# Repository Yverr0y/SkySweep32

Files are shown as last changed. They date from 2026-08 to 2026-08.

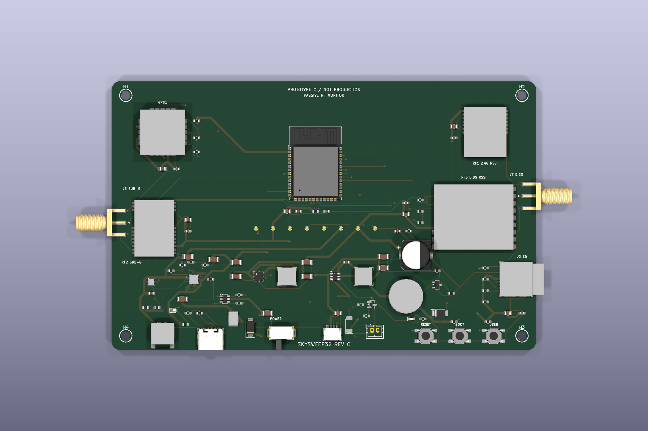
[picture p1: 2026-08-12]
hardware/rev_c/previews/pcb_top.png

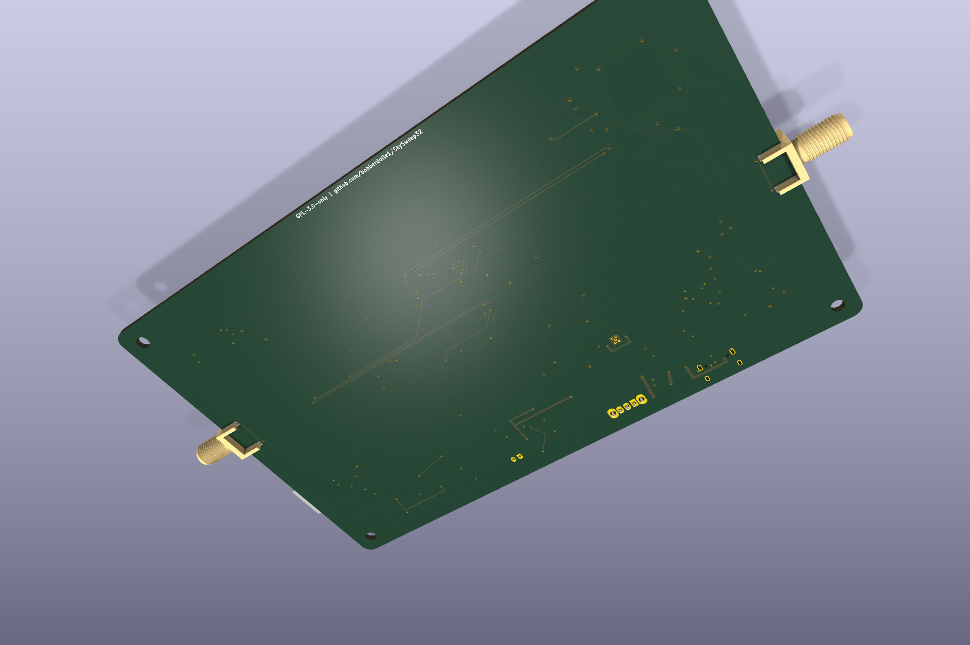
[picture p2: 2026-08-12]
hardware/rev_c/previews/pcb_bottom.png

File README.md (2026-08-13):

# SkySweep32




**Open-source passive multi-band RF monitoring system** — 855–925 MHz, 2.4 GHz,
and 5.8 GHz energy/activity observation; GNSS; microSD logging; local display,
web UI, and networked experiments.

> **Current maturity: READY FOR FIRST PHYSICAL PROTOTYPE — NOT PRODUCTION VALIDATED.**
> Rev C is the current hardware. No Rev C board has been physically assembled,
> bench-tested, RF-characterized, compliance-tested, or field-tested.

SkySweep32 is a **system**, not merely a PCB: passive RF frontends feed an
ESP32-S3 acquisition core; the core drives local logging, GNSS, UI, alerts, web
access, and experimental node events. It does not jam, inject RF, deny GPS,
identify transmitters from RSSI, or provide directional finding.

## Quick links

| Start here | What it answers |
| --- | --- |
| [Get started](docs/en/getting-started.md) · [Начало работы](docs/ru/getting-started.md) | Build the only active firmware target; avoid historical assets |
| [Build Rev C](BUILD_THIS.md) | Exact manufacturing, assembly, and prototype-evidence route |
| [System](docs/en/system.md) · [Система](docs/ru/system.md) | Implemented, experimental, and roadmap capabilities |
| [Current hardware](docs/en/hardware.md) · [Аппаратура](docs/ru/hardware.md) | Rev C PCB, enclosure, manifest, and boundaries |
| [Software](docs/en/software.md) · [Прошивка](docs/ru/software.md) | RF monitoring, logging, UI, protocol parsers, networking |
| [Validation](docs/en/validation.md) · [Валидация](docs/ru/validation.md) | CAD/build evidence versus physical proof |
| [Roadmap](docs/en/roadmap.md) · [План](docs/ru/roadmap.md) | Evidence-driven next work |

## Current system

```text
855–925 MHz / 2.4 GHz / 5.8 GHz passive inputs
             ↓ relative energy/activity
        ESP32-S3 Rev C core
  ┌──────────┼─────────────────────────────┐
  GNSS   microSD logs   OLED/alerts   local Web UI
                    └── ESP-NOW experiments
```

| Capability | Current truth |
| --- | --- |
| Three passive RF observation paths | Implemented in source and Rev C design; RF performance awaits Prototype #1 |
| GNSS, SD logging, OLED, buttons, power telemetry | Implemented in source/design; needs first-board bring-up |
| Wi-Fi web UI, BLE receive, ESP-NOW | Builds; experimental on unassembled Rev C |
| Remote ID, MAVLink, CRSF | Parser/receive infrastructure; no standards or over-air claim |
| LoRa/Meshtastic, TinyML, ATAK, 5.8 video | Not current Rev C capabilities; roadmap only |

## Build and validate

```bash
pio run -e esp32s3_rev_c_passive
make -C test/host
python tools/hardware/verify.py
```

The first two commands exercise source contracts; the hardware command rebuilds
CAD/fabrication checks when its toolchain is available. None proves physical
performance. Follow the [Prototype #1 checklist](hardware/rev_c/PROTOTYPE_VALIDATION_CHECKLIST.md) after assembly.

## Project structure

- `src/` — ESP32-S3 firmware and passive-monitor drivers.
- `hardware/rev_c/` — current canonical KiCad, manifest, fabrication, enclosure, and evidence.
- `tools/hardware/` — reproducible Rev C engineering tools.
- `test/host/` — bounded protocol/parser tests.
- `docs/en/`, `docs/ru/` — product, build, software, validation, and roadmap docs.
- `docs/history/` — deliberately non-orderable Rev A/Rev B context.

## Community and legal boundary

Use [Discussions](https://github.com/bobberdolle1/SkySweep32/discussions) for questions and ideas; use [Issues](https://github.com/bobberdolle1/SkySweep32/issues) for reproducible bugs and Prototype #1 evidence. Operate only under applicable spectrum, privacy, aviation, and data laws. Read [SECURITY.md](.github/SECURITY.md), [CONTRIBUTING.md](CONTRIBUTING.md), and the [GPL-3.0 license](LICENSE).

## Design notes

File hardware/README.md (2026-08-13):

# SkySweep32 Hardware Revisions

## Canonical current design: Rev C

**Rev C status: READY FOR FIRST PHYSICAL PROTOTYPE — NOT PRODUCTION
VALIDATED.**

[`rev_c/`](rev_c/) is the only current hardware source. Its native KiCad 10
schematic and four-layer PCB, exact BOM, generated fabrication package, complete
PCBA STEP, co-designed enclosure, firmware pin contract, and validation evidence
are documented in [`rev_c/README.md`](rev_c/README.md).

Run the complete local gate from the repository root:

```bash
python hardware/verify.py
```

Passing this command establishes encoded ERC/DRC, CAD interference, export, and
firmware-build results. It does not establish an assembled, bench-tested,
field-tested, compliant, or production-validated device.

## Revision authority

| Revision | Status | Use |
|---|---|---|
| [`rev_c/`](rev_c/) | Ready for first physical prototype | Current engineering source and prototype fabrication package |
| [`rev_b/`](rev_b/) | Failed/unverified; do not order | Historical audit evidence only |
| Root-level files / [`enclosures/`](enclosures/) | Legacy Rev A; do not order | Historical issue #10 parser-compatibility artifacts only |

Rev C is electrically, mechanically, and firmware incompatible with Rev A and
Rev B. No legacy pin map, BOM, enclosure, generated report, or manufacturing
file applies to Rev C.

## Historical material

Everything outside `rev_c/` is retained only for historical review:

- [`rev_b/`](rev_b/) documents the failed/unverified Rev B baseline;
- root-level KiCad 6 files, generators, previews, and [`enclosures/`](enclosures/)
  are legacy Rev A / issue #10 parser-compatibility artifacts.

They are **not** part of any Rev C manufacture, assembly, enclosure, pin-map,
or firmware workflow. Do not regenerate them unless investigating history. The
current build path is [`rev_c/BUILD.md`](rev_c/BUILD.md).

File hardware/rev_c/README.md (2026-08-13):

# SkySweep32 Rev C hardware

> **READY FOR FIRST PHYSICAL PROTOTYPE — NOT PRODUCTION VALIDATED.**
> The package below is the only current fabrication/assembly source. Reproduce
> its gates before ordering and then complete the physical validation checklist.

Rev C is a four-layer, 150 × 95 mm passive-monitor carrier around an
ESP32-S3-WROOM-1-N16R8. Fitted receive paths cover 855–925 MHz (E07/CC1101),
2.4 GHz (E28/SX1281), and 5.8 GHz (RX5808 RSSI). It also includes SAM-M10Q
GNSS, microSD, OLED harness, local controls/alerts, USB-C, a protected 1S battery
path, and ESP32-S3 Wi-Fi/BLE/ESP-NOW.

## Build / order route

1. Read [`BUILD.md`](BUILD.md) for exact tools and fabrication/assembly files.
2. Use [`hardware_manifest.json`](hardware_manifest.json) for exact parts,
   footprints, pins, DNP choices, supplier/manufacturer references, and envelopes.
3. Use [`manufacturing/`](manufacturing/) only after reproducing the current
   evidence with [`tools/hardware/verify.py`](../../tools/hardware/verify.py).
4. Follow [`ASSEMBLY_AND_BRINGUP.md`](ASSEMBLY_AND_BRINGUP.md).
5. Do not advance status without every applicable item in
   [`PROTOTYPE_VALIDATION_CHECKLIST.md`](PROTOTYPE_VALIDATION_CHECKLIST.md).

## Canonical sources and derived evidence

| Authority | Files |
| --- | --- |
| Electrical / PCB | `skysweep32_rev_c.kicad_sch`, `skysweep32_rev_c.kicad_pcb` |
| Exact integration contract | `hardware_manifest.json` |
| Firmware pin/profile contract | generated `src/generated/hardware_rev_c.h`, `boards/skysweep32_rev_c.json` |
| Fabrication package | `manufacturing/` |
| Enclosure and assembly geometry | `enclosure/` |
| Machine evidence | `validation/`, regenerated by `tools/hardware/verify.py` |

`3dmodels/*_ENVELOPE.step` are labelled mechanical-envelope approximations unless
the manifest says otherwise. They are fit constraints, not manufacturer CAD proof.

## Validation boundary

Current evidence records zero current ERC errors/warnings, zero DRC violations,
zero unexpected PCB pads, and CAD enclosure collision/service checks. It does
**not** establish charging safety, antenna behavior, RF sensitivity/selectivity,
GNSS performance, USB integrity, enclosure tolerances, reliability, compliance,
or production yield. Those require an assembled board and measurements.

See [`ROADMAP.md`](ROADMAP.md), the root [`BUILD_THIS.md`](../../BUILD_THIS.md),
and [project documentation](../../docs/en/README.md).

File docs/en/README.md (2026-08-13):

# SkySweep32 documentation

SkySweep32 is an open-source **passive multi-band RF monitoring system**. Rev C
is its current physical implementation, not the product definition.

> **Current maturity: READY FOR FIRST PHYSICAL PROTOTYPE.** Rev C has CAD and
> build evidence, but no assembled board, RF characterization, compliance
> result, reliability result, or field result.

## Read in this order

1. [System overview and capability matrix](system.md)
2. [Get started](getting-started.md)
3. [Software and local web UI](software.md)
4. [Current Rev C hardware and enclosure](hardware.md)
5. [Validation and physical-test boundary](validation.md)
6. [Development and contribution](development.md)
7. [Roadmap](roadmap.md)

[Русская документация](../ru/README.md) · [Project website](https://bobberdolle1.github.io/SkySweep32/) · [Source repository](https://github.com/bobberdolle1/SkySweep32)

## Source-of-truth policy

| Fact | Authority | Derived material |
| --- | --- | --- |
| Rev C circuit and geometry | KiCad schematic/PCB plus manufacturer data | fabrication package, STEP, reports |
| Rev C fitted parts and pins | `hardware/rev_c/hardware_manifest.json` | generated firmware header, board definition, BOM |
| Firmware behavior | C++ source built as `esp32s3_rev_c_passive` | binary, local web UI |
| CAD/build evidence | reproducible tools and reports | human summaries |
| Product explanation | these EN/RU documents | website and README links |

A report, render, or successful compile is not proof of RF performance or a
physical prototype result.

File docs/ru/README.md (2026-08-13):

# Документация SkySweep32

SkySweep32 — open-source система **пассивного многодиапазонного RF-мониторинга**.
Rev C — её текущая физическая реализация, а не определение всего проекта.

> **Текущая зрелость: ГОТОВ К ПЕРВОМУ ФИЗИЧЕСКОМУ ПРОТОТИПУ.** Для Rev C есть
> CAD и build-доказательства, но нет собранной платы, RF-характеризации,
> результатов соответствия нормам, надёжности или полевых испытаний.

## Читайте в таком порядке

1. [Система и матрица возможностей](system.md)
2. [Начало работы](getting-started.md)
3. [Прошивка и локальный Web UI](software.md)
4. [Текущая аппаратура Rev C и корпус](hardware.md)
5. [Валидация и граница физических доказательств](validation.md)
6. [Разработка и вклад](development.md)
7. [Дорожная карта](roadmap.md)

[English documentation](../en/README.md) · [Сайт проекта](https://bobberdolle1.github.io/SkySweep32/) · [Исходный репозиторий](https://github.com/bobberdolle1/SkySweep32)

## Политика источников истины

| Факт | Авторитетный источник | Производные материалы |
| --- | --- | --- |
| Схема и геометрия Rev C | KiCad + документация производителей | Gerber, STEP, отчёты |
| Комплектующие и GPIO Rev C | `hardware/rev_c/hardware_manifest.json` | header прошивки, board definition, BOM |
| Поведение прошивки | C++ с `esp32s3_rev_c_passive` | binary, локальный Web UI |
| CAD/build-доказательства | воспроизводимые инструменты и отчёты | текстовые сводки |
| Объяснение продукта | эти EN/RU документы | сайт и README |

Отчёт, рендер или успешная компиляция не являются доказательством RF-параметров
или результата физического прототипа.

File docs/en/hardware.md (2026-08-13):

# Current hardware: Rev C

**READY FOR FIRST PHYSICAL PROTOTYPE — NOT PRODUCTION VALIDATED.** Rev C is the
current physical implementation of the SkySweep32 system. Its electrical and
mechanical architecture is frozen for Prototype #1 unless a demonstrated defect
requires a fix.

- ESP32-S3-WROOM-1-N16R8; native USB-C programming.
- Passive 855–925 MHz E07/CC1101, 2.4 GHz E28/SX1281, and 5.8 GHz RX5808 RSSI paths.
- SAM-M10Q GNSS, microSD, OLED harness, local buttons and alerts.
- USB-C and protected 1S battery path; Wi-Fi/BLE/ESP-NOW via ESP32-S3.
- Four-layer 150 × 95 mm PCB and printed indoor enclosure.

The exact authoritative parts, pin map, fitted/DNP status, power assumptions,
and mechanical envelopes are in the [hardware manifest](../../hardware/rev_c/hardware_manifest.json).
KiCad source defines the manufactured circuit; manufacturer documentation defines
component reality.

## Build and assembly

Use [BUILD_THIS.md](../../BUILD_THIS.md), then the Rev C [build guide](../../hardware/rev_c/BUILD.md) and [assembly/bring-up procedure](../../hardware/rev_c/ASSEMBLY_AND_BRINGUP.md). Use only its fitted BOM and fabrication package.

The enclosure is CAD-checked around the PCBA, battery, display, antennas,
harnesses and service envelopes. It is indoor, not sealed, not IP-rated, and
still needs a first printed-case / physical-assembly check.

Rev A and Rev B are not present in the default-tree build path. Their history is
preserved in [hardware revision history](../history/hardware-revisions.md).

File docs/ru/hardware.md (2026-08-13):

# Текущая аппаратура: Rev C

**ГОТОВ К ПЕРВОМУ ФИЗИЧЕСКОМУ ПРОТОТИПУ — НЕ ПРОИЗВОДСТВЕННО ПРОВЕРЕН.** Rev C
— текущая физическая реализация системы SkySweep32. Его электрическая и
механическая архитектура заморожена для Prototype #1, кроме доказанного defect.

- ESP32-S3-WROOM-1-N16R8 и native USB-C.
- Пассивные тракты E07/CC1101 855–925 МГц, E28/SX1281 2.4 ГГц, RX5808 5.8 ГГц.
- GNSS SAM-M10Q, microSD, OLED harness, локальные кнопки и alerts.
- USB-C и protected 1S battery path; Wi-Fi/BLE/ESP-NOW через ESP32-S3.
- Четырёхслойная PCB 150 × 95 мм и печатный корпус для помещения.

Точные детали, GPIO, fitted/DNP status, power assumptions и mechanical envelopes
определяет [hardware manifest](../../hardware/rev_c/hardware_manifest.json).
KiCad — источник изготовляемой схемы; документация производителя — реальность компонента.

## Сборка и монтаж

Используйте [BUILD_THIS.md](../../BUILD_THIS.md), затем [build guide](../../hardware/rev_c/BUILD.md) и [assembly/bring-up](../../hardware/rev_c/ASSEMBLY_AND_BRINGUP.md). Используйте только fitted BOM и fabrication package Rev C.

Корпус CAD-проверен с PCBA, батареей, дисплеем, антеннами, harness и service
envelopes. Он для помещения, не герметичен, без IP-rating и всё ещё требует
первой печати и реальной сборки.

Rev A и Rev B отсутствуют из пути сборки default branch. История остаётся в
[истории ревизий](../history/hardware-revisions.md).

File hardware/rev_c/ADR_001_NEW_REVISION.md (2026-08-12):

# ADR-001: Replace the published Rev B prototype with Rev C

- **Decision date:** 2026-08-11
- **Status:** Accepted
- **Decision:** Archive Rev B as an abandoned, unverified prototype and create a clean Rev C hardware identity.

## Context

Rev B was published as a distinct four-layer PCB/enclosure redesign and was described by checked-in documents as fully validated. Reproduction with KiCad 10.0.5 instead found 374 PCB DRC violations and 8 ERC warnings. The board source was generated from hard-coded placement, then routed with Freerouting despite placement collisions. Generated rectangular/cylindrical component envelopes were called high-fidelity and the enclosure repeated nominal dimensions rather than consuming and checking the complete PCB assembly. Rev B also mixed development breakouts, an unqualified RX5808 envelope and canonical feature claims that the firmware or physical design could not substantiate.

Replacing the circuit, connector set, module set, pin map, board datum, outline and enclosure while retaining the Rev B name would silently redefine a public revision. It could also make old documentation, photos and community discussions appear applicable to incompatible hardware.

## Decision

Rev B remains in `hardware/rev_b/` solely as historical, non-orderable evidence and carries `EXPERIMENTAL / UNVERIFIED / DO NOT ORDER` warnings. Rev C is the only current canonical hardware once its source files exist. It begins at `CONCEPT` and may advance only through reproducible gates.

Rev C deliberately:

- limits canonical hardware to passive receive/energy observation;
- uses `ESP32-S3-WROOM-1-N16R8`, `E28-2G4M12SX`, `E07-900M10S`,
  `SAM-M10Q-00B`, and Molex `104031-0811` as exact production-intended parts;
- admits only the drawing-qualified `RX5808-2012-12P` envelope and requires
  incoming electrical/mechanical qualification before assembly;
- removes LoRa, GPS, microSD, and OLED development breakouts;
- excludes TinyML, direction finding, and active countermeasures from hardware
  claims;
- uses a single JSON contract for firmware pins, exact parts, assembly items,
  and mechanical datums;
- co-designs a new enclosure from the routed PCBA, protected battery, display,
  antenna, harness, connector, and fastener envelopes rather than inheriting
  Rev B dimensions.

## Consequences

Rev B boards, enclosure parts, and firmware pin maps are incompatible with Rev
C. Rev C now has a first-prototype-only fabrication package after reproducible
ERC, DRC, firmware-build, export, and CAD gates. That package does not advance
the design beyond `READY_FOR_FIRST_PROTOTYPE`; actual assembly, bring-up, RF and
power characterization, tolerance checks, and serviceability tests remain
mandatory.

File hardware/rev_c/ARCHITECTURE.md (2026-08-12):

# SkySweep32 Rev C Architecture

**Status: READY FOR FIRST PHYSICAL PROTOTYPE — NOT PRODUCTION VALIDATED**

## Product definition

Rev C is a passive RF activity monitor and logger for an indoor portable
enclosure. It records channel energy/RSSI observations and received Wi-Fi/BLE
messages. Energy observations do not identify arbitrary emitters. Rev C has no
RF jamming, protocol-injection, GPS-denial, or other active-countermeasure
output.

## Requirements matrix

| Function | Rev C implementation | Evidence before first build | Physical evidence still required |
|---|---|---|---|
| 855–925 MHz | Ebyte `E07-900M10S`, CC1101-compatible SPI, carrier J5 edge-launch SMA | Datasheet pinout, ERC, DRC, routed PCBA STEP | Conducted channel/RSSI sweep with the selected regional antenna |
| 2.4 GHz energy | Ebyte `E28-2G4M12SX` / SX1281 instantaneous RSSI, onboard IPEX/U.FL and Adafruit PID 2308 internal antenna | Ebyte/Semtech pin contract, ERC, DRC, antenna/cable CAD envelope | Register identity, frequency sweep, RSSI response, and enclosure detuning test |
| 5.8 GHz energy | Qualified-envelope `RX5808-2012-12P`, eight hardware-selected channels, analog RSSI, J7 edge-launch SMA | Referenced 12-pad drawing, procurement restriction, ERC, DRC, antenna service envelope | Incoming inspection, pinout confirmation, channel truth table, RSSI response, and Taoglas `TG.59.0113` receive comparison |
| Wi-Fi/BLE | ESP32-S3 dashboard, ESP-NOW, and experimental Remote ID reception | Espressif keepout and firmware build | Reception/coexistence test; standards conformance is not established |
| Position/time | u-blox `SAM-M10Q-00B`, UART NMEA and TIMEPULSE | u-blox land pattern/integration review, ERC, DRC | Live fix, antenna status, and TIMEPULSE measurement |
| UI | Lid-mounted Adafruit PID 326 OLED on PID 4210 JST-SH cable; LED, buzzer, three buttons; optional DNP vibration output | Harness contract, button actuation and cable-length CAD checks | Pixel, button, visibility, buzzer, and repeated lid-service tests |
| Storage | Molex `104031-0811` removable microSD socket with card detect | Manufacturer footprint/model, ERC, DRC, card-removal envelope | Card detect, write/read verification, and repeated insertion |
| Power | USB-C or protected Adafruit PID 328 1S LiPo; BQ24074 power path; TPS61232 5 V boost; AP63203 3.3 V rail | Datasheet circuits, ERC, DRC, encoded 1.35 A peak budget | Current-limited bring-up, charge/power-path, ripple, transient, and thermal tests |
| Programming | ESP32-S3 native USB, BOOT/RESET, UART0 test pads | USB routing/ESD review and firmware build | Enumeration, upload, reconnect, and ESD robustness tests |
| Mechanical | 150 × 95 mm four-layer PCBA in generated two-part enclosure | Full PCBA STEP, battery/display/antenna/cable/fastener/service-envelope checks | First print, first PCBA, tolerance, cable dressing, and serviceability measurements |

The module-based receivers are deliberate first-prototype choices. A direct
multiband RF implementation would require RF characterization and manufacturing
controls that do not yet exist. The RX5808 source is the weakest procurement
item: only a 12-pad, 28 × 23 × 3 mm module matching the referenced drawing is
permitted, and the first received lot must be electrically and mechanically
qualified before assembly.

## Functional architecture

```mermaid
graph TD
    USB[USB-C 5 V / native USB] --> CHG[BQ24074 power path]
    BAT[Protected 1S LiPo] --> CHG
    CHG --> BOOST[TPS61232 fixed 5 V]
    BOOST --> BUCK[AP63203 3.3 V]
    BUCK --> MCU[ESP32-S3-WROOM-1-N16R8]
    BUCK --> RF24[E28-2G4M12SX / SX1281]
    BUCK --> SUB[E07-900M10S / CC1101]
    BOOST --> RX5[RX5808 2012 / analog RSSI]
    BUCK --> GPS[SAM-M10Q-00B]
    BUCK --> SD[Molex microSD]
    MCU -->|shared RF SPI| RF24
    MCU -->|shared RF SPI| SUB
    MCU -->|channel selects + ADC| RX5
    MCU -->|shared SPI, separate CS| SD
    MCU -->|UART + PPS| GPS
    MCU -->|I2C / JST-SH| OLED[Adafruit PID 326]
    MCU --> ALERT[LED + buzzer + optional vibration]
```

## Interface contract

The reviewed signal contract lives in `hardware_manifest.json`; the firmware
header and PlatformIO board definition derive from it. E28 and E07 share
SCK/MOSI/MISO and have independent chip selects. microSD uses the same physical
SPI signals with its own chip select. RX5808 uses three channel-select lines and
an analog RSSI path. GNSS uses UART plus TIMEPULSE. The display is on I2C.

GPIO0 is reserved for BOOT. GPIO3, GPIO45, and GPIO46 carry no peripheral load.
GPIO19/20 remain native USB. GPIO35–37 are reserved because the selected
`ESP32-S3-WROOM-1-N16R8` uses octal PSRAM. Substituting another ESP32-S3 module
variant requires a new schematic, pin-map, firmware, and layout review.

## Power architecture

USB VBUS is protected by the `MF-MSMF200-2` resettable fuse and `SMAJ5.0A` TVS;
USB D+/D− use `USBLC6-2SC6`. The `BQ24074RGTR` is configured for an 800 mA charge
current and 1.3 A input limit with a fixed 10 kΩ/10 kΩ battery-temperature
window. Use only the specified protected Adafruit PID 328 / LP785060 pack with
the documented JST-PH polarity.

`TPS61232DRCR` generates the switched 5 V system rail. `AP63203WU-7` generates
3.3 V through the reviewed `SRN6028-3R9M` inductor/application network. The
manifest's 1.35 A peak estimate covers ESP32 radio bursts, all three receiver
paths, GNSS acquisition, microSD writes, display/alerts, and margin. IC ratings
do not establish usable continuous current or thermal margin; both rails and the
charge/power-path behavior require first-board measurement.

## RF interpretation limits

- E28/SX1281 RSSI is channel energy, not protocol or transmitter identity.
- E07/CC1101 RSSI is relative activity within the configured 855–925 MHz range;
  Rev C must not issue a 433 MHz configuration.
- RX5808 analog RSSI is limited to the documented eight channel selections. Its
  module source and calibration remain unverified until incoming inspection and
  bench characterization.
- ESP32 Wi-Fi/BLE Remote ID reception remains experimental until tested against
  known conforming transmitters and a standards-conformance suite.

## Mechanical rules

The lower-left PCB corner is the shared datum. Mounting holes, 5 mm radial
fastener/boss keepouts, USB-C, microSD, both edge-launch SMA connectors, three
buttons, status LED, OLED, protected battery, and internal 2.4 GHz antenna are
manifest-defined interfaces. The enclosure generator consumes the complete PCBA
STEP and checks:

- base/lid/PCBA/OLED/battery/fastener/button collisions;
- USB cable, microSD card, SMA plug, and external antenna service volumes;
- closed and 30 mm-open OLED and internal-antenna cable routes against their
  exact 100 mm cable limits;
- battery-to-PCBA and floor clearances;
- button travel to switch contact.

Passing these checks means the modeled solids satisfy the encoded constraints.
It does not establish printed tolerances, connector mating force, antenna
performance, or physical serviceability.

## Source-of-truth hierarchy

1. Manufacturer datasheets and mechanical drawings define physical reality.
2. The reviewed KiCad schematic and PCB define the circuit and manufactured
   geometry.
3. `hardware_manifest.json` defines cross-domain exact MPNs, feature scope,
   firmware pins, board datum, assembly items, and mechanical interfaces.
4. Firmware headers, PlatformIO metadata, BOM/placement exports, reports,
   renders, enclosure derivatives, and manufacturing files are generated
   evidence, not independent design authority.
5. Narrative documentation describes those sources and never overrides failing
   machine evidence.

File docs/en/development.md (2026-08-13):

# Development and contributing

SkySweep32 welcomes firmware, RF-measurement, mechanical, documentation, and
localization contributions. Read [CONTRIBUTING.md](../../CONTRIBUTING.md) before
opening a pull request.

## Local checks
```bash
make -C test/host
cppcheck --enable=warning --inline-suppr \
  --suppress=missingInclude --suppress=missingIncludeSystem \
  --std=c++11 -DBOARD_SKYSWEEP32_REV_C -DPROFILE_PASSIVE_MONITOR \
  -I src -I src/drivers -I src/protocols --error-exitcode=1 src
python tools/development/verify_prototype1_security.py
pio run -e esp32s3_rev_c_passive
```

Use WSL for the sanitizer-backed host suite on Windows; see
[`test/host/README.md`](../../test/host/README.md). CAD contributors use
`python tools/hardware/verify.py` after a genuine electrical or mechanical
change.

## Scope discipline

Do not add active RF interference, source-identification claims from RSSI, or
placeholder ML features. Do not change Rev C for cosmetic reasons before
Prototype #1 measurements. Preserve a clear distinction between source that
builds and behavior verified on physical hardware.

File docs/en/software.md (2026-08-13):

# Firmware, logging, UI, and networking

The product firmware is C++ in `src/`; its canonical PlatformIO environment is
`esp32s3_rev_c_passive`. The hardware manifest generates the pin/profile header
before each build.

## Runtime subsystems

- `main.cpp`: explicit Rev C boot sequence and FreeRTOS tasks.
- `drivers/`: CC1101, SX1281 and RX5808 receive-control paths.
- `activity_classifier.*`: normalized energy/activity presentation; no identity inference.
- `gps_module.*`, `data_logger.*`, `power_manager.*`: GNSS, logs and portable-power state.
- `web_server.*` plus `dashboard.html`: local dashboard/API.
- `espnow_mesh.*`: local SkySweep32 event sharing; range/coexistence need tests.
- `remote_id_detector.*`: retained experimental BLE parser; disabled in the
  canonical build pending defensible multi-transmitter association tests.
- `protocols/`: CRSF and MAVLink bounded parsers. They are not wired proof of over-air protocol reception.

## Logging and web UI

The web server and microSD logger consume local receiver activity and device
state. Logs may contain sensitive location or receiver information; collect,
store, and share them lawfully. The AP password is per-device, generated on
first boot, and is never returned by a GET API. Dashboard/status telemetry is
read-only for AP clients; configuration, power changes, and logs require
`admin` plus that password. Network changes persist and require reboot; Rev C
supports AP mode only. USB is the only Prototype #1 update route—there is no
OTA endpoint.

## Networking boundary

ESP-NOW is the only current node-to-node transport path. It shares coarse events
without claiming source identity. LoRa/Meshtastic compatibility is not implemented
for Rev C; an external transport is a future design decision, not a feature toggle.

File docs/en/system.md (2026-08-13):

# System architecture and capability matrix

```text
RF environment
  └─ fitted passive frontends: 855–925 MHz · 2.4 GHz · 5.8 GHz
       ↓ relative RSSI / activity observations
ESP32-S3 core
  ├─ acquisition and activity processing
  ├─ GNSS timing/position
  ├─ microSD logging
  ├─ OLED, buttons, buzzer and vibration output
  ├─ local Wi-Fi web UI and BLE receive path
  └─ ESP-NOW event sharing
       ↓
OLED · SD logs · local web UI · alerts · networked activity events
```

Optional future directions are node correlation, an external LoRa-class
transport, 5.8 GHz video experiments, and evidence-backed ML. None is a Rev C
production capability.

## Current truth matrix

| Area | Source state | Physical evidence | Public status |
| --- | --- | --- | --- |
| 855–925 MHz | builds; CC1101 activity samples at 860/890/920 MHz | none | requires prototype RF characterization |
| 2.4 GHz | builds; SX1281 RSSI sweep | none | energy/activity only |
| 5.8 GHz | builds; RX5808 channels and analog RSSI | none | incoming module check and bench response required |
| GNSS, microSD, OLED, controls, battery | source + Rev C contract | no board | requires physical bring-up |
| Wi-Fi web UI, ESP-NOW | source builds | no Rev C run/range test | unique per-device AP; management/log authorization; experimental on Rev C |
| Remote ID | retained BLE parser source | no association/conformance fixture or hardware test | experimental code disabled by default |
| MAVLink / CRSF | host-tested bounded parsers | no Rev C demodulated input | parser infrastructure only |
| ATAK, LoRa/Meshtastic, TinyML, 5.8 video | no current product path | none | roadmap only |

SkySweep32 is passive. It does not jam, inject, deny GPS, direction-find, or
identify transmitters from RSSI/activity alone.

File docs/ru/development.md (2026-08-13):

# Разработка и вклад

SkySweep32 принимает firmware, RF-measurement, mechanical, documentation и
localization вклад. До pull request прочитайте [CONTRIBUTING.md](../../CONTRIBUTING.md).

## Локальные проверки
```bash
make -C test/host
cppcheck --enable=warning --inline-suppr \
  --suppress=missingInclude --suppress=missingIncludeSystem \
  --std=c++11 -DBOARD_SKYSWEEP32_REV_C -DPROFILE_PASSIVE_MONITOR \
  -I src -I src/drivers -I src/protocols --error-exitcode=1 src
python tools/development/verify_prototype1_security.py
pio run -e esp32s3_rev_c_passive
```

В Windows используйте WSL для sanitizer-backed host suite; см.
[`test/host/README.md`](../../test/host/README.md). Для изменения CAD запустите
`python tools/hardware/verify.py` после реального электрического или механического изменения.

## Дисциплина scope

Не добавляйте active RF interference, claims identity по RSSI или placeholder ML.
Не меняйте Rev C ради внешнего вида до измерений Prototype #1. Сохраняйте чёткую
границу между тем, что собирается, и тем, что доказано на физическом оборудовании.

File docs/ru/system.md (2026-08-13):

# Архитектура системы и матрица возможностей

```text
RF-среда
  └─ установленные пассивные тракты: 855–925 МГц · 2.4 ГГц · 5.8 ГГц
       ↓ относительные RSSI / наблюдения активности
Ядро ESP32-S3
  ├─ сбор и обработка активности
  ├─ GNSS-время/позиция
  ├─ журналирование microSD
  ├─ OLED, кнопки, зуммер и вибровыход
  ├─ локальный Wi-Fi Web UI и BLE-приём
  └─ обмен событиями ESP-NOW
       ↓
OLED · SD-журналы · локальный Web UI · оповещения · сетевые события
```

Будущие направления: корреляция узлов, внешний LoRa-class transport, эксперименты
с видео 5.8 ГГц и ML, подтверждённый данными. Это не производственные возможности Rev C.

## Текущая матрица истины

| Область | Состояние исходников | Физические доказательства | Публичный статус |
| --- | --- | --- | --- |
| 855–925 МГц | собирается; CC1101 на 860/890/920 МГц | нет | нужна RF-характеризация прототипа |
| 2.4 ГГц | собирается; RSSI-обзор SX1281 | нет | только энергия/активность |
| 5.8 ГГц | собирается; RX5808 и аналоговый RSSI | нет | нужен входной и стендовый контроль |
| GNSS, microSD, OLED, кнопки, батарея | исходники + контракт Rev C | платы нет | нужен физический запуск |
| Wi-Fi Web UI, ESP-NOW | исходники собираются | запуска/дальности Rev C нет | уникальный AP на устройство; authorization управления/logs; экспериментально на Rev C |
| Remote ID | сохранённый BLE parser | нет association/conformance fixture или hardware test | экспериментальный код отключён по умолчанию |
| MAVLink / CRSF | host-тесты ограниченных parser | нет демодулированного входа Rev C | только parser infrastructure |
| ATAK, LoRa/Meshtastic, TinyML, 5.8 video | текущего product path нет | нет | только roadmap |

SkySweep32 пассивен: он не создаёт помехи, не внедряет данные, не глушит GPS, не
пеленгует и не определяет передатчик по одному RSSI/activity.

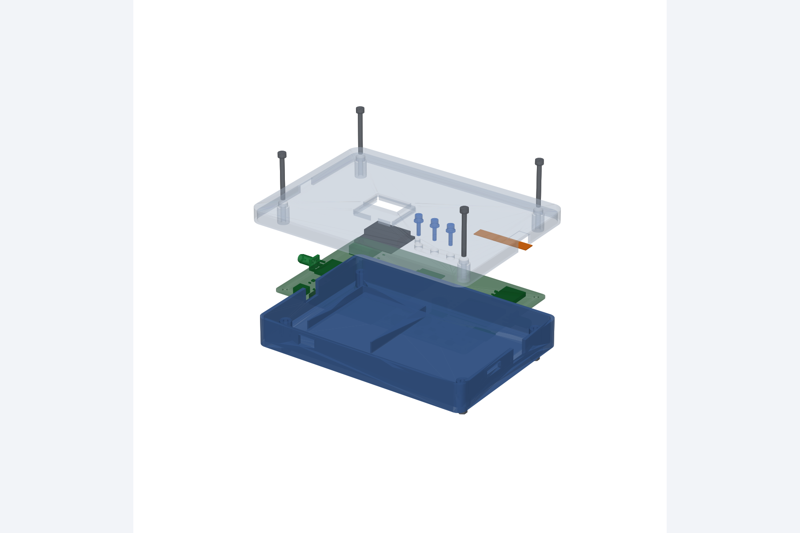
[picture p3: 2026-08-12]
hardware/rev_c/previews/enclosure_exploded.png

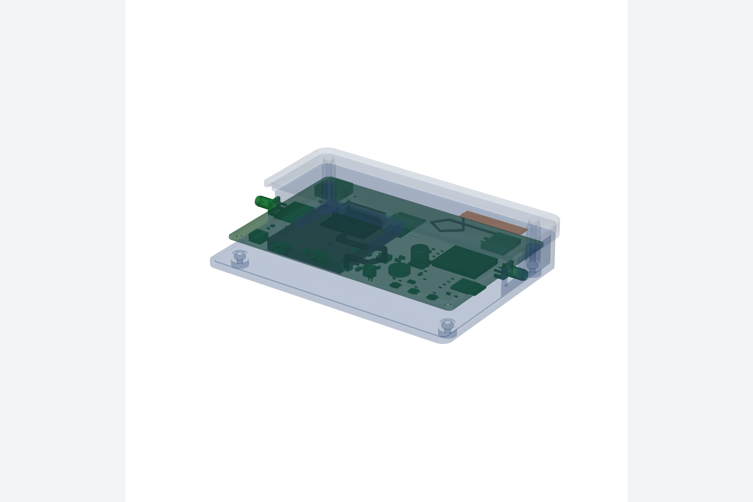
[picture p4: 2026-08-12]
hardware/rev_c/previews/enclosure_cutaway.png

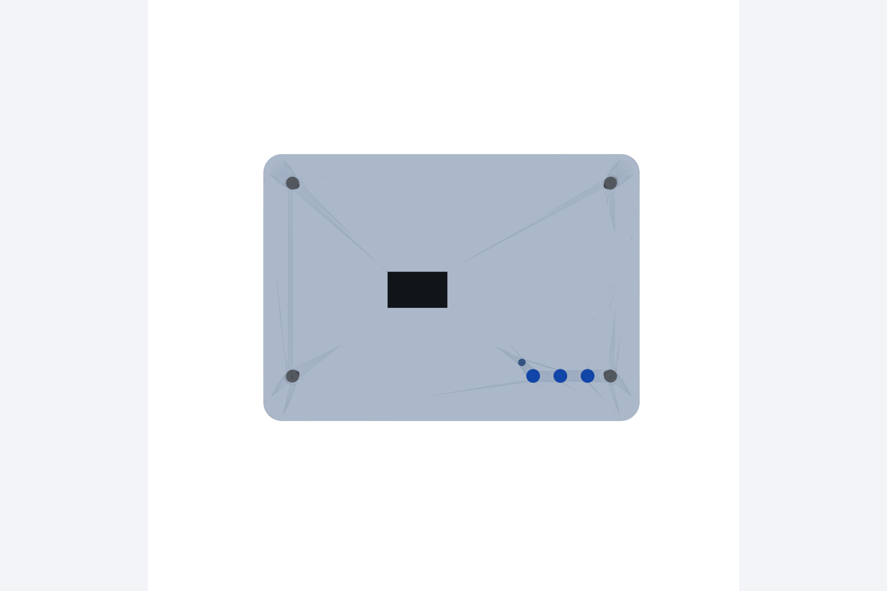
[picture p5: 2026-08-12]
hardware/rev_c/previews/enclosure_top.png

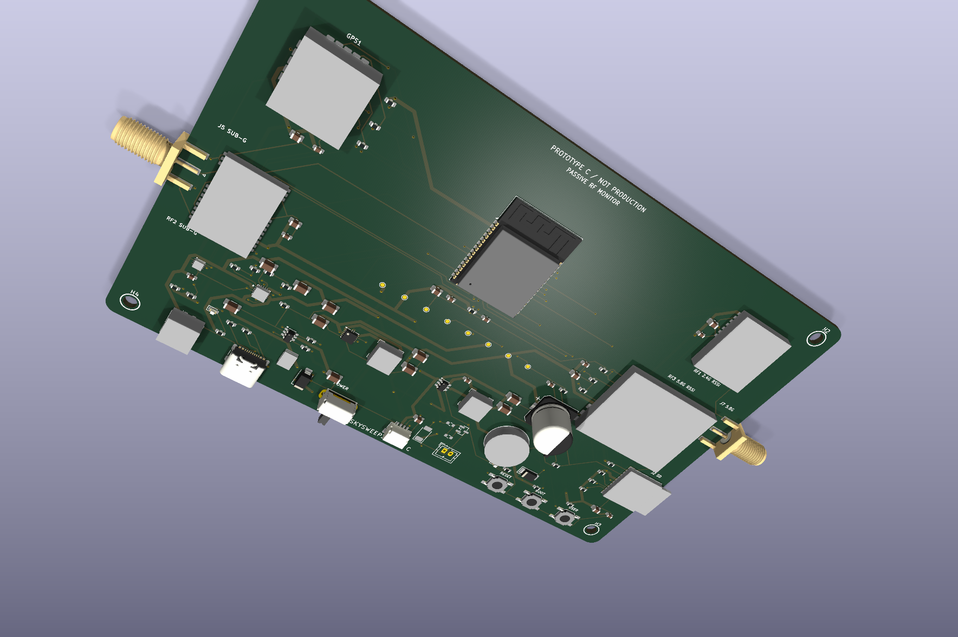
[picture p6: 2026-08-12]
hardware/rev_c/previews/pcb_iso.png

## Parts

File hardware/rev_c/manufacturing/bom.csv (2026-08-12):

Refs | Value | Footprint | Manufacturer | MPN | Qty | DNP
BZ1 | CMT-1203-SMT-TR | SkySweep32RevC:Buzzer_CUI_CMT_1203_SMT_TR | CUI Devices | CMT-1203-SMT-TR | 1
C1,C17-C19 | 10u | Capacitor_SMD:C_1206_3216Metric | Murata | GRM31CR61A106KA01L | 4
C2,C6,C9,C11,C13,C15,C24,C29 | 100n | Capacitor_SMD:C_0603_1608Metric | Murata | GRM188R71E104KA01D | 8
C3,C4,C20-C23 | 22u | Capacitor_SMD:C_1206_3216Metric | Murata | GRM31CR61A226ME15L | 6
C5,C8,C10,C12,C14,C16,C25 | 10u | Capacitor_SMD:C_0805_2012Metric | Murata | GRM21BR61A106KE19L | 7
C7 | 1u | Capacitor_SMD:C_0603_1608Metric | Murata | GRM188R61A105KA61D | 1
C26 | 470u 10V | Capacitor_SMD:CP_Elec_10x10 | Panasonic | EEE-FK1A471P | 1
C30 | 10n | Capacitor_SMD:C_0603_1608Metric | Murata | GRM188R71H103KA01D | 1
D1 | SMAJ5.0A | Diode_SMD:D_SMA | Littelfuse | SMAJ5.0A | 1
D2 | PMEG3020EP | Diode_SMD:D_SOD-128 | Nexperia | PMEG3020EP,115 | 1
D3 | GREEN | LED_SMD:LED_0603_1608Metric | Kingbright | APT1608LZGCK | 1
D4 | PMEG3020EP | Diode_SMD:D_SOD-128 | Nexperia | PMEG3020EP,115 | 1 | yes
D5 | CHARGE | LED_SMD:LED_0603_1608Metric | Kingbright | APT1608LZGCK | 1
F1 | MF-MSMF200-2 | Fuse:Fuse_1812_4532Metric | Bourns | MF-MSMF200-2 | 1
GPS1 | SAM-M10Q-00B | SkySweep32RevC:Module_UBlox_SAM_M10Q | u-blox AG | SAM-M10Q-00B | 1
J1 | USB4105-GF-A | Connector_USB:USB_C_Receptacle_GCT_USB4105-xx-A_16P_TopMnt_Horizontal | GCT | USB4105-GF-A | 1
J2 | Molex 104031-0811 | Connector_Card:microSD_HC_Molex_104031-0811 | Molex | 104031-0811 | 1
J3 | OLED STEMMA QT | Connector_JST:JST_SH_SM04B-SRSS-TB_1x04-1MP_P1.00mm_Horizontal | JST | SM04B-SRSS-TB(LF)(SN) | 1
J4 | OPTIONAL VIBRATION MOTOR | Connector_JST:JST_PH_B2B-PH-K_1x02_P2.00mm_Vertical | JST | B2B-PH-K-S(LF)(SN) | 1 | yes
J5 | SUB-GHZ SMA | Connector_Coaxial:SMA_Amphenol_132289_EdgeMount | Amphenol RF | 132289 | 1
J6 | BATTERY — ADAFRUIT PID 328 | Connector_JST:JST_PH_S2B-PH-SM4-TB_1x02-1MP_P2.00mm_Horizontal | JST | S2B-PH-SM4-TB(LF)(SN) | 1
J7 | 5.8-GHZ SMA | Connector_Coaxial:SMA_Amphenol_132289_EdgeMount | Amphenol RF | 132289 | 1
L1 | 3.9uH SRN6028-3R9M | Inductor_SMD:L_Bourns-SRN6028 | Bourns | SRN6028-3R9M | 1
L2 | 1uH SRN6028C-1R0Y | Inductor_SMD:L_Bourns-SRN6028 | Bourns | SRN6028C-1R0Y | 1
Q1 | AO3400A | Package_TO_SOT_SMD:SOT-23 | Alpha & Omega Semiconductor | AO3400A | 1
Q2 | AO3400A | Package_TO_SOT_SMD:SOT-23 | Alpha & Omega Semiconductor | AO3400A | 1 | yes
R1,R2 | 5.1k | Resistor_SMD:R_0603_1608Metric | Yageo | RC0603FR-075K1L | 2
R3,R4 | 22R | Resistor_SMD:R_0603_1608Metric | Yageo | RC0603FR-0722RL | 2
R5-R8,R20 | 10k | Resistor_SMD:R_0603_1608Metric | Yageo | RC0603FR-0710KL | 5
R9,R10 | 0R | Resistor_SMD:R_0603_1608Metric | Yageo | RC0603JR-070RL | 2
R11-R14 | 47k | Resistor_SMD:R_0603_1608Metric | Yageo | RC0603FR-0747KL | 4
R15 | 100R | Resistor_SMD:R_0603_1608Metric | Yageo | RC0603FR-07100RL | 1
R16,R28-R30 | 100k | Resistor_SMD:R_0603_1608Metric | Yageo | RC0603FR-07100KL | 4
R17,R31 | 1k | Resistor_SMD:R_0603_1608Metric | Yageo | RC0603FR-071KL | 2
R18 | 100R | Resistor_SMD:R_0603_1608Metric | Yageo | RC0603FR-07100RL | 1 | yes
R19 | 100k | Resistor_SMD:R_0603_1608Metric | Yageo | RC0603FR-07100KL | 1 | yes
R21 | 46.4k | Resistor_SMD:R_0603_1608Metric | Yageo | RC0603FR-0746K4L | 1
R22 | 1.13k | Resistor_SMD:R_0603_1608Metric | Yageo | RC0603FR-071K13L | 1
R23 | 1.18k | Resistor_SMD:R_0603_1608Metric | Yageo | RC0603FR-071K18L | 1
R24 | 4.12k | Resistor_SMD:R_0603_1608Metric | Yageo | RC0603FR-074K12L | 1
R25 | 1.5k | Resistor_SMD:R_0603_1608Metric | Yageo | RC0603FR-071K5L | 1
R26,R27 | 4.7k | Resistor_SMD:R_0603_1608Metric | Yageo | RC0603FR-074K7L | 2
RF1 | E28-2G4M12SX | SkySweep32RevC:Module_Ebyte_E28_2G4M12SX | Chengdu Ebyte Electronic Technology | E28-2G4M12SX | 1
RF2 | E07-900M10S | SkySweep32RevC:Module_Ebyte_E07_900M10S | Chengdu Ebyte Electronic Technology | E07-900M10S | 1
RF3 | RX5808-2012-12P | SkySweep32RevC:Module_RX5808_2012_12P | Multi-source legacy module | RX5808-2012-12P | 1
SW1 | RESET | Button_Switch_SMD:SW_SPST_SKQG_WithoutStem | Alps Alpine | SKQGABE010 | 1
SW2 | BOOT | Button_Switch_SMD:SW_SPST_SKQG_WithoutStem | Alps Alpine | SKQGABE010 | 1
SW3 | USER | Button_Switch_SMD:SW_SPST_SKQG_WithoutStem | Alps Alpine | SKQGABE010 | 1
SW4 | SYSTEM POWER | Button_Switch_THT:SW_Slide_SPDT_Angled_CK_OS102011MA1Q | C&K | OS102011MA1QN1 | 1
TP1 | VBUS_PROTECTED | TestPoint:TestPoint_Pad_D1.0mm |  |  | 1 | yes
TP2 | 3V3 | TestPoint:TestPoint_Pad_D1.0mm |  |  | 1 | yes
TP3 | GND | TestPoint:TestPoint_Pad_D1.0mm |  |  | 1 | yes
TP4 | UART0_TX | TestPoint:TestPoint_Pad_D1.0mm |  |  | 1 | yes
TP5 | UART0_RX | TestPoint:TestPoint_Pad_D1.0mm |  |  | 1 | yes
TP6 | BAT_CELL | TestPoint:TestPoint_Pad_D1.0mm |  |  | 1 | yes
TP7 | SYS_5V | TestPoint:TestPoint_Pad_D1.0mm |  |  | 1 | yes
TP8 | RX5808_RSSI_ADC | TestPoint:TestPoint_Pad_D1.0mm |  |  | 1 | yes
U1 | ESP32-S3-WROOM-1-N16R8 | RF_Module:ESP32-S3-WROOM-1 | Espressif Systems | ESP32-S3-WROOM-1-N16R8 | 1
U2 | USBLC6-2SC6 | Package_TO_SOT_SMD:SOT-23-6 | STMicroelectronics | USBLC6-2SC6 | 1
U3 | AP63203WU-7 | Package_TO_SOT_SMD:TSOT-23-6 | Diodes Incorporated | AP63203WU-7 | 1
U4 | BQ24074RGTR | Package_DFN_QFN:VQFN-16-1EP_3x3mm_P0.5mm_EP1.6x1.6mm | Texas Instruments | BQ24074RGTR | 1
U5 | TPS61232DRCR | Package_SON:Texas_S-PVSON-N10_ThermalVias | Texas Instruments | TPS61232DRCR | 1
U6 | MAX17048G+T10 | Package_DFN_QFN:DFN-8-1EP_2x2mm_P0.5mm_EP0.9x1.3mm | Analog Devices | MAX17048G+T10 | 1

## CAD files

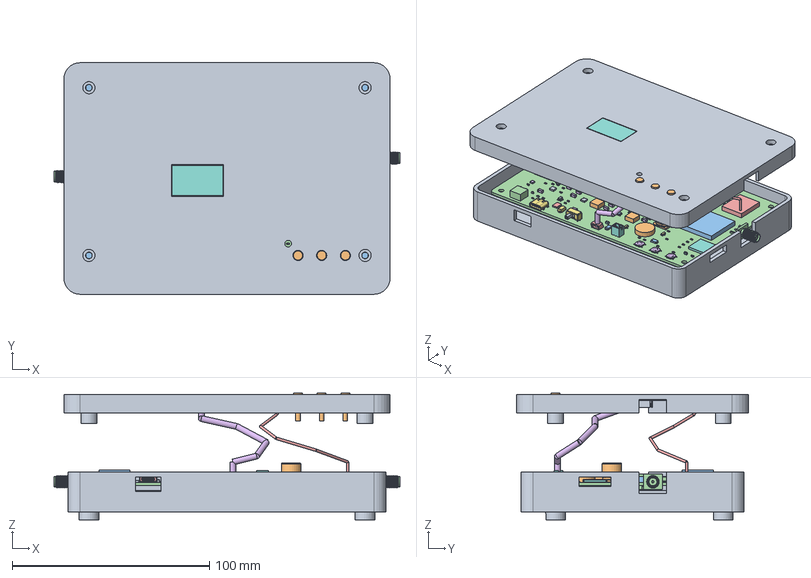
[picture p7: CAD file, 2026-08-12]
hardware/rev_c/enclosure/skysweep32_rev_c_open_assembly.step
175.4 x 117.4 x 64.2 mm

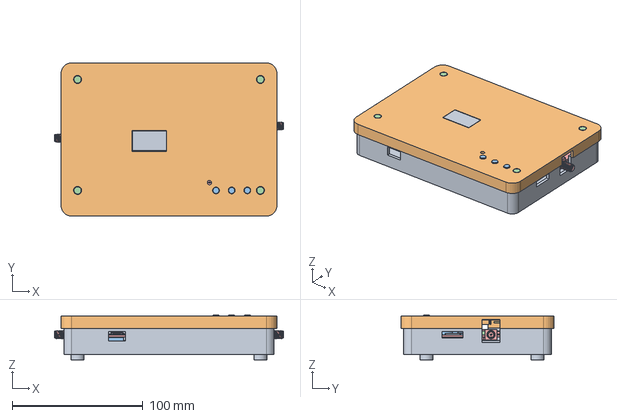
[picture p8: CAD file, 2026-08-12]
hardware/rev_c/enclosure/skysweep32_rev_c_closed_assembly.step
175.4 x 117.4 x 34.2 mm

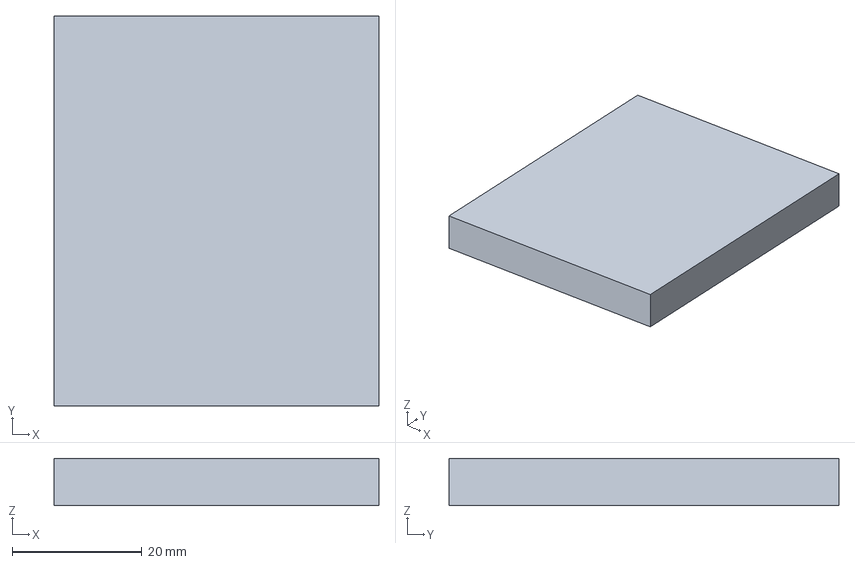
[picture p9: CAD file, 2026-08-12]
hardware/rev_c/3dmodels/Adafruit_PID328_LP785060_BATTERY_ENVELOPE.step
50.0 x 60.0 x 7.30 mm

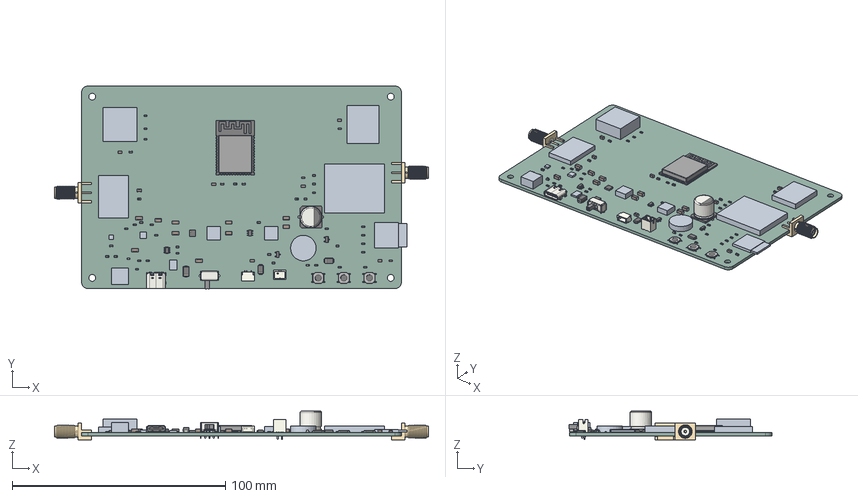
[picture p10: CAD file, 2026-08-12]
hardware/rev_c/skysweep32_rev_c_pcba.step
175.4 x 95.2 x 13.6 mm
TSOT-23-6
R_0603_1608Metric x 31
C_1206_3216Metric x 10
D_SMA
C_0603_1608Metric x 10
USB_C_Receptacle_16P_TopMnt_Horizontal_GCT_USB4105-xx-A
C_0805_2012Metric x 7
LED_0603_1608Metric x 2
CP_Elec_10x10
D_SOD-128 x 2
SMA_Amphenol_132289_EdgeMount x 2
JST_SH_SM04B-SRSS-TB_1x04-1MP_P1.00mm_Horizontal
SOT-23 x 2
JST_B2B_PH_K
SOT-23-6
ESP32-S3-WROOM-1
SW_Slide_SPDT_Angled_CK_OS102011MA1Q
SW_SPST_SKQG_WithoutStem x 3
Texas_S_PVSON_N10
skysweep32_rev_c_PCB

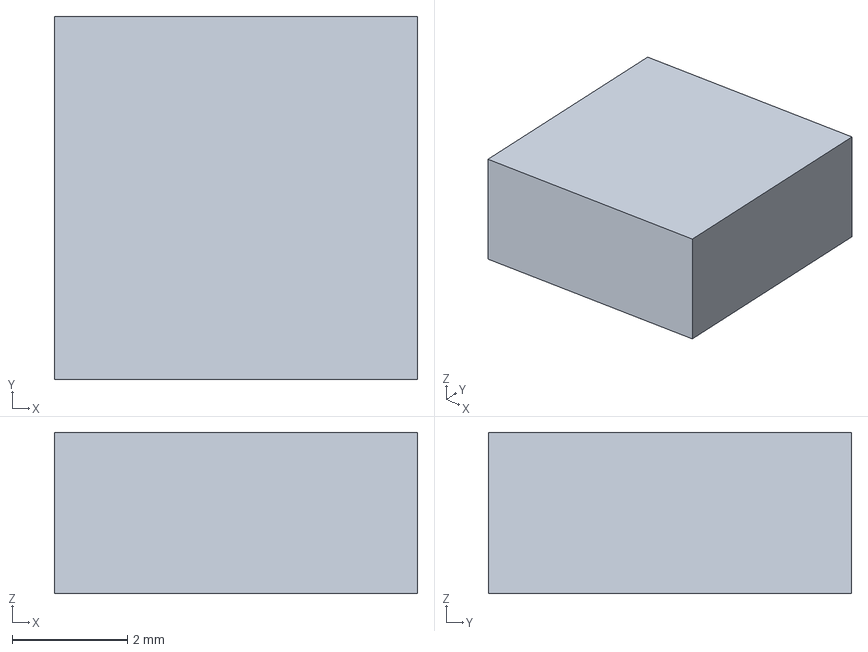
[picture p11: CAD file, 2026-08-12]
hardware/rev_c/3dmodels/Bourns_SRN6028C_1R0Y_ENVELOPE.step
6.30 x 6.30 x 2.80 mm

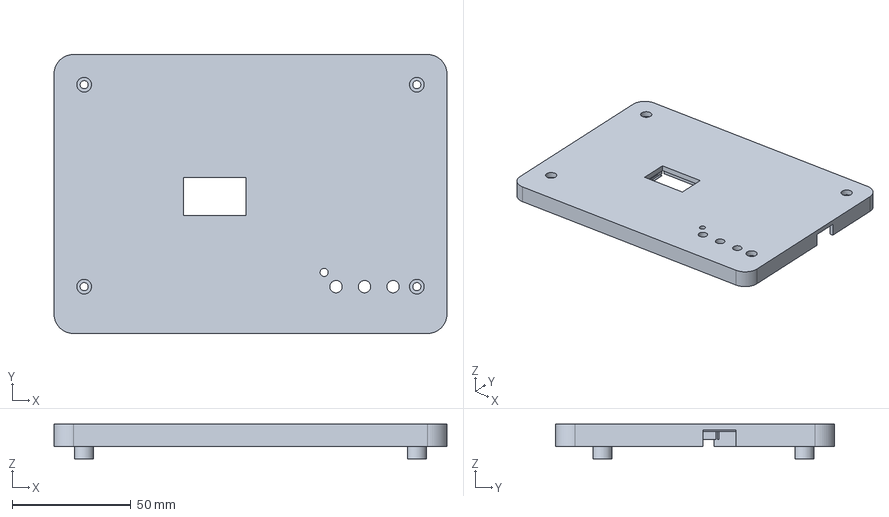
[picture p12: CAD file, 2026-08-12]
hardware/rev_c/enclosure/skysweep32_rev_c_lid.step
165.4 x 117.4 x 14.6 mm

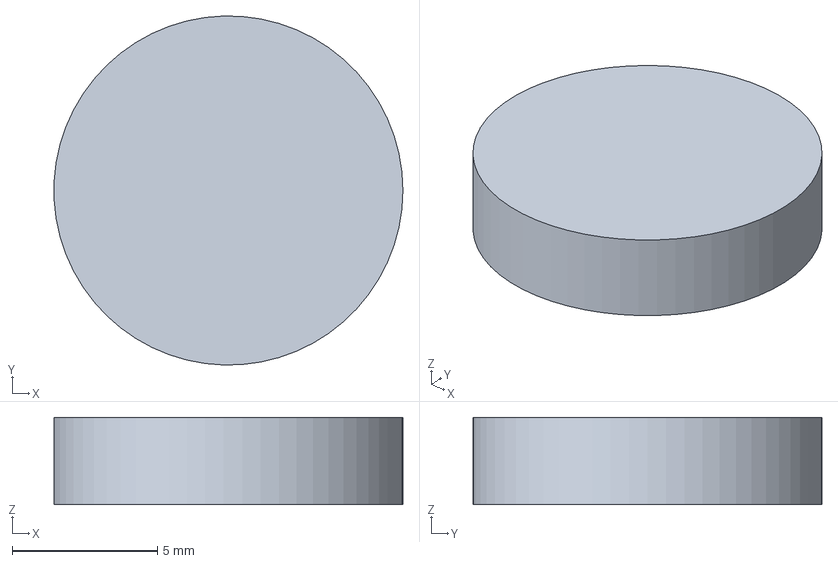
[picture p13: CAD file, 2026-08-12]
hardware/rev_c/3dmodels/CUI_CMT_1203_SMT_TR_ENVELOPE.step
12.0 x 12.0 x 3.00 mm

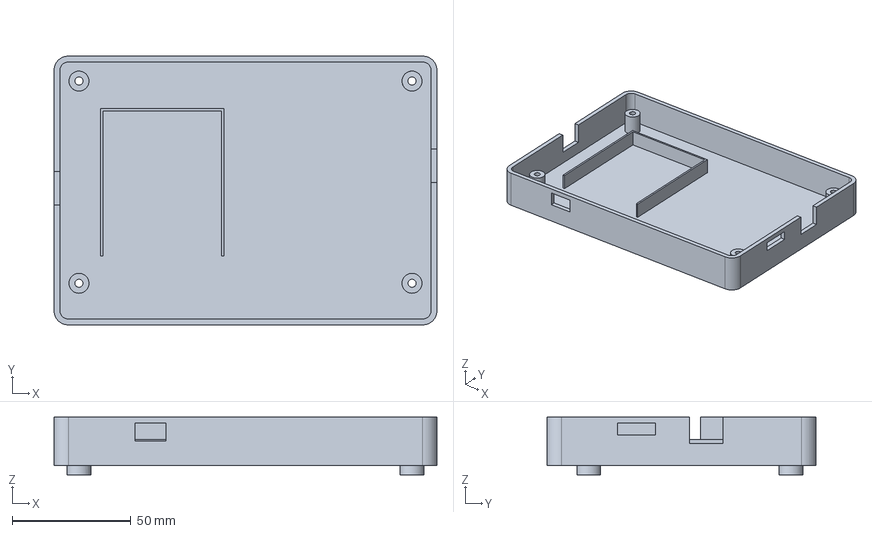
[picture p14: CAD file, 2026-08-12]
hardware/rev_c/enclosure/skysweep32_rev_c_base.step
161.0 x 113.0 x 24.3 mm

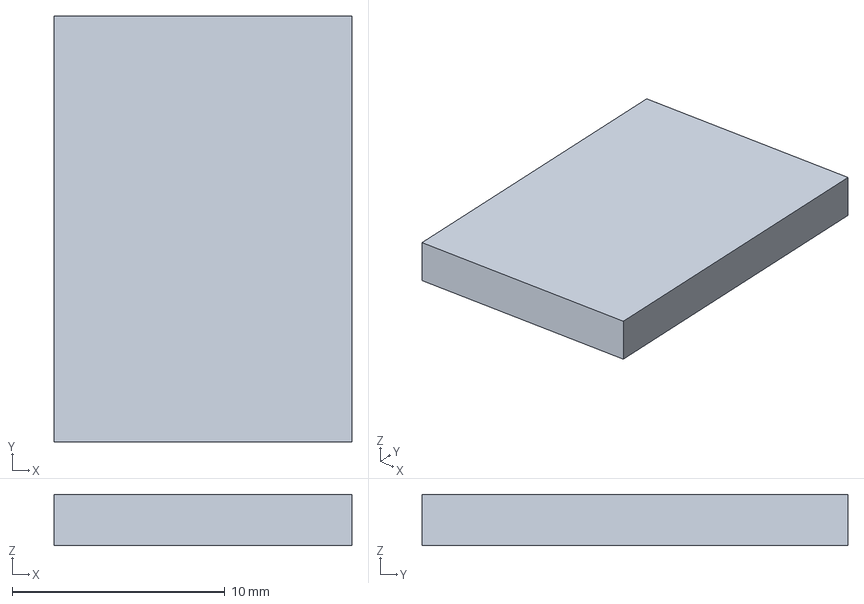
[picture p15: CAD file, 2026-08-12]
hardware/rev_c/3dmodels/Ebyte_E07_900M10S_ENVELOPE.step
14.0 x 20.0 x 2.40 mm

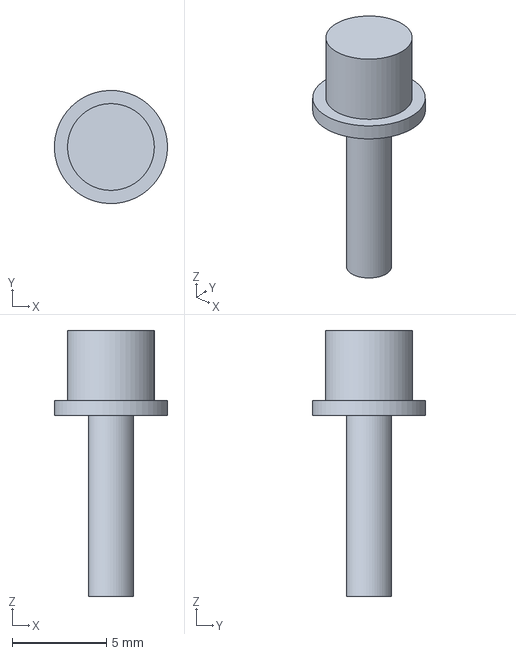
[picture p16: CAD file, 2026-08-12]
hardware/rev_c/enclosure/skysweep32_rev_c_button.step
5.99 x 6.00 x 14.1 mm

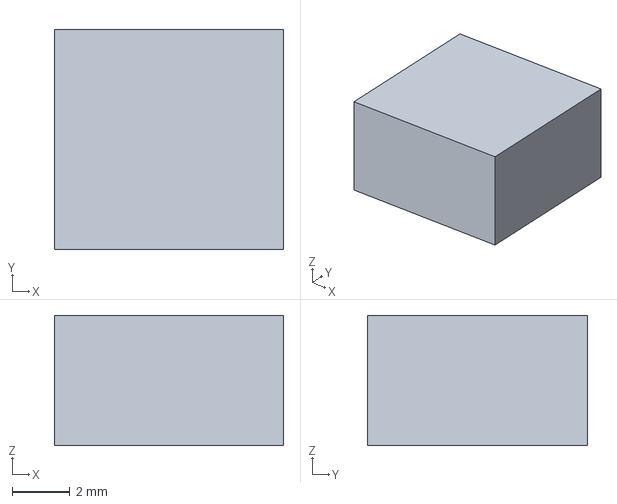
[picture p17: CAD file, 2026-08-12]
hardware/rev_c/3dmodels/JST_S2B_PH_SM4_TB_ENVELOPE.step
7.90 x 7.60 x 4.50 mm

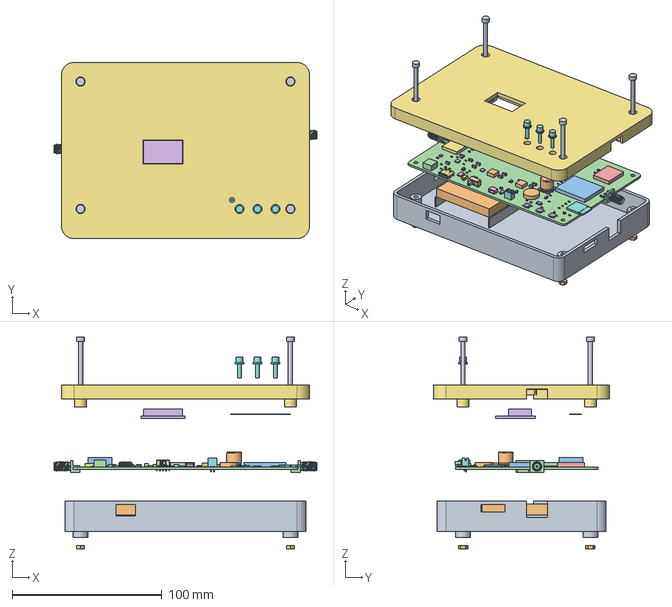
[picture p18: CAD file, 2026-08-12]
hardware/rev_c/enclosure/skysweep32_rev_c_exploded.step
175.4 x 117.4 x 141.2 mm

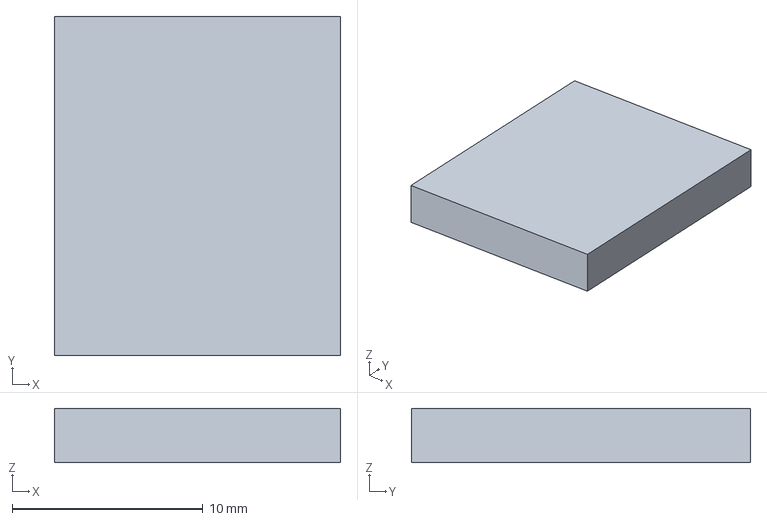
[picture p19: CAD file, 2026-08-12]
hardware/rev_c/3dmodels/Ebyte_E28_2G4M12SX_ENVELOPE.step
15.0 x 17.8 x 2.85 mm

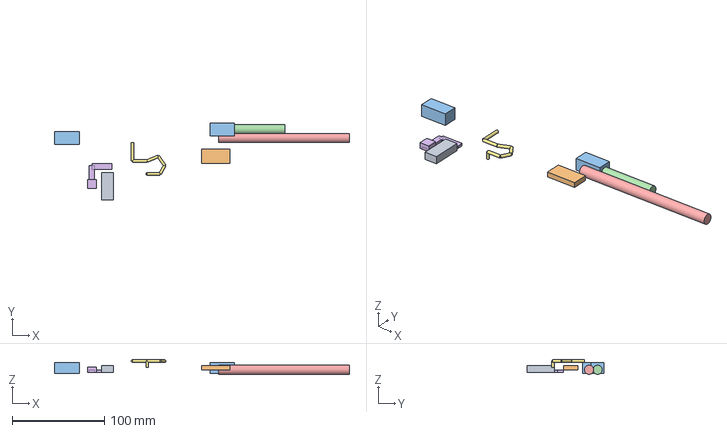
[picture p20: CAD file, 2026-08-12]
hardware/rev_c/enclosure/skysweep32_rev_c_service_envelopes.step
320.3 x 83.9 x 16.0 mm

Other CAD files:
hardware/rev_c/3dmodels/Bourns_SRN6028_3R9M_ENVELOPE.step
hardware/rev_c/3dmodels/Bourns_MF_MSMF200_2_ENVELOPE.step
hardware/rev_c/enclosure/skysweep32_rev_c_cutaway.step
hardware/rev_c/3dmodels/ADI_MAX17048_TDFN8_ENVELOPE.step
hardware/rev_c/3dmodels/Adafruit_OLED_PID326_ENVELOPE.step
hardware/rev_c/3dmodels/Molex_104031_0811_WITH_CARD_ENVELOPE.step
hardware/rev_c/3dmodels/RX5808_2012_12P_ENVELOPE.step
hardware/rev_c/3dmodels/TI_BQ24074_RGT_ENVELOPE.step
hardware/rev_c/3dmodels/UBlox_SAM_M10Q_ENVELOPE.step
hardware/rev_c/enclosure/skysweep32_rev_c_base.stl
hardware/rev_c/enclosure/skysweep32_rev_c_button.stl
hardware/rev_c/enclosure/skysweep32_rev_c_lid.stl

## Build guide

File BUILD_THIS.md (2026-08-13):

# Build the current SkySweep32

This is the short route for the only current hardware/firmware combination:
**SkySweep32 Rev C passive monitor**.

> **READY FOR FIRST PHYSICAL PROTOTYPE — NOT PRODUCTION VALIDATED.** Reproduce
> the checks below before fabrication. A successful check does not replace
> Prototype #1 electrical, RF, mechanical, or compliance evidence.

## 1. Inspect the exact hardware package

Read [`hardware/rev_c/BUILD.md`](hardware/rev_c/BUILD.md). It is the canonical
order/assembly route, including the fitted BOM, Gerbers, drill data, assembly
items, enclosure, bringing-up procedure, and physical validation checklist.

Do not use Rev A/Rev B assets or the historical `v0.6.1` binaries.

## 2. Reproduce design evidence

```bash
python tools/development/generate_rev_c_pinmap.py --check
python tools/development/generate_dashboard.py --check
python tools/hardware/rev_c/verify_schematic_parity.py
python tools/development/verify_documented_commands.py
python tools/development/verify_prototype1_security.py
python tools/hardware/verify.py
```

The last command requires KiCad 10 and FreeCAD. It recreates engineering
artifacts from native sources; it is not a physical validation claim.

## 3. Build firmware

```bash
pio run -e esp32s3_rev_c_passive
make -C test/host
```

After an actual assembled-board bring-up, upload with:

```bash
pio run -e esp32s3_rev_c_passive --target upload
```

## 4. Record prototype evidence

Run every applicable item in
[`hardware/rev_c/PROTOTYPE_VALIDATION_CHECKLIST.md`](hardware/rev_c/PROTOTYPE_VALIDATION_CHECKLIST.md).
Record measurements, setup, raw logs, photographs, firmware SHA, and failures in
the hardware-build issue template. Do not relabel Rev C as production-validated
until that evidence exists.

For architecture, features, and software, start at [`docs/en/README.md`](docs/en/README.md) or [`docs/ru/README.md`](docs/ru/README.md).

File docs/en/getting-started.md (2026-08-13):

# Get started

## Firmware

Install PlatformIO, clone the repository, then build the only active target:

```bash
pio run -e esp32s3_rev_c_passive
pio run -e esp32s3_rev_c_passive --target upload
```

Do **not** flash the GitHub `v0.6.1` assets onto Rev C. Those historical binaries
used unrelated ESP32 DevKit wiring. No Rev C binary release exists yet.

## Hardware

Use the root [build route](../../BUILD_THIS.md) and the exact Rev C
[build guide](../../hardware/rev_c/BUILD.md). It links the fitted BOM, Gerbers,
assembly items, enclosure, bring-up procedure, and physical validation checklist.

Rev C is an engineering prototype package, not a production order. Before any
purchase, reproduce the documented design checks. After assembly, record the
required power, RF, GNSS, storage, display, network, and enclosure evidence.

## Local web UI

At first boot—or the first boot after a factory reset—the firmware generates a
unique WPA2 AP password, stores it in SPIFFS, and shows the AP SSID/password on
the OLED and USB serial console. Later boots reuse the stored credential.

The dashboard and status telemetry are readable to clients admitted to that AP.
Management configuration, power policy, and SD logs require HTTP Basic
authentication: username `admin`, password = that per-device AP password.
`POST /api/config` persists changes for the next reboot; Rev C currently
supports AP mode only. Remote ID code is retained but **disabled by default**;
it is experimental and not a standards claim. USB is the only Prototype #1
firmware update route; there is no network OTA endpoint.

## Questions and bugs

Ask questions or propose ideas in [GitHub Discussions](https://github.com/bobberdolle1/SkySweep32/discussions). File reproducible defects as [Issues](https://github.com/bobberdolle1/SkySweep32/issues). Use the hardware-build template for physical measurements and photos.

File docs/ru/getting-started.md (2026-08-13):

# Начало работы

## Прошивка

Установите PlatformIO, клонируйте репозиторий и соберите единственную активную цель:

```bash
pio run -e esp32s3_rev_c_passive
pio run -e esp32s3_rev_c_passive --target upload
```

**Не прошивайте Rev C** файлами `v0.6.1` с GitHub. Это исторические binary для
другой разводки ESP32 DevKit. Готового Rev C binary release пока нет.

## Аппаратная часть

Откройте корневой [маршрут сборки](../../BUILD_THIS.md), затем точное
[руководство Rev C](../../hardware/rev_c/BUILD.md). Там есть BOM, Gerber,
assembly items, корпус, bring-up и чек-лист физических испытаний.

Rev C — пакет инженерного прототипа, не серийный заказ. До закупки воспроизведите
документированные design checks. После сборки зафиксируйте измерения питания, RF,
GNSS, storage, UI, сети и корпуса.

## Локальный Web UI

При первом запуске — или первом запуске после factory reset — прошивка создаёт
уникальный WPA2 пароль AP, сохраняет его в SPIFFS и показывает SSID/пароль на
OLED и в USB serial. При следующих запусках используются сохранённые данные.

Dashboard и status telemetry доступны клиентам, уже подключённым к AP.
Управление config, power policy и SD logs требует HTTP Basic: пользователь
`admin`, пароль = индивидуальный пароль AP. `POST /api/config` сохраняет
изменения для следующей перезагрузки; Rev C пока поддерживает только AP mode.
Код Remote ID сохранён, но **отключён по умолчанию**, экспериментален и не
является заявлением о соответствии стандарту. Обновление Prototype #1 —
только USB; сетевого OTA endpoint нет.

## Вопросы и ошибки

Вопросы и идеи — в [GitHub Discussions](https://github.com/bobberdolle1/SkySweep32/discussions). Воспроизводимые defects — в [Issues](https://github.com/bobberdolle1/SkySweep32/issues). Для измерений и фото прототипа используйте hardware-build template.

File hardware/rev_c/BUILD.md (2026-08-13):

# Build SkySweep32 Rev C

**Status: READY FOR FIRST PHYSICAL PROTOTYPE — NOT PRODUCTION VALIDATED.**

This is the sole fabrication path for Rev C. Do not combine these files with
Rev A, Rev B, a `v0.6.1` binary, or an ESP32 DevKit wiring guide.

## What to order

1. Fabricate `manufacturing/skysweep32_rev_c_gerbers.zip` as a **150 × 95 mm,
   four-layer** board: 1.6 mm finished FR-4, ENIG, 35 µm copper, 0.20 mm
   minimum spacing and drill. Use the stackup in [README.md](README.md).
2. Request 90 Ω USB D+/D− and 50 Ω J5/J7 launches, field-solved against the
   actual fabricator stackup. A supplier geometry change requires a fresh
   impedance and DRC review.
3. Assemble only `manufacturing/bom_fitted.csv` and
   `manufacturing/positions.csv`. `bom.csv` contains intentional DNP items.
4. Order non-PCB items from `manufacturing/assembly_items.csv`. Fit **one** J5
   regional antenna variant, not both.
5. Print the base, lid, and button STLs under `enclosure/`; use the specified
   Adafruit OLED, cable, battery, and internal antenna in the manifest.

`manufacturing/fabrication_manifest.json` records the checked fabrication-file
hashes. It does not certify a supplier output or an assembled board.

## Required checks before purchase

From the repository root, with the pinned tools in `tools/hardware/toolchain.json`:

```bash
python tools/development/generate_rev_c_pinmap.py --check
python tools/development/generate_dashboard.py --check
python tools/hardware/rev_c/verify_schematic_parity.py
python tools/hardware/verify.py
python tools/development/verify_documented_commands.py
python tools/development/verify_prototype1_security.py
```

The first command proves that the human-readable hierarchy preserves the
reviewed pre-hierarchy reference/pin/net contract. The full verifier runs ERC,
DRC, PCBA/enclosure checks, manufacturing export, and the canonical firmware
build. A pass remains CAD/build evidence only.

## Assemble and power safely

Follow [ASSEMBLY_AND_BRINGUP.md](ASSEMBLY_AND_BRINGUP.md) in order:

- inspect the bare board before assembly;
- inspect power-path soldering and RX5808 lot/pinout before fitting it;
- begin at 5.00 V and a 100 mA current limit with battery, antennas, OLED, and
  microSD disconnected;
- stop on a hard short, rail outside 5%, rapid heating, or unexpected current;
- only then test native USB, controls, each peripheral, battery behavior, RF
  response, and enclosure serviceability.

Record results in [PROTOTYPE_VALIDATION_CHECKLIST.md](PROTOTYPE_VALIDATION_CHECKLIST.md).
A completed build may advance maturity only when the corresponding measured
results and raw evidence are reviewed into the repository.

## Firmware

Rev C firmware is source-built only:

```bash
pio run -e esp32s3_rev_c_passive
pio run -e esp32s3_rev_c_passive --target upload
pio device monitor --baud 115200
```

The historical `v0.6.1` binaries target legacy ESP32 DevKit wiring and **must
not** be flashed onto Rev C.

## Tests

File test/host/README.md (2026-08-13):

# Host unit tests

Desktop-compiled unit tests for the pure-logic protocol parsers
(`src/protocols/crsf_parser.cpp`, `src/protocols/mavlink_parser.cpp`).

These parsers decode **attacker-controlled RF input**, so they are the highest-value
code to test for memory safety. They depend only on fixed-width integer types and
`memcpy`/`memset`, so they build against the tiny [`Arduino.h`](Arduino.h) stub in
this directory with any desktop compiler — **no ESP32 toolchain or PlatformIO
registry required**.

## Run

```bash
make -C test/host
```

This compiles the real parser sources with **AddressSanitizer + UndefinedBehaviorSanitizer**
and runs the suite. Any out-of-bounds read/write on a malformed frame aborts the
process, so the "malicious frame" cases double as overflow regression guards.

### Windows

Use a Linux-hosted compiler through WSL so the suite retains its ASan/UBSan
coverage:

```powershell
wsl -d Ubuntu-24.04 -- bash -lc "cd /mnt/f/Projects/skysweep32/test/host && g++ --version && make clean && make"
```

The command requires Ubuntu's `build-essential` package. Native MinGW toolchains
can compile these sources, but their sanitizer runtimes are not consistently
available; do not silently drop the sanitizer flags to substitute that result.

Coverage includes:

- CRSF: hostile length bytes (`0xFE`/`0xFF`) and over-max payloads are rejected
  without overflowing the 60-byte payload buffer; known-good receive fixtures
  validate CRC handling and field offsets.
- MAVLink: a valid heartbeat fixture parses; a maximum 255-byte-payload frame
  validates without length wrap; message IDs lacking a known CRC_EXTRA entry
  and truncated frames are rejected; `parseHeartbeat` zero-initializes on short
  payloads.
- Field helpers: a known-good CRSF RC-channel fixture validates 11-bit
  unpacking, and the CRSF/MAVLink GPS + heartbeat `parse*` helpers decode full
  payloads correctly while returning zeroed structs on short (out-of-bounds)
  payloads.
- Fuzz: ~460k random and adversarial frames (valid sync + random length byte,
  hitting every boundary incl. `0xFE`/`0xFF`) fed to both parsers — the
  sanitizers turn any out-of-bounds access into a hard failure. Deterministic
  (seeded xorshift), runs in well under a second.

CI runs the same command via [`.github/workflows/host-tests.yml`](../../.github/workflows/host-tests.yml).

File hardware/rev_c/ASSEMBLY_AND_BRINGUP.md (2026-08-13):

# Rev C First-Prototype Assembly and Bring-Up

## Scope and safety

This procedure is for the first engineering prototype only. Rev C has passed
encoded ERC/DRC and CAD checks but has not been physically powered. Use an ESD
workstation, current-limited bench supply or current-limited USB fixture,
multimeter, oscilloscope, USB protocol-capable host, and thermal camera or
contact probe. Do not connect antennas or transmit during initial rail tests.

## PCB procurement

Use only the files in [`manufacturing/`](manufacturing/). Send the fabricator:

- `skysweep32_rev_c_gerbers.zip`;
- both PTH and NPTH drill files from `gerbers/` if the supplier does not accept
  the zip as-is;
- `bom_fitted.csv` and `positions.csv` for assembly;
- `assembly_top.svg` and `assembly_bottom.svg` for zoomable placement and
  orientation review;
- `assembly_drawing.pdf` and `schematic.pdf` for manufacturing review.

Specify 150 × 95 mm, four-layer FR-4, 1.6 mm finished thickness, ENIG, 35 µm
finished copper, minimum 0.20 mm spacing, minimum 0.20 mm finished drill, and the
stackup documented in [`README.md`](README.md). Require the fabricator to
field-solve the USB 90 Ω differential pair and the J5/J7 50 Ω launches against
its actual materials. Any geometry change requires new DRC and impedance review.

Do not substitute major parts by package appearance. Check every quoted MPN
against `bom_fitted.csv`. `bom.csv` also contains intentional DNP parts and is
not the assembly order list. Choose exactly one regional J5 antenna from
`assembly_items.csv`.

## Assembly order

1. Inspect bare-board dimensions, layer count, finish, edge launches, USB
   connector edge, microSD opening, and all four Ø3.2 mm mounting holes.
2. Assemble bottom-side SMT parts first, then top-side SMT parts. Follow the
   component rotations in `positions.csv`; do not infer pin 1 from renderings.
3. Inspect the BQ24074, TPS61232, and AP63203 power loops; USBLC6-2SC6
   orientation; SAM-M10Q center pad; E28/E07/RX5808 castellations; microSD socket
   coplanarity; USB-C shell joints; and J5/J7 ground tabs under magnification.
4. Reject any RX5808 module that is not the documented 12-pad
   28 × 23 × 3 mm pattern. Record its supplier, lot, markings, dimensions, and
   pin-to-function continuity before fitting it.
5. Fit remaining board-edge and connector hardware without forcing alignment.
   J5 and J7 must remain coplanar with their intended enclosure openings.
6. Leave the battery, microSD card, OLED harness, internal U.FL antenna, external
   SMA antennas, and enclosure disconnected for initial power tests.
7. Clean flux only with materials approved for the fitted components and
   sockets. Dry completely before resistance tests.

## Unpowered checks

Record all values in the prototype checklist.

1. Visual inspection: no solder bridges, tombstones, reversed polarized parts,
   unsoldered exposed pads, damaged connectors, or debris under modules.
2. Verify continuity from USB shell to chassis/shield network and confirm it is
   not accidentally shorted to a signal pad.
3. Measure resistance between TP1 `VBUS_PROTECTED` and TP3 `GND`, then TP2
   `3V3` and TP3. A hard short is a stop condition. Do not use an arbitrary
   resistance pass threshold without allowing capacitors to charge; record the
   stabilized readings and investigate values below 10 Ω.
4. Verify no continuity between USB D+ and D−, or either data line and VBUS/GND.
5. Verify BOOT, RESET, and USER switches are normally open to their active nets
   and close only when pressed.

## Current-limited first power

1. Feed 5.00 V through a USB-C breakout/fixture with D+/D− disconnected. Start at
   a 100 mA current limit.
2. Confirm TP1 reaches approximately 5 V and TP2 rises toward 3.3 V. If the
   supply limits, a rail is outside 5%, or any part heats rapidly, remove power.
3. Raise the limit to 300 mA only after the first observation passes. Measure
   TP1, TP2, regulator switch-node behavior, input current, and regulator/module
   temperatures after 60 s.
4. Raise the limit to 1.5 A only when firmware starts exercising radios, GNSS,
   SD, display, and alerts. Rev C's calculated peak is 1.35 A; unexpected
   sustained current or regulator temperature must be investigated, not
   normalized in documentation.
5. Capture 3V3 ripple and transient droop at TP2 while each high-current module
   is enabled. Record oscilloscope bandwidth limit, probe method, and load state.

## USB and firmware

1. Connect a known-good USB-C data cable. Confirm ESP32-S3 ROM/CDC enumeration.
2. Hold BOOT, tap RESET, then release BOOT if manual download mode is needed.
3. Build and upload only the canonical profile:

   ```bash
   pio run -e esp32s3_rev_c_passive
   pio run -e esp32s3_rev_c_passive --target upload
   pio device monitor --baud 115200
   ```

4. Record the firmware commit, binary hash, USB VID/PID, boot log, reset reason,
   and whether native USB remains stable through ten reconnect cycles.
5. Verify RESET, BOOT, USER, status LED, and buzzer. The optional vibration parts
   are DNP and must not be marked passed unless intentionally assembled.

## Peripheral checks

Perform one function at a time before combined operation.

- **OLED:** connect Adafruit PID 326 using the keyed Adafruit PID 4210 cable;
  verify orientation before power. Check every pixel region and lid alignment.
- **microSD:** insert a known FAT32 card, verify card detect, create/read/verify a
  file, remove/reinsert ten times, and confirm the card clears the case opening.
- **GNSS:** use open sky, log time to first fix, NMEA validity, reported antenna
  status if available, and TIMEPULSE at TP/MCU input.
- **2.4 GHz module:** attach Adafruit PID 2308 directly to the E28 module's
  onboard IPEX/U.FL connector before an RF response test.
  Verify E28/SX1281 register identity, configured frequencies, and instantaneous
  RSSI response at multiple controlled levels. RSSI is energy, not protocol or
  transmitter identity.
- **855–925 MHz module:** fit the exact regional J5 antenna from
  `assembly_items.csv`. Verify CC1101 register identity, channel tuning, RSSI
  response, and spurious behavior with shielded/attenuated equipment. Do not
  command 433 MHz.
- **5.8 GHz module:** fit Taoglas `TG.59.0113` to J7. Verify the RX5808
  three-bit channel truth table, all eight expected frequencies
  (5645–5945 MHz), analog RSSI monotonicity, noise floor, and adjacent-channel
  behavior with a controlled attenuated source.
- **Wi-Fi/BLE:** verify receive/web functions without claiming Remote ID
  conformance. Standards conformance requires separate captured-frame tests.

## Battery and power-path checks

Do these only after USB-only bring-up is stable.

1. Verify the battery pack label, protection circuit, JST-PH housing orientation,
   and polarity against Adafruit PID 328 before insertion. Reverse polarity is a
   stop condition.
2. With USB absent, connect the protected pack and verify BQ24074 power-path
   startup, 5 V boost, 3.3 V rail, quiescent current, and firmware fuel-gauge
   reading. Do not infer state of charge from voltage alone.
3. Apply USB through a current-limited fixture. Record input current, charge
   current, pack voltage, system-rail droop, and temperatures at the beginning,
   middle, and charge termination. Confirm the configured 800 mA charge current
   and 1.3 A input limit are not exceeded within measurement tolerance.
4. Remove and restore USB under representative system load. Confirm the system
   transfers between USB and battery without reset or rail excursion outside the
   allowed range.
5. Stop on swelling, pack heating, connector heating, unstable switching, or
   charging behavior inconsistent with the BQ24074 configuration.

## Enclosure assembly

1. Print base, lid, and three button plungers from the checked-in STLs. Start
   with PETG, 0.20 mm layers, four perimeters, and 30% infill. Deburr openings
   without changing functional dimensions.
2. Check four DIN 934 M3 nuts fit the traps without splitting the base. Install
   them before the PCB.
3. Confirm the bare PCB lowers onto all four supports without force and every
   connector aligns. Remove it before installing electronics if this fit fails.
4. Place the protected PID 328 battery in the lower bay with the lead toward J6.
   Confirm 0.5 mm modeled floor clearance, free lead bend, no screw/nut contact,
   and no preload before fitting the PCBA.
5. Fit the PCBA. Connect Adafruit PID 2308 directly to the E28 module's onboard
   IPEX/U.FL connector and attach its 40 × 8 mm element to the marked
   underside-lid location. Dress the cable along the checked route; do not kink
   it, cross an RF keepout, or load the connector.
6. Snap Adafruit PID 326 into the lid cradle and connect the PID 4210 cable.
   Dress both 100 mm cables only within the checked service-loop corridors. The
   antenna route uses 94.96 mm closed / 90.62 mm at 30 mm lid opening
   (5.04 / 9.38 mm slack); the OLED route uses 92.60 / 89.14 mm
   (7.40 / 10.86 mm slack). Keep each loop outside antenna keepouts, button
   travel, fasteners, and connector openings.
7. Insert the three plungers from the outside. Confirm each returns freely and
   operates only its corresponding switch.
8. Lower the lid vertically while watching the battery, OLED, and antenna
   cables. Install four DIN 912 M3 × 30 screws gradually in a diagonal pattern.
   Tighten only enough to seat the lid; printed plastic is not a
   torque-qualified joint.
9. Fit exactly one regional J5 antenna
   (`ANT-868-CW-HWR-SMA` or `ANT-916-CW-HWR-SMA`) and Taoglas `TG.59.0113` to
   J7 from outside. Confirm both hinged bodies rotate without striking the case
   or blocking USB-C/microSD access.
10. Repeat USB insertion, card removal, button operation, LED visibility, lid
    opening by 30 mm, battery removal, and RF connector access. Record any CAD
    or print modification needed for fit; do not hand-correct a print and then
    call the checked CAD valid.

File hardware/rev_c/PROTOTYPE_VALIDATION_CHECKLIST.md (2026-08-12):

# Rev C Physical Prototype Validation Checklist

**Prototype serial:** __________  **PCB lot:** __________  **Assembly lot:** __________

**Hardware commit:** __________  **Firmware commit:** __________  **Date:** __________

**Operator / equipment IDs:** ________________________________________________

A generated report cannot complete this checklist. Attach photographs, raw logs,
scope captures, RF analyzer files, measurements, failures, and rework history.
Mark each item `PASS`, `FAIL`, or `N/A` with a reason. Any failed safety, rail,
USB, RF, or mechanical-service item blocks advancement beyond
`READY_FOR_FIRST_PROTOTYPE`.

## A. Incoming and assembly

| ID | Observable contract | Result / evidence |
|---|---|---|
| A1 | PCB is 150.0 × 95.0 × 1.6 mm within supplier tolerance; four layers and ENIG verified from lot documents | |
| A2 | Four Ø3.2 mm holes and 140 × 85 mm pattern measured | |
| A3 | Impedance coupon/report records USB 90 Ω differential and J5/J7 50 Ω results, or deviations are documented | |
| A4 | Fitted parts match every manufacturer/MPN row in `bom_fitted.csv`; substitutions listed and reviewed | |
| A5 | RX5808 supplier, lot, markings, 12-pad pattern, 28 × 23 × 3 mm envelope, and pin-function checks recorded before fitting | |
| A6 | X-ray/optical inspection covers BQ24074, TPS61232, AP63203, SAM-M10Q, USB ESD, E28/E07/RX5808, microSD, USB-C, J5, and J7 | |
| A7 | No shorts on VBUS_PROTECTED, SYS_5V, 3V3, BAT_CELL, USB D+/D−, or adjacent fine-pitch pins | |
| A8 | DNP vibration parts are absent unless a separately reviewed option is being tested | |

## B. Power and USB

| ID | Observable contract | Result / evidence |
|---|---|---|
| B1 | Stabilized unpowered TP1–TP3 and TP2–TP3 resistance recorded | |
| B2 | 5.00 V / 100 mA limited USB-only first power does not current-limit or produce rapid heating | |
| B3 | Protected VBUS, SYS_5V, and 3V3 values are within ±5%; startup waveforms attached | |
| B4 | Idle, radio-active, SD-write, display/buzzer, and combined peak current recorded | |
| B5 | 3V3 and SYS_5V ripple/droop under combined peak load are recorded with probe/bandwidth method and accepted by part limits | |
| B6 | BQ24074, TPS61232, AP63203, inductors, fuse, TVS, MCU, RF modules, battery, and GNSS temperatures recorded at 5, 15, and 30 min | |
| B7 | USB-C works in both plug orientations with two known-good cables | |
| B8 | Native USB enumerates, uploads, and reconnects ten times without reset-loop or data error | |
| B9 | CC1/CC2 behavior tested against two standards-compliant 5 V sources; no >5 V PD mode requested | |
| B10 | Specified protected PID 328 polarity/protection verified; battery-only startup and fuel-gauge reading recorded | |
| B11 | Charge current, input limit, termination, USB/battery handover, pack temperature, and rail continuity pass against BQ24074 configuration | |

## C. Firmware and local interfaces

| ID | Observable contract | Result / evidence |
|---|---|---|
| C1 | `esp32s3_rev_c_passive` exact commit builds and boots; binary hash and boot log attached | |
| C2 | RESET and BOOT each perform their documented function; USER produces only one logical press per actuation | |
| C3 | Status LED and buzzer patterns operate; no boot-strap or reset interference | |
| C4 | OLED initializes, all display regions work, and ten cable reconnects cause no connector damage | |
| C5 | microSD detect, create/write/read/hash/delete, and ten insert/remove cycles pass | |
| C6 | GNSS obtains a valid fix; time to first fix, NMEA data, and TIMEPULSE captured | |
| C7 | Wi-Fi dashboard and BLE scanning run concurrently for 30 min without watchdog/reset or unacceptable current | |
| C8 | Any Remote ID result is labelled experimental; captured frames are compared to the applicable ASTM/ASD-STAN format before a conformance claim | |

## D. Passive RF behavior

Use shielded fixtures or legally compliant low-level sources. Attach antenna only
where the test requires it. Record frequency, level, attenuation, equipment
calibration date, firmware configuration, and raw response.

| ID | Observable contract | Result / evidence |
|---|---|---|
| D1 | E28-2G4M12SX/SX1281 register identity and SPI operation verified | |
| D2 | SX1281 instantaneous RSSI is measured over the configured 2400–2500 MHz sweep at multiple controlled levels; no protocol/transmitter identity is inferred | |
| D3 | E07-900M10S/CC1101 register identity and SPI operation verified | |
| D4 | CC1101 RSSI response measured at multiple levels on configured 868 or 915 MHz channels; 433 MHz command is rejected/not emitted | |
| D5 | RX5808 three-bit selection maps to all eight documented channels (5645–5945 MHz); analog RSSI response/noise floor recorded | |
| D6 | Simultaneous 2.4 GHz, sub-GHz, 5.8 GHz, Wi-Fi/BLE, SD, GNSS, and display operation shows no unexplained resets, bus corruption, or GNSS loss | |
| D7 | J5/J7 return loss or receive comparison and E28/PID 2308 connection are measured with the exact assembly antennas | |
| D8 | Emissions/pre-compliance scan records unintended clocks/spurs; failures are corrected before broader use | |

## E. Enclosure fit and service

| ID | Observable contract | Result / evidence |
|---|---|---|
| E1 | Printed 165.4 × 117.4 × 33.5 mm nominal closed envelope and every critical opening measured; material, printer, orientation, and slicer settings recorded | |
| E2 | PCB seats on four supports without bending; four M3 × 30 screws/nuts fit and retain after five assembly cycles | |
| E3 | Specified battery fits its bay without preload or fastener contact; connector/lead can be inserted and removed without damage | |
| E4 | No visible contact between PCBA and base/lid except designed supports/compression posts | |
| E5 | OLED snaps in/out without damage, aperture aligns, and PID 4210 cable is neither pinched nor routed over antenna keepouts | |
| E6 | PID 2308 antenna adheres at the defined lid position; its U.FL cable is unpinched through five 30 mm lid-opening cycles | |
| E7 | RESET/BOOT/USER plungers return freely, operate only their switches, and pass 100 actuations | |
| E8 | USB-C cable inserts/removes without case load on connector; both plug orientations work | |
| E9 | microSD can be removed by finger and passes ten closed-case cycles without ejection obstruction | |
| E10 | Regional J5 antenna and Taoglas TG.59.0113 on J7 fit, rotate, and do not block each other, USB-C, or microSD | |
| E11 | LED is visible; buzzer is usable; enclosure temperature after 30 min remains within all component/material limits | |
| E12 | PCB, battery, display, antennas, cables, buttons, and nuts can be removed without destructive case modification | |

## F. Reliability and maturity decision

| ID | Observable contract | Result / evidence |
|---|---|---|
| F1 | 8 h powered functional soak passes with event/reset/current/temperature log | |
| F2 | Ten cold starts and ten warm resets pass | |
| F3 | Known failure modes and all rework are recorded against PCB/enclosure revision | |
| F4 | Fresh ERC, DRC, fabrication export, mechanical CAD check, firmware build, and host tests pass at the tested commit | |
| F5 | Review explicitly decides whether another prototype spin is required | |

## Status sign-off

- [ ] Prototype assembled
- [ ] Electrical bring-up passed
- [ ] Bench functional tests passed
- [ ] RF characterization passed for the stated passive observations
- [ ] Mechanical fit/service passed
- [ ] Reliability soak passed

**Allowed status after evidence review:**
`PROTOTYPE_ASSEMBLED` / `BENCH_TESTED` / `REQUIRES_REVISION`

**Not established by this checklist alone:** `FIELD_TESTED`, regulatory
compliance, production yield, environmental qualification, or
`PRODUCTION_VALIDATED`.

**Reviewer:** __________________  **Decision date:** __________________

**Open failures / required next revision:**

______________________________________________________________________________

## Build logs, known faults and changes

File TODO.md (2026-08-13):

# TODO

## Current engineering status

Rev C is **READY FOR FIRST PHYSICAL PROTOTYPE**, not stable/production-validated
hardware. Electrical, PCB, fabrication, firmware-build, and mechanical-CAD gates
must remain reproducible. The next work is physical evidence, not more generated
PASS prose.

## First Rev C prototype

- [ ] Order exactly one engineering PCBA lot from the checked Rev C fabrication package.
- [ ] Inspect exact MPN population and assembly quality.
- [ ] Perform current-limited first power and record TP1/TP2 rails, startup, current, ripple, and temperature.
- [ ] Verify native USB enumeration/upload in both cable orientations.
- [ ] Exercise RESET, BOOT, USER, LED, buzzer, OLED, microSD, and GNSS.
- [ ] Characterize E28-2G4M12SX / SX1281 instantaneous-RSSI response with a controlled 2.4 GHz source.
- [ ] Characterize E07-900M10S RSSI response in the selected 868/915 MHz band.
- [ ] Run simultaneous-radio/storage/display/GNSS coexistence tests.
- [ ] Print one enclosure and measure every critical fit/service interface.
- [ ] Complete `hardware/rev_c/PROTOTYPE_VALIDATION_CHECKLIST.md` with raw evidence.
- [ ] Decide whether Rev C requires a PCB/enclosure respin before any broader build.

## Firmware evidence gaps

- [ ] Replace the legacy 78-byte dummy TinyML model with a trained, versioned model and dataset/test evidence, or remove the optional TinyML path entirely.
- [ ] Validate BLE Remote ID parsing against captured standards-conformant frames before making any compliance claim.
- [ ] Demonstrate that any protocol parser receives a real demodulated byte stream before advertising over-air protocol detection.
- [ ] Validate ESP-NOW range/coexistence on physical Rev C nodes.
- [ ] Treat legacy LoRa “Meshtastic” and RSSI trilateration code as experimental unless protocol interoperability and calibrated localization tests are added.

## Maturity rule

Do not use `PROTOTYPE_ASSEMBLED`, `BENCH_TESTED`, `FIELD_TESTED`, or
`PRODUCTION_VALIDATED` until the corresponding physical evidence is committed.

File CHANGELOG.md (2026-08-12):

# Changelog

All notable changes to this project will be documented in this file.

The format is based on [Keep a Changelog](https://keepachangelog.com/en/1.0.0/),
and this project adheres to [Semantic Versioning](https://semver.org/spec/v2.0.0.html).

## [Unreleased]
### Hardware
- **Canonical Rev C passive monitor**: Replaced the failed Rev B identity with a
  clean ESP32-S3-WROOM-1-N16R8 design using exact E28-2G4M12SX,
  E07-900M10S, SAM-M10Q-00B, Molex 104031-0811, protected USB-C and battery
  power paths, and a reviewed four-layer PCB.
- **Evidence-first PCB and mechanics**: Added reproducible zero-unexcluded-warning
  ERC, zero-unexcluded-violation/zero-unconnected DRC, machine-audited narrow
  ERC/DRC exclusions, exact fitted/DNP BOM exports, Gerbers, drills, placement
  data, complete PCBA STEP, a case built around that assembly, M3 fasteners,
  connector/card/antenna/button service envelopes, collision checks, renders,
  and a dimensioned drawing.
- **First-prototype maturity only**: Rev C is ready for one physical engineering
  prototype. It has not been assembled, bench-tested, field-tested, qualified,
  or production-validated.

### Firmware and CI
- Added the manifest-gated `esp32s3_rev_c_passive` board target and separated
  current Rev C, failed Rev B, and legacy Rev A pin maps.
- Added `hardware/verify.py` and a hardware CI workflow covering pin staleness,
  KiCad ERC/DRC, mechanical CAD checks, fabrication export, and evidence upload.
- Reclassified TinyML, Remote ID conformance, 5.8 GHz reception, LoRa
  interoperability/localization, ATAK, direction finding, and field-use claims
  according to the evidence present in the repository.
- Removed the fictional RSSI-to-drone signature database and all active
  countermeasure/injection source. Runtime thresholds now classify only relative
  normalized energy activity; ESP-NOW, OLED, alerts, and the dashboard use the
  same non-identifying terminology.
- Made `src/dashboard.html` the deterministic source for the embedded gzip
  payload and removed the fake noise-calibration endpoint.
- Added current Rev C SX1281 instantaneous-RSSI, RX5808 RTC6715 channel-control,
  and MAX17048 battery-telemetry implementations. Removed transmit-frame builders
  from the receive-only CRSF/MAVLink parsers and retained known-good receive
  fixtures plus ASan/UBSan coverage.

### Documentation
- Replaced the public site's tier/jammer marketing and stale wiring visualizer
  with the Rev C engineering status, capability limits, and evidence links.
- Added exact assembly/bring-up instructions and a physical prototype validation
  checklist. Marked old DevKit buying/wiring pages as legacy and incompatible
  with Rev C.

### Fixed
- **PCB preview fidelity**: `render_pcb.py` now overlays the actual generated copper segments and vias from `skysweep32_pro.kicad_pcb` instead of showing only illustrative hardcoded traces; the preview revision is synchronized to PCB v1.1.
- **RX5808 control protocol**: Replaced the unusable one-GPIO pseudo-SPI implementation with independent DATA, CLOCK and SELECT signals and the RTC6715 25-bit LSB-first register frame. Known-frequency protocol vectors are covered by host tests.

### Changed
- **Legacy hardware status correction**: The Rev A generated PCB and enclosure are now explicitly marked `EXPERIMENTAL / UNVERIFIED / DO NOT ORDER`. KiCad syntax compatibility is distinguished from electrical, RF, mechanical, manufacturing and physical-prototype validation; ordering instructions were withdrawn pending the requirements-first Rev B redesign.
- **Rev B architecture decision**: Selected the exact no-PSRAM `ESP32-S3-WROOM-1-N8` integrated module after comparing classic ESP32 DevKit, current ESP32-S3 DevKitC and integrated S3 options. Added a firmware-to-signal matrix, safe GPIO allocation, independent RX5808 control/ADC paths, RF coexistence policy and locked module variants.
- **Single-source Rev B pin map**: Added a machine-readable hardware manifest, generated firmware header, exact ESP32-S3 PlatformIO board target and CI/pre-build divergence gate. The canonical Rev B build also uses a dedicated HSPI controller for removable microSD.

## [0.6.1] - 2026-08-09

### Fixed
- **Runtime Thresholds Now Effective**: `CountermeasureSystem::assessThreat()` read the compile-time `RSSI_THRESHOLD_*` macros instead of the values in `ConfigManager`, so the `/api/calibrate` and `/api/config` endpoints saved new thresholds that never influenced threat detection. Threat assessment now uses the live runtime config.
- **Broken Flash Instructions**: The "Start from Zero" guides (EN/RU) pointed at stale release names and Wi-Fi credentials. Updated them for the `v0.6.1` artifacts and the actual `SkySweep32` / `skysweep32` AP.
- **Version Drift**: Unified the firmware version reported in serial/web (`SKYSWEEP_VERSION`), release builder, flash script, and `TODO.md` to `0.6.1`.
- **CC1101 `receiveData` OOB**: Returned the raw on-air length byte (up to 255) while only copying `maxLength` bytes, so callers read past their 64-byte buffer. It now returns the number of bytes actually copied.
- **CC1101 band/spectrum scans** left the radio tuned to the last-scanned frequency; they now save and restore the real pre-scan frequency.
- **CC1101 `writeRegister`** had an unbounded busy-wait on a hardcoded pin; it now waits on `PIN_SPI_MISO` with a 10 ms timeout so an absent/faulty chip can't hang the task.
- **MAVLink length truncation**: `expectedLength` was `uint8_t`, so payloads of 248–255 bytes wrapped and parsed garbage; widened to `uint16_t`. `parseHeartbeat()` now zero-initializes its result on short payloads.
- **Signal DB scoring**: partial RSSI-match distance was `int8_t` and could overflow (0–100 scale vs negative-dBm bounds), corrupting the score; widened to `int`.
- **Deep-sleep duration**: `sleepDurationUs` was `uint32_t`, truncating sleeps over ~71 minutes; widened to `uint64_t`.
- **GPS geofence name**: `strncpy` could leave the name non-NUL-terminated; now explicitly terminated.
- **Cosmetic/log**: NRF24 spectrum log printed MHz as "GHz"; Meshtastic triangulation log passed `size_t` to `%d`; corrected `power_manager` comments (GPIO36/ADC1_CH0, 12 dB attenuation).
- **cppcheck warnings**: `data_logger` logged a `uint32_t` timestamp with `%lu` (type mismatch); fully initialized the ATAK, CRSF, MAVLink, and Acoustic constructors; gave `GPSModule` deleted copy operations (it owns a raw `HardwareSerial*`).

### Security
- **CRSF parser buffer overflow (critical)**: an attacker-controlled length byte of `0xFE`/`0xFF` wrapped `uint8_t expectedLength` to 0/1, then `memcpy`'d up to ~252 bytes into the 60-byte payload buffer. The length is now range-validated and `expectedLength` widened; the CRC is also read at the correct in-frame offset.
- **Remote ID BLE OOB read**: the BLE Remote ID parsers read fixed offsets (up to byte 22) from variable-length, attacker-controlled service data after only a `length < 2` check. Added per-message-type minimum-length guards.
- **ESP-NOW OOB read**: the receive callback only checked `len >= 4` before dereferencing union payloads at offset 8+. It now validates the full header plus the per-type payload length before handling.
- **Web `/api/logs/download` path traversal**: the `file` parameter was concatenated into a path with no validation; now rejects `..`, path separators, and CR/LF.
- **Web OTA false success**: the endpoint reported success and rebooted even when no firmware was written (`Update.hasError()` is false in that case too); success is now tracked from the upload and gated on a verified write.
- **ESP-NOW and LoRa input validation**: Reject malformed callback frames, invalid LoRa lengths, null direct-message inputs, and unterminated triangulation identifiers before parsing.

### Changed
- **KiCad 6+ PCB compatibility**: Regenerated `hardware/skysweep32_pro.kicad_pcb` with valid `(comment N ...)` title-block forms and `gr_arc` `mid` geometry, and improved deterministic signal routing for the 120 × 80 mm Pro carrier.
- **Simpler RF Task Loops**: Replaced the repeated `#ifndef MODULE_*` guard blocks in the RF-scan and display tasks with a single `rfModuleEnabled()` helper (behavior unchanged).
- **Portable hardware generators (large refactor)**: `build_kicad.py`, `render_pcb.py` and `enclosures/build_case.py` no longer hardcode a single Windows output path — each derives its output from the script location and accepts CLI overrides.
  - `build_kicad.py`: split into `build_pcb()` / `main()` with `argparse`, shared S-expression emit-helpers (`fp_ref`/`fp_val`/`fp_rect`/…) collapsing the per-footprint boilerplate, a `NET` name→index lookup, deterministic routing, and dead code removed.
  - `render_pcb.py`: restructured from a flat script into `draw()`/`render()`/`main()` with the axes passed explicitly; dropped unused imports and dead math; fixed the matplotlib `color`/`edgecolor` warnings.
  - `enclosures/build_case.py`: now **headless-capable** — STL export works via `freecadcmd` without a GUI (all `ViewObject`/render calls are guarded on `FreeCAD.GuiUp`); dimensions hoisted to named constants; dead code (`sma_h`, stray `sys.exit`) removed; regenerated STL exports were verified with FreeCAD 1.1.3.

### Added
- **CI Coverage for Optional Modules**: New `esp32dev_full` PlatformIO env plus a CI step compiles the ATAK / Compass / Acoustic / GPS code paths that no release tier enables, so they no longer rot undetected.
- **CI Maintenance**: Bumped GitHub Actions (`checkout@v4`, `setup-python@v5`, `cache@v4`, `action-gh-release@v2`) and added a `workflow_dispatch` trigger for manual runs.
- **Build Status Badge**: Added the GitHub Actions CI badge to the README.
- **Host Unit Tests for Parsers**: Added `test/host/` — desktop-compiled tests (system `g++`, no ESP32 toolchain/PlatformIO registry) that build the CRSF/MAVLink parsers against a minimal `Arduino.h` stub with AddressSanitizer/UBSan. They lock in the buffer-safety fixes (hostile length bytes rejected, valid frames round-trip), the CRSF RC-channel pack/unpack round-trip, the GPS/heartbeat `parse*` bounds guards, and a deterministic ~460k-frame fuzz pass over both parsers; run in CI via a new `host-tests.yml` workflow.
- **Static Analysis (cppcheck)**: the host workflow (renamed *Host Tests & Static Analysis*) now also runs cppcheck warning-level checks over the full feature set — a system tool, so it needs no PlatformIO registry and gates on likely defects.

### Documentation
- Refreshed the README software-architecture tree (EN + RU) to list every current module (it previously showed only 4 of ~20) and added a **Testing** section.
- Documented the `/api/calibrate` endpoint in the EN + RU API references (it was implemented but undocumented).
- Added a "Running tests locally" guide (host tests + cppcheck) to `CONTRIBUTING.md`.
- **GitHub Pages**: added a *Hardened & Field-Tested* capability card (EN + RU) reflecting the parser hardening, fuzzing and CI static analysis.
- Added `hardware/README.md` (index + how to regenerate the PCB/preview) and updated the enclosure regeneration guide for the portable, headless scripts.

## [0.6.0] - 2026-06-12

### Added
- **ATAK Integration (Cursor on Target)**: Added `#ifdef MODULE_ATAK`. Sends CoT UDP packets for drone targets directly to Android Team Awareness Kit on port 6969.
- **Stealth Mode (Dark Mode)**: Added `stealthMode` config to instantly silence buzzers and switch to vibration motor (`PIN_VIBRATION`), disabling OLED to prevent visual signature at night.
- **Hardware Compass Direction Finding**: Integrated QMC5883L I2C compass (`#ifdef MODULE_COMPASS`). Displays azimuth on OLED and sends vector data (course) to ATAK CoT packets for precise triangulation.
- **TinyML AI Classification**: Replaced rule-based engine with TensorFlow Lite Micro via `EloquentTinyML` (`#ifdef MODULE_ML`). Predicts drone class based on RSSI variance and multi-band spectral data tensor.
- **Optional Feature Flags**: Added `-DMODULE_COMPASS`, `-DMODULE_ML`, and `-DMODULE_ATAK` to `platformio.ini` to keep base footprint small.

## [0.5.1] - 2026-06-09

### Added
- **SD Card Logs Web UI**: Added dynamic card in web dashboard allowing users to list and download raw forensic logs directly from their browser (requires active SD card module).
- **LoRa Mesh Triangulation Math**: Implemented RSSI-based trilateration solver inside `MeshtasticClient` to calculate and log the approximate geographic position of a detected operator/drone using reports from multiple nodes.

### Fixed
- **Pro Tier Compile Bug**: Fixed missing `<SD.h>` include in `src/web_server.cpp` when compiling with `MODULE_SD_CARD` enabled.
- **License Alignment**: Corrected landing page license references from MIT to GNU General Public License v3.0 to match the repository's license.
- **GitHub Pages Jekyll Errors**: Added `.nojekyll` bypass to prevent Jekyll from causing compilation failures on index.html assets.

## [0.5.0] - 2026-03-28

### Added
- **Beginner Guides ("Start from Zero")**: New comprehensive assembly guides for both [English](docs/en/start_from_zero.md) and [Russian](docs/ru/start_from_zero.md) users. No soldering required, focus on modular Starter Tier assembly.
- **Universal Flash Script**: Added `flash.bat` as a one-click firmware installer for Windows users, simplifying the setup process for non-technical users.

### Localized
- **Full Russian Web Dashboard**: Translated all real-time UI elements including Uptime, RAM usage, Battery percentages, Power modes, and Threat classifications into Russian.

### Fixed
- **WebServer Config Ref**: Corrected `RuntimeConfig` reference handling in `web_server.cpp` to ensure UI actions (like calibration) persist correctly.
- **ConfigManager Cleanup**: Standardized configuration saving logic across the core architecture.

## [0.4.0] - 2026-03-28

### Added
- **Interactive Map** (Leaflet.js + OpenStreetMap): Live drone positions on dashboard map with blue markers. Operators shown as orange markers. Auto-centers on first detection
- **Multi-Band RF Scanning**: CC1101 now scans 433/868/915 MHz ISM bands in rotation. `setBand()`, `scanAllBands()`, and `spectrumScan()` methods
- **Power Management** (`power_manager.h/cpp`):
  - 4 power modes: Full (240MHz) → Balanced (160MHz) → Low (80MHz) → Deep Sleep
  - Battery voltage monitoring via ADC (voltage divider on GPIO36)
  - Auto-low-power on critical battery (<5%)
  - Deep sleep / light sleep with timer wakeup
  - CPU frequency scaling, WiFi/BLE power state control
  - Estimated runtime calculation
- **Dashboard: Battery + Power**: Battery %, voltage, power mode, and estimated runtime shown live on web dashboard
- **API: Power Mode**: `POST /api/power?mode=0-3` — remotely switch power modes
- **Runtime Config Integration**: RF scan interval now uses `configManager` value (changeable via API)
- **NRF24 Spectrum Scanner**: Hardware 125-channel 2.4 GHz spectrum sweep via RPD.
- **Signal Database (`signal_database.h/cpp`)**: Preloaded with 8 unique drone RF signatures (DJI, FPV, ArduPilot, etc.) with advanced ML-like factor matching based on bands and RSSI variance.
- **ESP-NOW Mesh (`espnow_mesh.h/cpp`)**: Free decentralized node-to-node communication sharing threats, telemetry, and heartbeats autonomously between active SkySweep nodes.
- **Alert Manager (`alert_manager.h/cpp`)**: External notifications module with non-blocking buzzer tones and LED control corresponding to dynamic threat levels.
- **3D Enclosures Documentation**: Added EN & RU guides (`docs/en/enclosures.md`) with design recommendations, optimal materials, cooling, and antenna placement strategies for 3D printed cases.
- **Auto-Calibrate UI Button**: Added `/api/calibrate` endpoint and dashboard GUI button to automatically zero background RF noise and adjust threat thresholds.

## [0.3.1] - 2026-03-28

### Added
- **OTA Firmware Updates**: Upload firmware via `POST /api/ota` endpoint
- **Runtime Configuration**: JSON config stored on SPIFFS (`config_manager.h/cpp`)
  - WiFi, RSSI thresholds, scan intervals, LoRa settings editable without recompile
  - REST API: `GET/POST /api/config`, `POST /api/config/reset`
  - Partial updates supported (only send changed fields)
- **Watchdog Timer**: 30-second hardware watchdog prevents system hangs
- **`#ifdef` Guards on All Drivers**: CC1101, NRF24, RX5808 drivers wrapped in module guards for clean conditional compilation
- **Software Guide**: `docs/en/software.md` and `docs/ru/software.md` — Quick start, API reference, OTA, troubleshooting
- **Contributing Guide**: `CONTRIBUTING.md` — Code conventions, priority areas

### Fixed
- **`config.h` RF_MODULE_COUNT Macro**: Replaced broken `defined()` in `#define` arithmetic with proper `#ifdef` chain
- **Duplicate `#define` Conflict**: Removed duplicated RSSI threshold defines from `countermeasures.cpp` (now in `config.h`)

## [0.3.0] - 2026-03-28

### Added
- **Modular Tier System**: Three hardware tiers (Starter $15 / Hunter $35 / Sentinel $60+)
- **Central `config.h`**: All pins, modules, and settings in one file
- **SPI Bus Manager**: FreeRTOS mutex for safe multi-device SPI access (`spi_manager.h/cpp`)
- **FreeRTOS Multi-Task Architecture**: 7+ tasks across dual ESP32 cores
- **Full Web Dashboard**: Dark-themed HTML dashboard with real-time WebSocket updates, RSSI graphs, drone detection list, system status, and module badges
- **Rule-Based ML Classifier**: Classifies drones by protocol detection (MAVLink/CRSF), frequency band patterns, and RSSI variance analysis
- **Protocol Integration**: MAVLink and CRSF parsers connected to RF scanning pipeline
- **Modular Upgrade Guide**: `docs/en/modules.md` and `docs/ru/modules.md` with BOM, wiring, and upgrade paths

### Fixed
- **CRITICAL: Pin Conflicts Resolved**: GPS (GPIO 16/17) no longer conflicts with RF CS pins; LoRa (GPIO 26/33/32/25) no longer conflicts with CC1101/NRF24
- **CRITICAL: `web_server.cpp` Implemented**: Was completely empty (0 bytes), now full dashboard
- **WiFi Mode Conflict**: Remote ID no longer calls `WiFi.mode(WIFI_STA)` — web server manages WiFi in `WIFI_AP_STA` mode
- **Remote ID Memory Leak**: Replaced unbounded `std::vector` with fixed-size array (`MAX_DETECTED_DRONES = 20`)
- **Acoustic Detector I2S Mismatch**: Changed from `I2S_BITS_PER_SAMPLE_32BIT` to `16BIT` to match `int16_t` buffer
- **Data Logger File Handle Leaks**: All `File` objects now properly closed after iteration
- **Data Logger `deleteOldestLog()`**: Now builds full path with `LOG_DIR` prefix
- **ML Classifier Stub Removed**: No longer returns hardcoded values

### Changed
- **main.cpp**: Complete rewrite from monolithic `loop()` to FreeRTOS task-based architecture
- **All modules**: Wrapped in `#ifdef MODULE_*` guards for conditional compilation
- **All headers**: Use `config.h` instead of scattered local `#define` statements
- **Countermeasures**: Use SPI mutex, threshold values from `config.h`
- **Meshtastic Client**: Packet buffer limited to 50 entries to prevent memory issues

### Security
- Countermeasures require both `ENABLE_COUNTERMEASURES` build flag AND runtime `armSystem(true)` call
- WebSocket connections limited to `MAX_WEBSOCKET_CLIENTS` (4) to prevent crash

## [0.2.0] - 2026-03-28

### Added
- Remote ID Detection (FAA ANSI/CTA-2063)
- Web Interface (placeholder)
- Data Logging to SD card
- GPS Module integration
- Meshtastic LoRa mesh networking
- Machine Learning placeholder
- Full RF driver implementations
- MAVLink/CRSF protocol parsers
- Countermeasure system
- Bilingual documentation (EN/RU)
- GPL-3.0 license

## [0.1.0] - 2026-03-28

### Added
- Initial project structure
- Basic ESP32 configuration
- Placeholder RF module support
- OLED display integration
- PlatformIO build system

[0.6.1]: https://github.com/bobberdolle1/SkySweep32/compare/v0.6.0...v0.6.1
[0.6.0]: https://github.com/bobberdolle1/SkySweep32/compare/v0.5.1...v0.6.0
[0.3.0]: https://github.com/bobberdolle1/SkySweep32/compare/v0.2.0...v0.3.0
[0.2.0]: https://github.com/bobberdolle1/SkySweep32/compare/v0.1.0...v0.2.0
[0.1.0]: https://github.com/bobberdolle1/SkySweep32/releases/tag/v0.1.0

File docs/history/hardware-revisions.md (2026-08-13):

# Hardware revision history

SkySweep32 has one current physical hardware line: **Rev C** under
`hardware/rev_c/`. It is ready for a first physical prototype only.

## Rev A

Rev A was an early ESP32 DevKit-era concept. Its pin maps, binaries, and CAD are
not compatible with Rev C. Historical v0.6.1 release assets should not be used
on Rev C.

## Rev B

Rev B was publicly marked experimental/unverified after its machine evidence
contradicted earlier validation prose: stale ERC/DRC material showed unresolved
errors, warnings, collisions and roughly 375 DRC violations. Rev B was archived
rather than silently redefined. It is not a fabrication source, BOM, enclosure,
or firmware target.

## Rev C

Rev C is a clean passive-monitor redesign: exact manifest, native KiCad sources,
four-layer PCB, canonical firmware target, reproducible evidence, and an
assembly-aware enclosure. Passing CAD/build gates does not substitute for an
assembled board or measurements. See [current hardware](../en/hardware.md) and
[Prototype #1 checklist](../../hardware/rev_c/PROTOTYPE_VALIDATION_CHECKLIST.md).

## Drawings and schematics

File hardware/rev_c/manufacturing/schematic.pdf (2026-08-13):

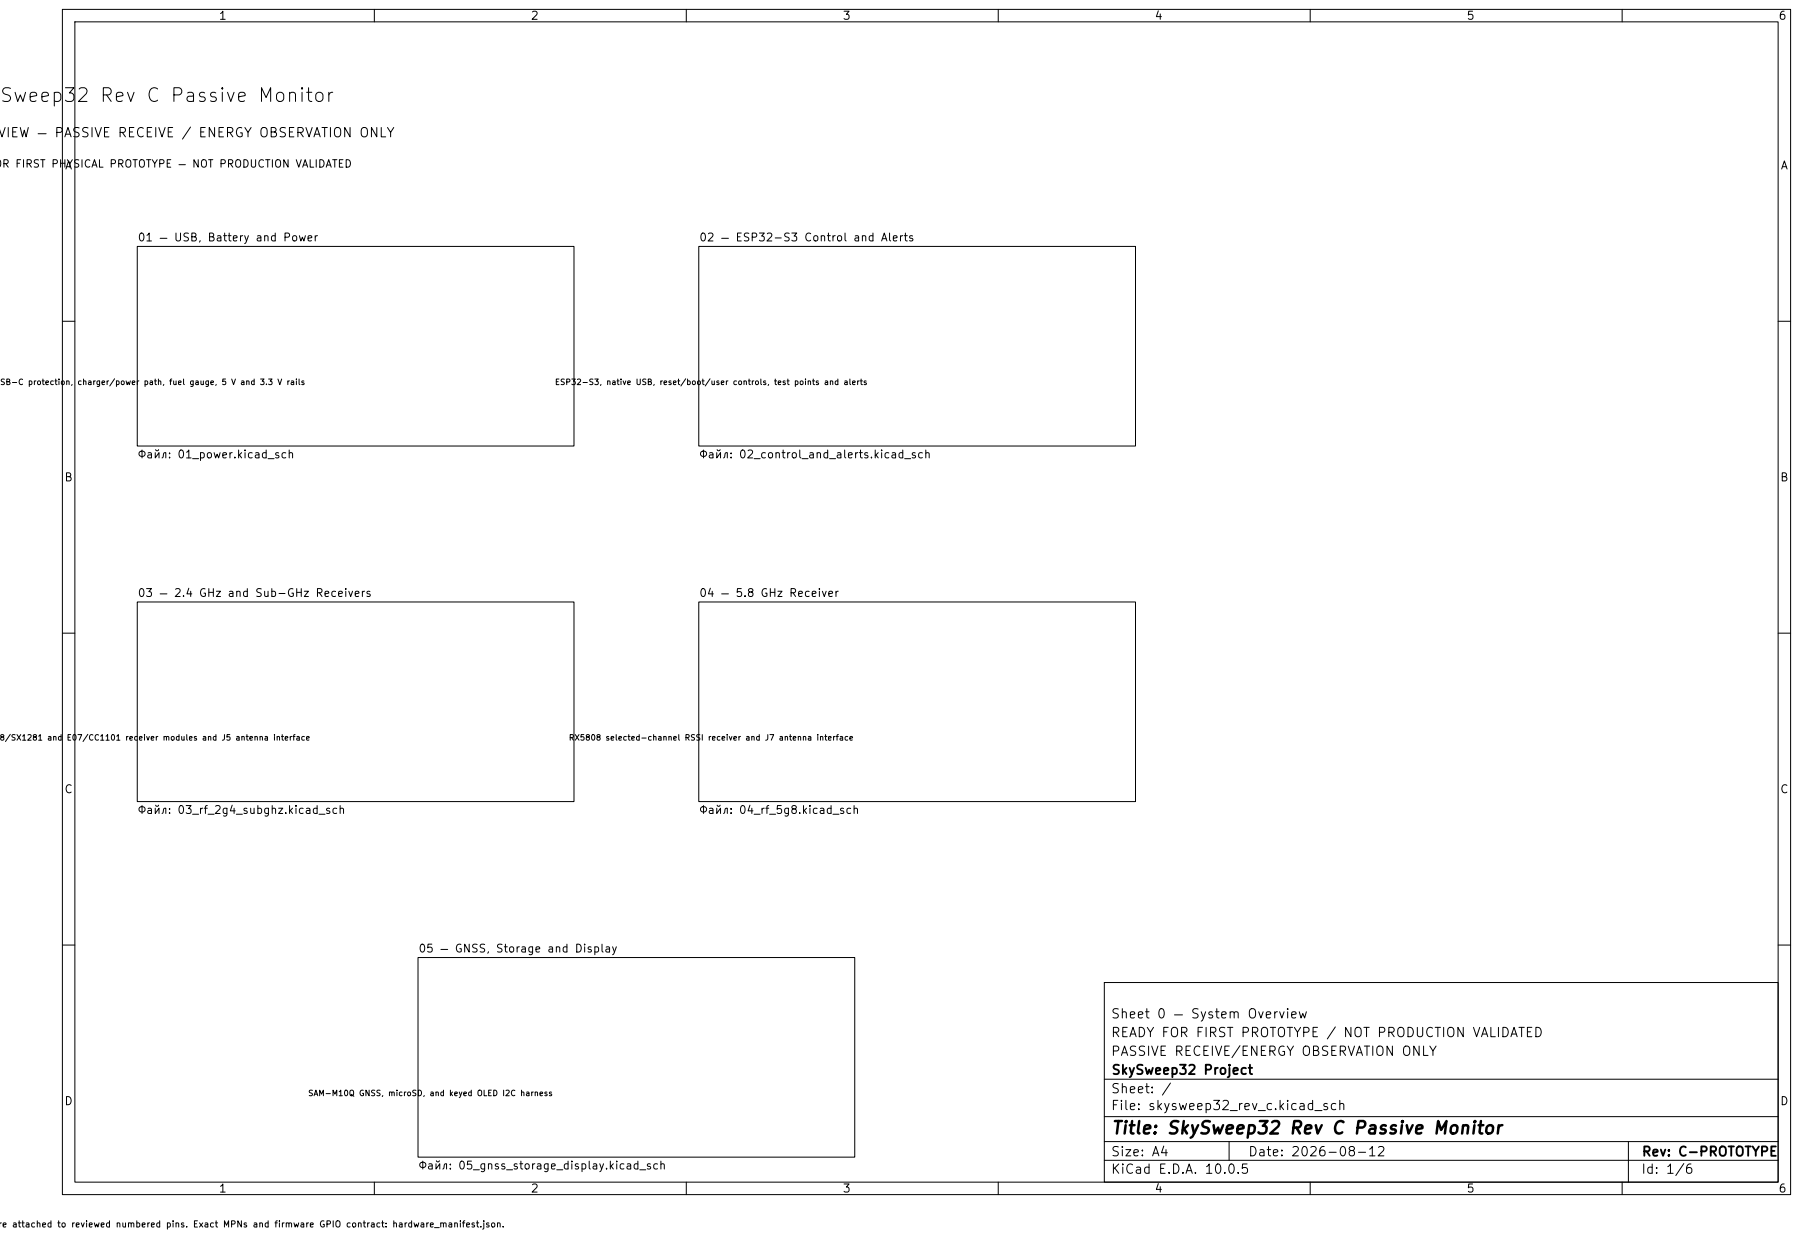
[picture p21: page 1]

DESIGN OVERVIEW — PASSIVE RECEIVE / ENERGY OBSERVATION ONLY

READY FOR FIRST PHYSICAL PROTOTYPE — NOT PRODUCTION VALIDATED

Sheet 0 — System Overview
READY FOR FIRST PROTOTYPE / NOT PRODUCTION VALIDATED
PASSIVE RECEIVE/ENERGY OBSERVATION ONLY
SkySweep32 Project
Sheet: /
File: skysweep32_rev_c.kicad_sch
Title: SkySweep32 Rev C Passive Monitor

Size: A4 | Rev: C-PROTOTYPE
KiCad E.D.A. 10.0.5 | Id: 1/6

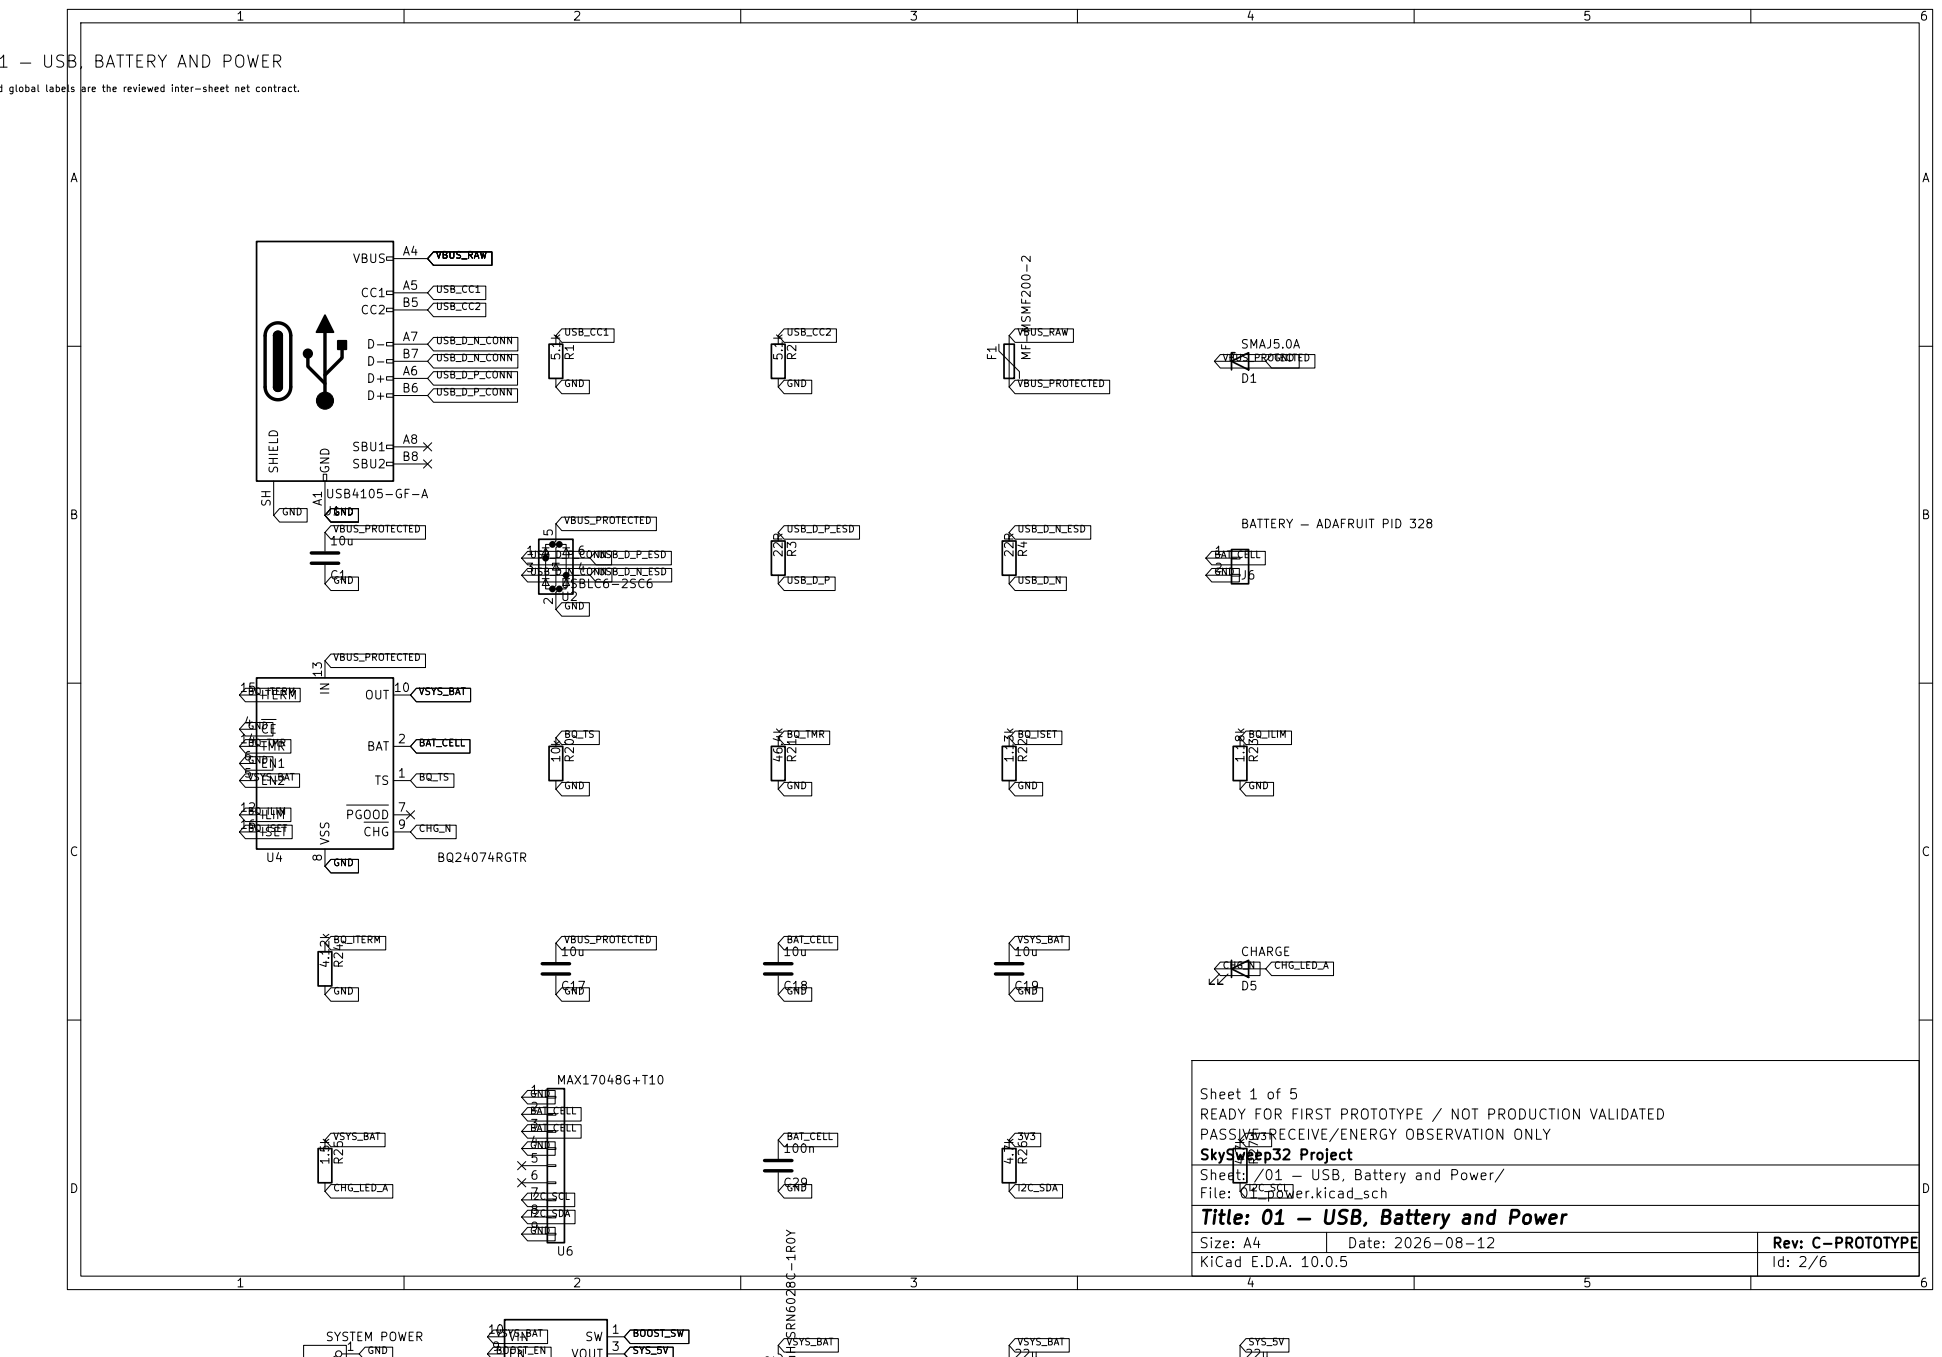
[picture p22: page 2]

Named global labels are the reviewed inter-sheet net contract.

Sheet 1 of 5
READY FOR FIRST PROTOTYPE / NOT PRODUCTION VALIDATED
PASSIVE RECEIVE/ENERGY OBSERVATION ONLY
SkySweep32 Project
File: 01_power.kicad_sch
Title: 01 — USB, Battery and Power

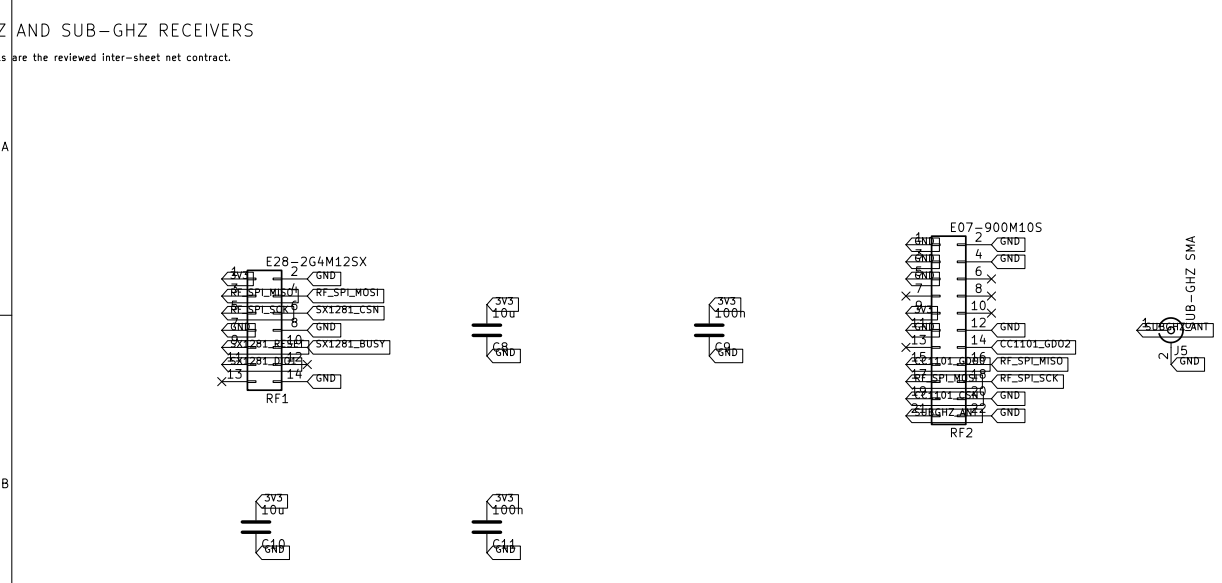
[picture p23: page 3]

GND Named global labels are the reviewed inter-sheet net contract. 03 — 2.4 GHZ AND SUB-GHZ RECEIVERS

Sheet 3 of 5
READY FOR FIRST PROTOTYPE / NOT PRODUCTION VALIDATED
PASSIVE RECEIVE/ENERGY OBSERVATION ONLY
SkySweep32 Project
Sheet: /03 — 2.4 GHz and Sub-GHz Receivers/
File: 03_rf_2g4_subghz.kicad_sch
Title: 03 — 2.4 GHz and Sub-GHz Receivers

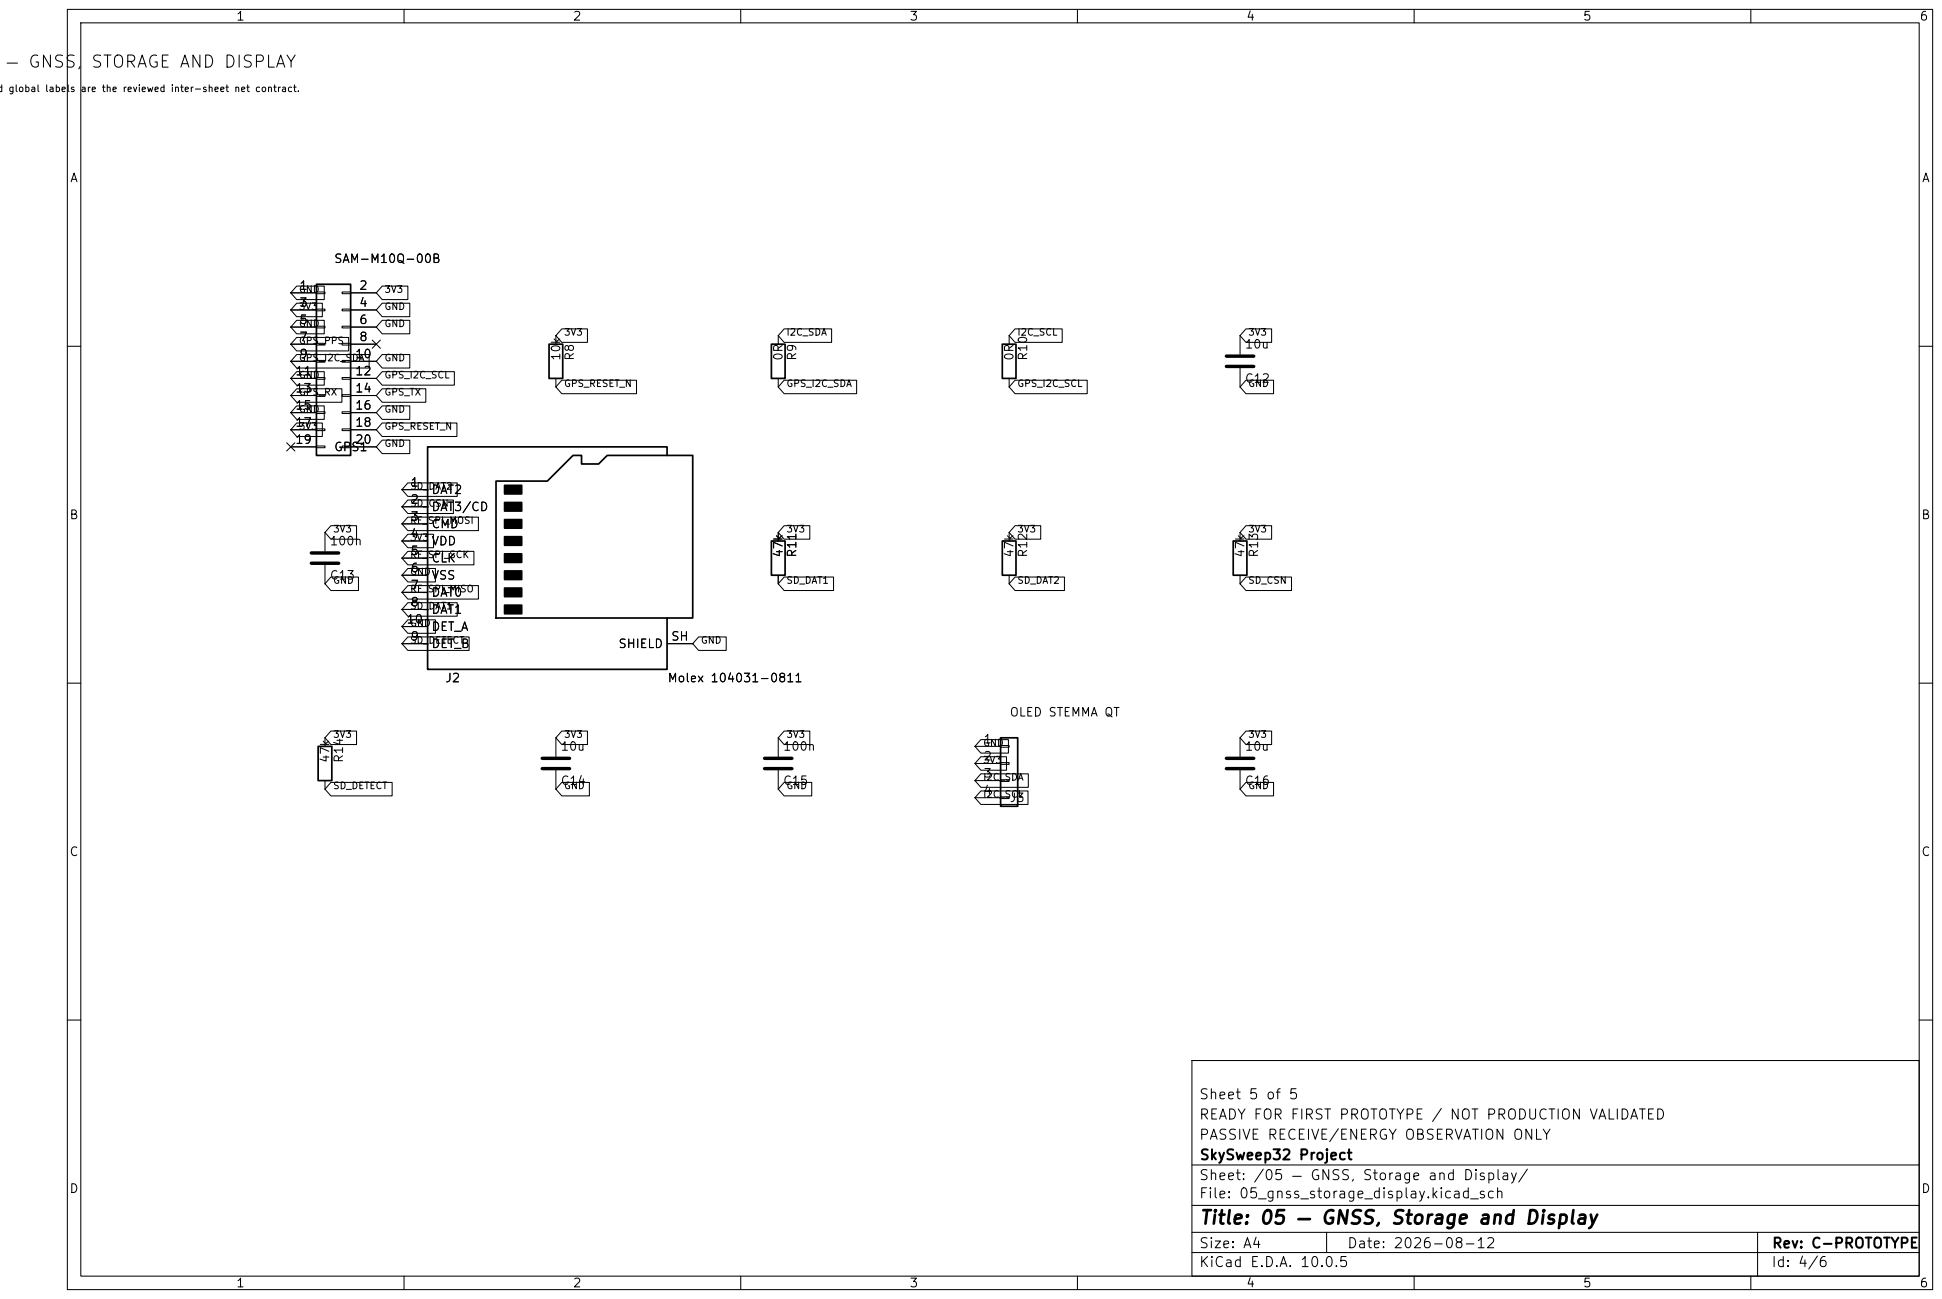
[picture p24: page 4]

Named global labels are the reviewed inter-sheet net contract. 05 — GNSS, STORAGE AND DISPLAY

Sheet 5 of 5
READY FOR FIRST PROTOTYPE / NOT PRODUCTION VALIDATED
PASSIVE RECEIVE/ENERGY OBSERVATION ONLY
SkySweep32 Project
Sheet: /05 — GNSS, Storage and Display/
File: 05_gnss_storage_display.kicad_sch
Title: 05 — GNSS, Storage and Display

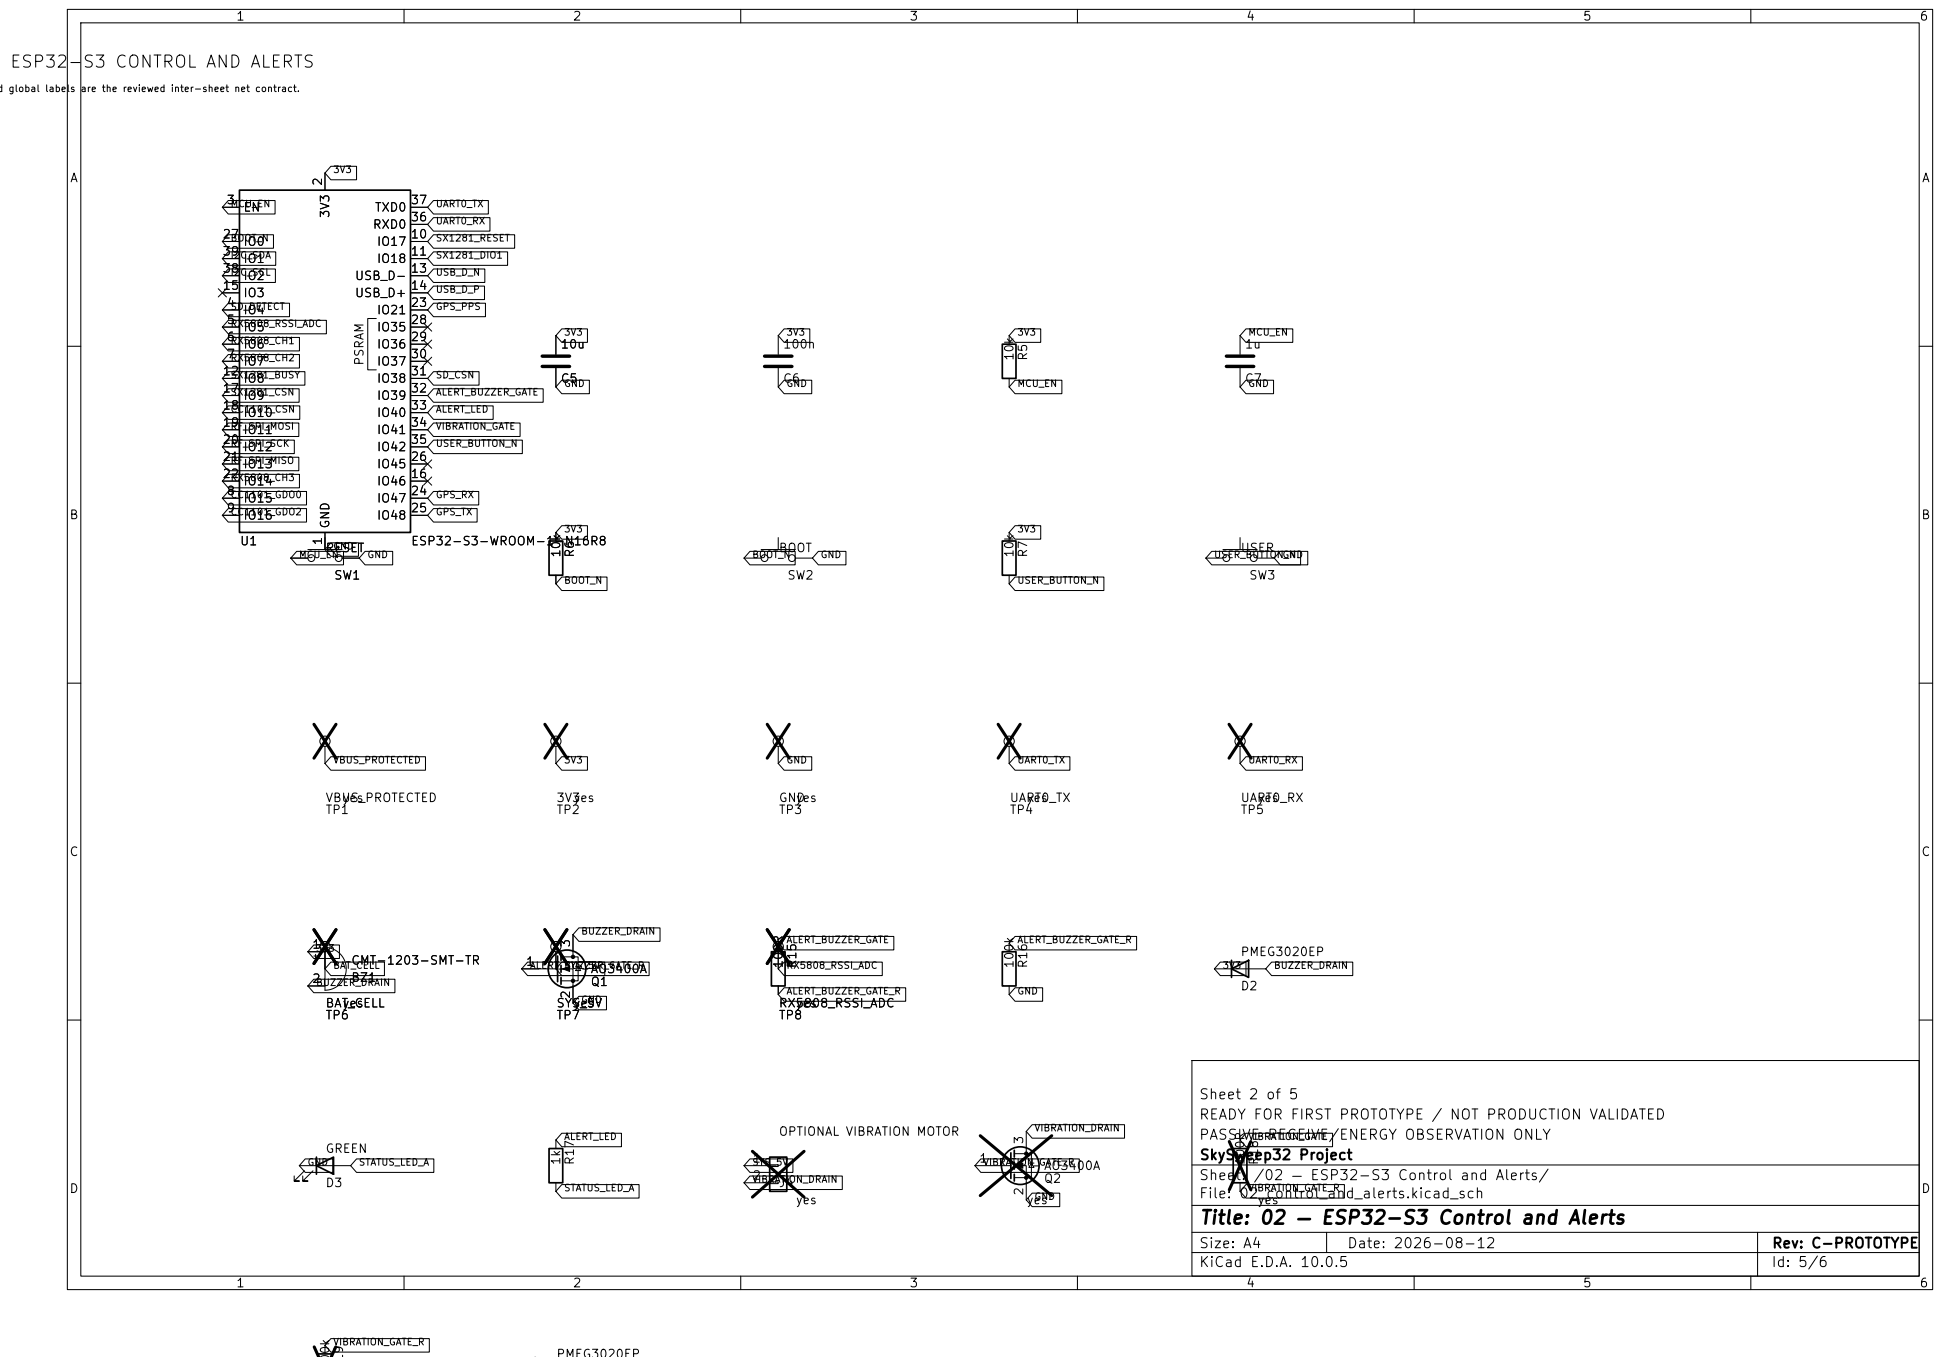
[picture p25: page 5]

TP5 UART0_RX yes SW1 RESET PSRAM GND

SYS_5V yes BZ1 CMT-1203-SMT-TR

Sheet 2 of 5
READY FOR FIRST PROTOTYPE / NOT PRODUCTION VALIDATED
PASSIVE RECEIVE/ENERGY OBSERVATION ONLY
SkySweep32 Project
File: 02_control_and_alerts.kicad_sch
Title: 02 — ESP32-S3 Control and Alerts

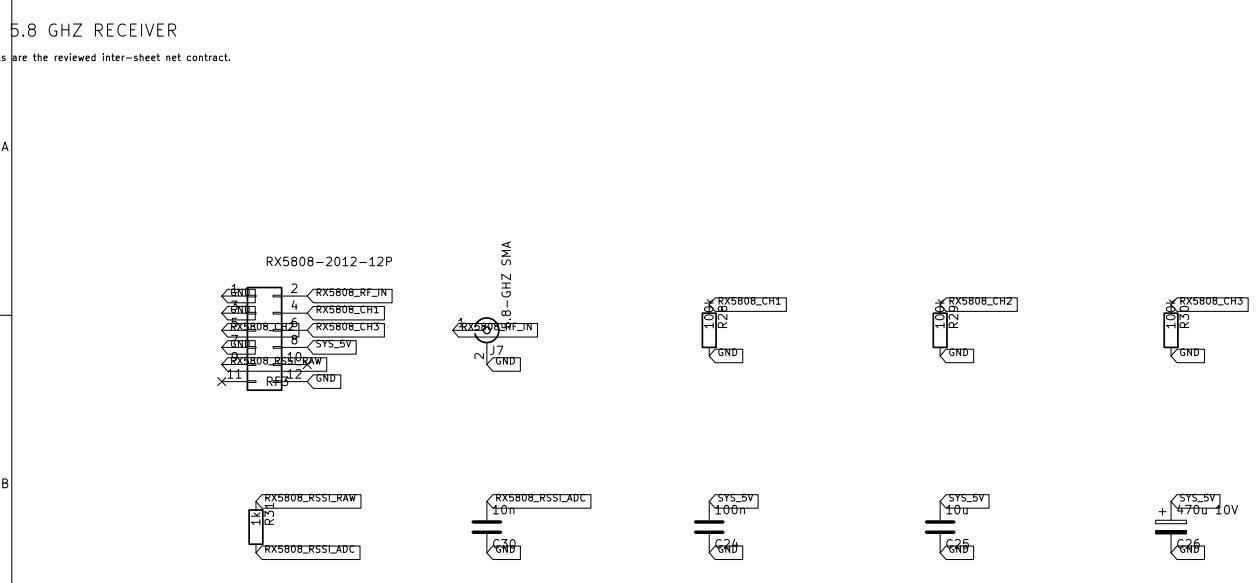
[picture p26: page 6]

Named global labels are the reviewed inter-sheet net contract.

Sheet 4 of 5
READY FOR FIRST PROTOTYPE / NOT PRODUCTION VALIDATED
PASSIVE RECEIVE/ENERGY OBSERVATION ONLY
SkySweep32 Project
Sheet: /04 — 5.8 GHz Receiver/
File: 04_rf_5g8.kicad_sch
Title: 04 — 5.8 GHz Receiver

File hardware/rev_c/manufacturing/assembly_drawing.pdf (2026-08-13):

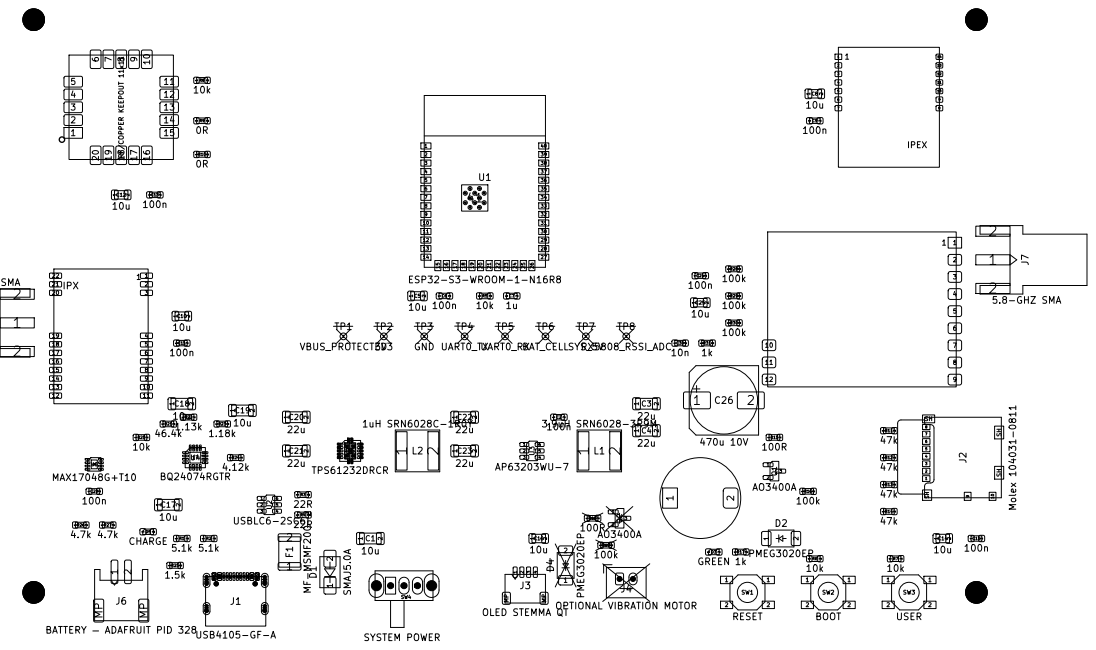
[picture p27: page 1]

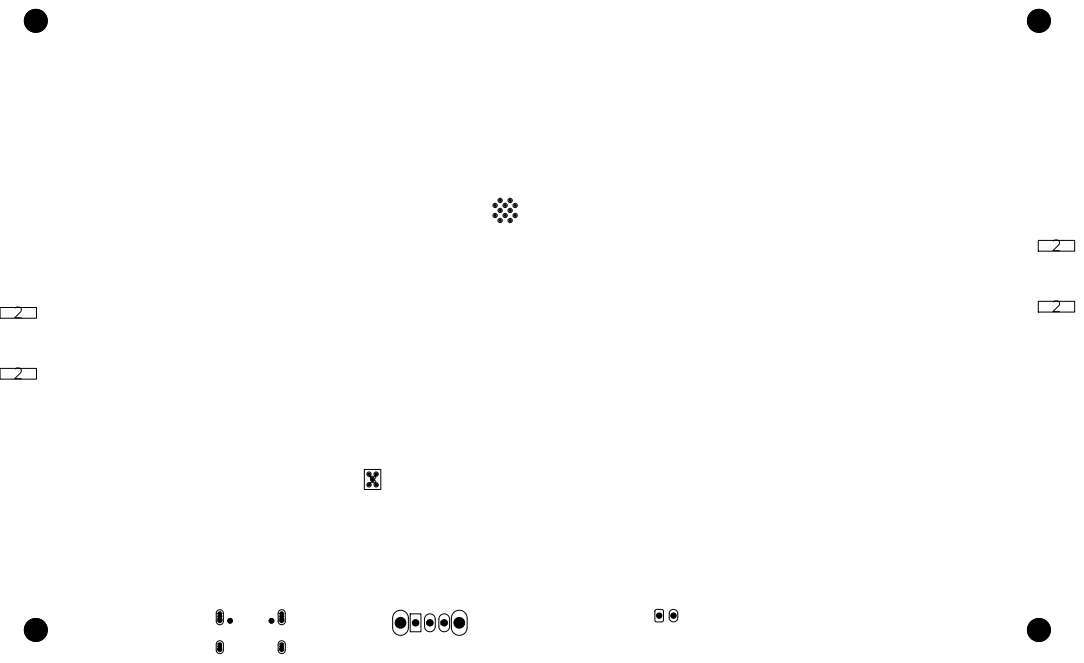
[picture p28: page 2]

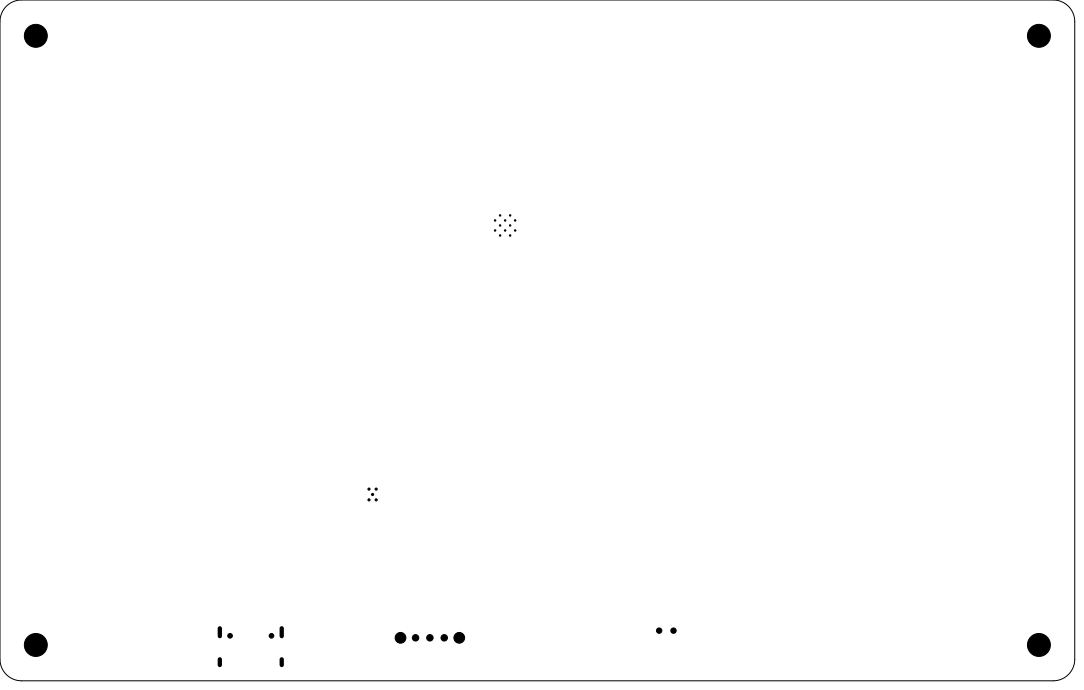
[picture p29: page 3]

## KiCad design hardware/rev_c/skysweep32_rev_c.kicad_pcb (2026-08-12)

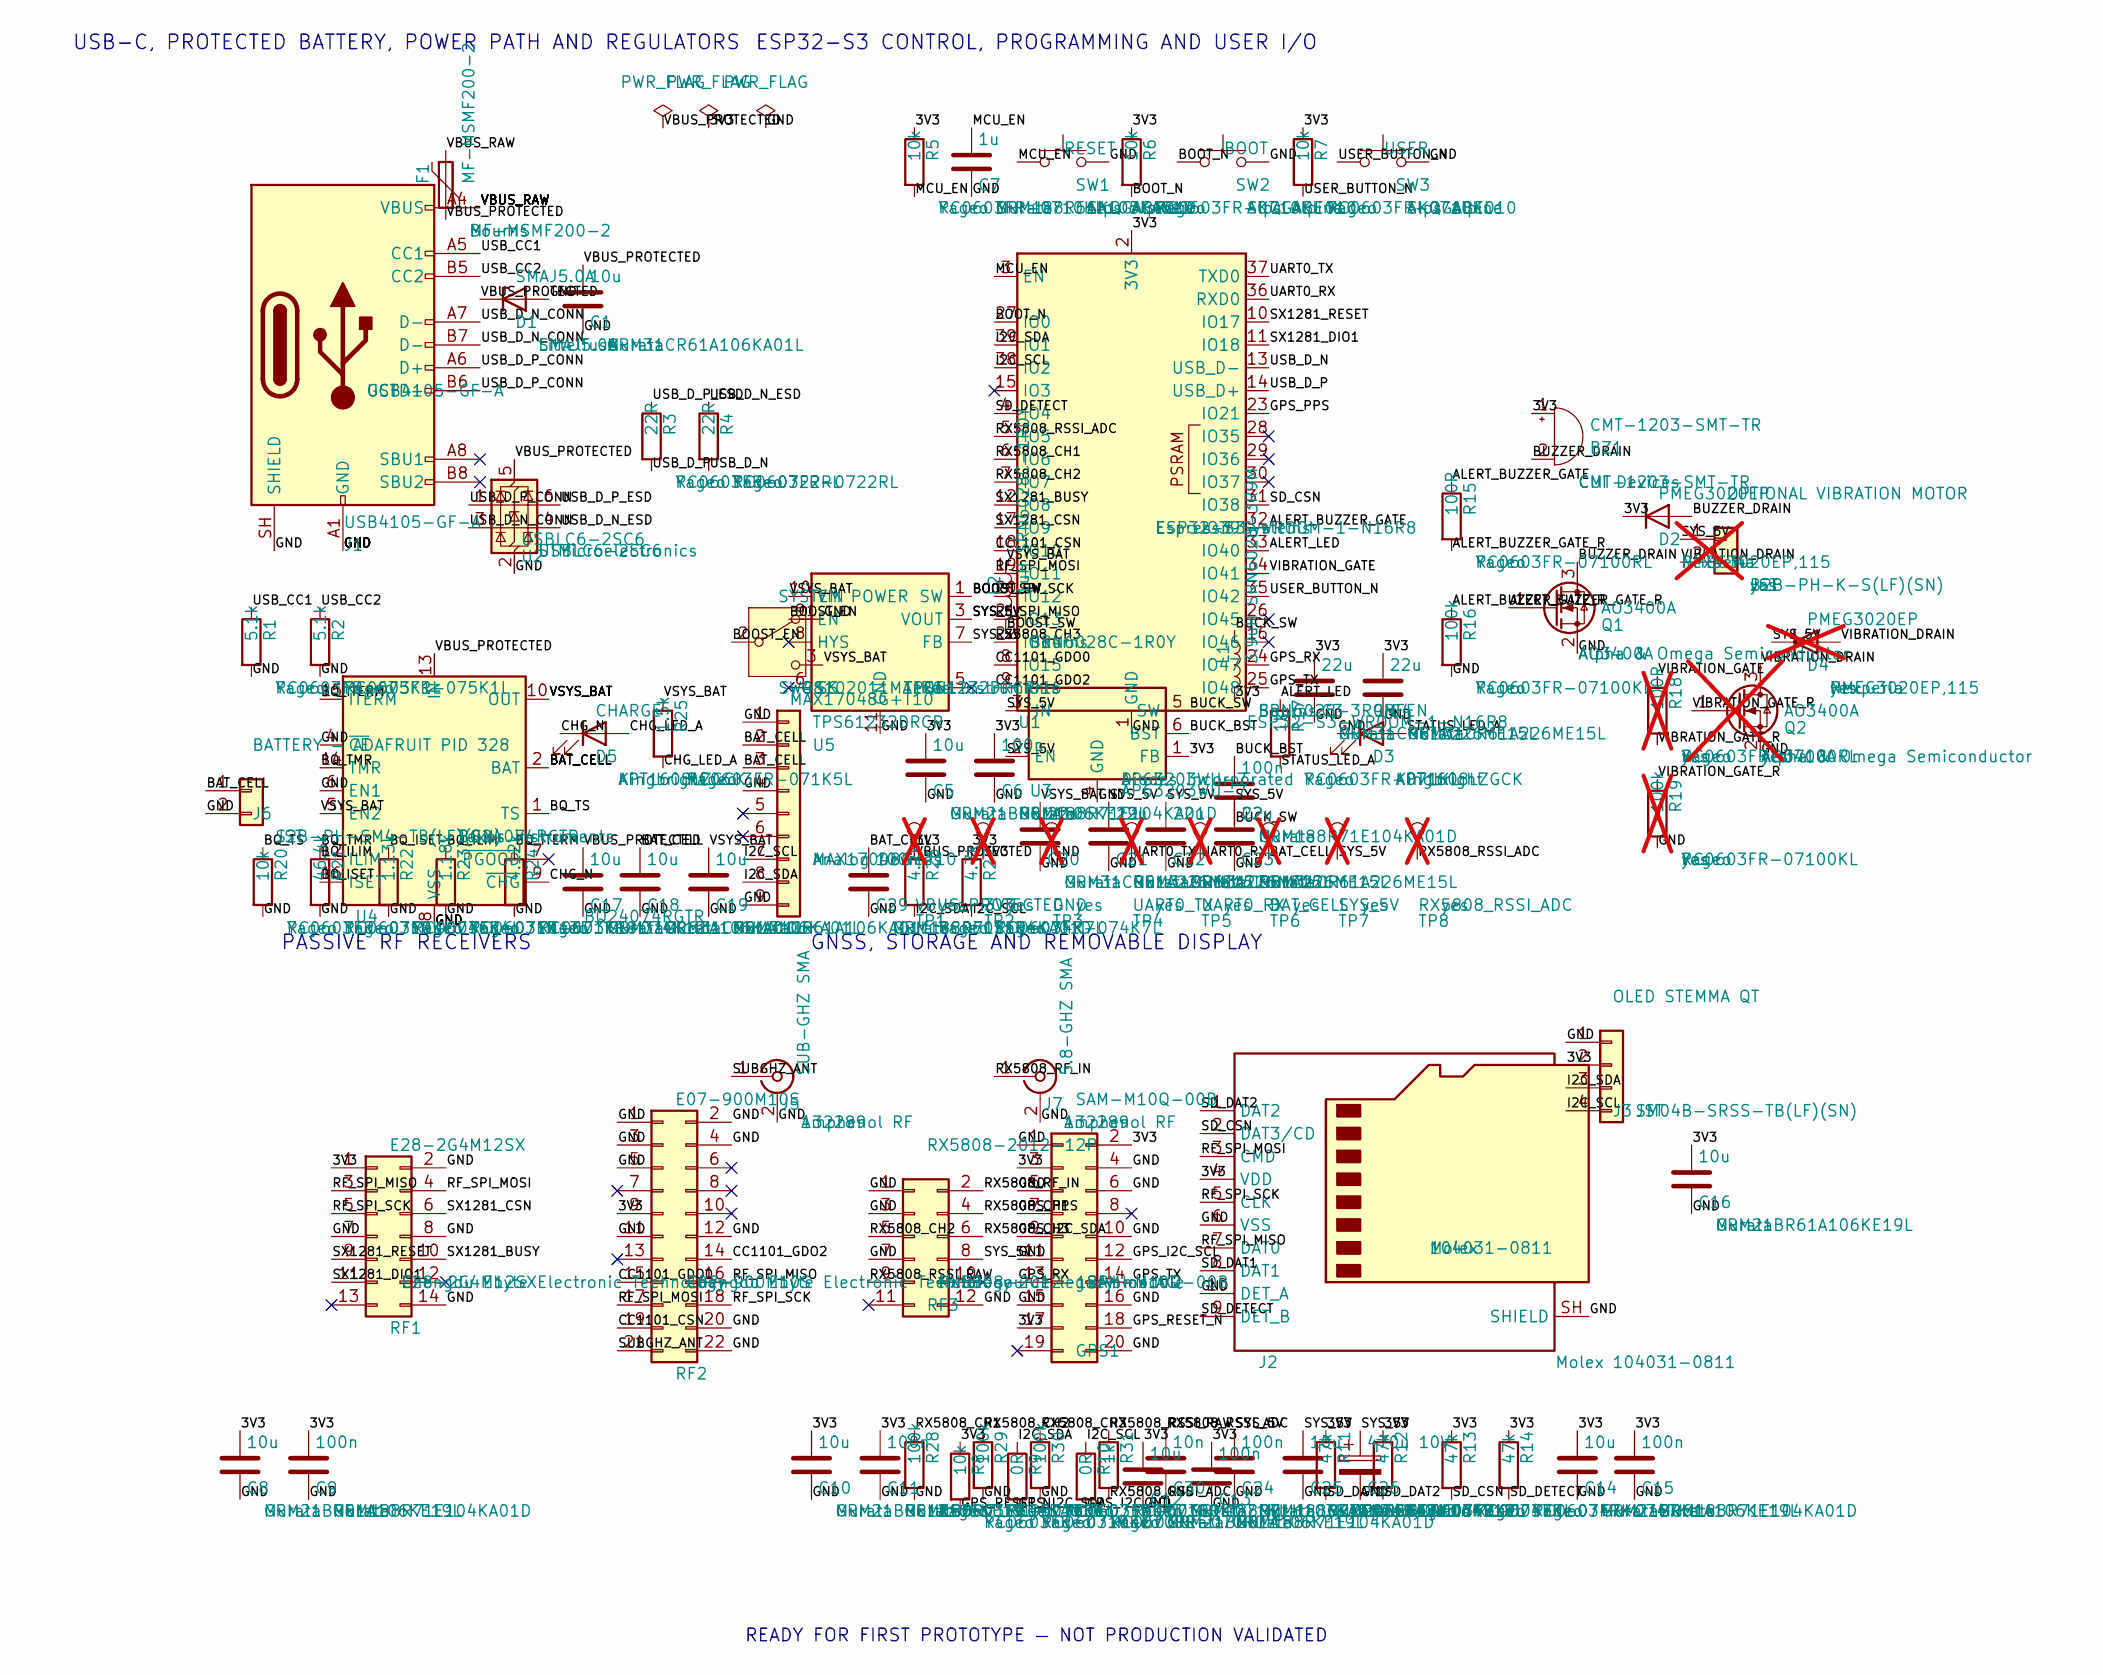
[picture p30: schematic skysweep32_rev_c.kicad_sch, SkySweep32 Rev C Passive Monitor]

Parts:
BZ1: CMT-1203-SMT-TR; Buzzer_CUI_CMT_1203_SMT_TR; MPN CMT-1203-SMT-TR
C1, C17, C18, C19: 10u; C_1206_3216Metric; MPN GRM31CR61A106KA01L
C2, C6, C9, C11, C13, C15, C24, C29: 100n; C_0603_1608Metric; MPN GRM188R71E104KA01D
C3, C4, C20, C21, C22, C23: 22u; C_1206_3216Metric; MPN GRM31CR61A226ME15L
C5, C8, C10, C12, C14, C16, C25: 10u; C_0805_2012Metric; MPN GRM21BR61A106KE19L
C7: 1u; C_0603_1608Metric; MPN GRM188R61A105KA61D
C26: 470u 10V; CP_Elec_10x10; MPN EEE-FK1A471P
C30: 10n; C_0603_1608Metric; MPN GRM188R71H103KA01D
D1: SMAJ5.0A; D_SMA; MPN SMAJ5.0A
D2: PMEG3020EP; D_SOD-128; MPN PMEG3020EP,115
D3: GREEN; LED_0603_1608Metric; MPN APT1608LZGCK
D4: PMEG3020EP; D_SOD-128; MPN PMEG3020EP,115; not fitted
D5: CHARGE; LED_0603_1608Metric; MPN APT1608LZGCK
F1: MF-MSMF200-2; Fuse_1812_4532Metric; MPN MF-MSMF200-2
GPS1: SAM-M10Q-00B; Module_UBlox_SAM_M10Q; MPN SAM-M10Q-00B
J1: USB4105-GF-A; USB_C_Receptacle_GCT_USB4105-xx-A_16P_TopMnt_Horizontal; MPN USB4105-GF-A
J2: Molex 104031-0811; microSD_HC_Molex_104031-0811; MPN 104031-0811
J3: OLED STEMMA QT; JST_SH_SM04B-SRSS-TB_1x04-1MP_P1.00mm_Horizontal; MPN SM04B-SRSS-TB(LF)(SN)
J4: OPTIONAL VIBRATION MOTOR; JST_PH_B2B-PH-K_1x02_P2.00mm_Vertical; MPN B2B-PH-K-S(LF)(SN); not fitted
J5: SUB-GHZ SMA; SMA_Amphenol_132289_EdgeMount; MPN 132289
J6: BATTERY — ADAFRUIT PID 328; JST_PH_S2B-PH-SM4-TB_1x02-1MP_P2.00mm_Horizontal; MPN S2B-PH-SM4-TB(LF)(SN)
J7: 5.8-GHZ SMA; SMA_Amphenol_132289_EdgeMount; MPN 132289
L1: 3.9uH SRN6028-3R9M; L_Bourns-SRN6028; MPN SRN6028-3R9M
L2: 1uH SRN6028C-1R0Y; L_Bourns-SRN6028; MPN SRN6028C-1R0Y
Q1: AO3400A; SOT-23; MPN AO3400A
Q2: AO3400A; SOT-23; MPN AO3400A; not fitted
R1, R2: 5.1k; R_0603_1608Metric; MPN RC0603FR-075K1L
R3, R4: 22R; R_0603_1608Metric; MPN RC0603FR-0722RL
R5, R6, R7, R8, R20: 10k; R_0603_1608Metric; MPN RC0603FR-0710KL
R9, R10: 0R; R_0603_1608Metric; MPN RC0603JR-070RL
R11, R12, R13, R14: 47k; R_0603_1608Metric; MPN RC0603FR-0747KL
R15: 100R; R_0603_1608Metric; MPN RC0603FR-07100RL
R16, R28, R29, R30: 100k; R_0603_1608Metric; MPN RC0603FR-07100KL
R17, R31: 1k; R_0603_1608Metric; MPN RC0603FR-071KL
R18: 100R; R_0603_1608Metric; MPN RC0603FR-07100RL; not fitted
R19: 100k; R_0603_1608Metric; MPN RC0603FR-07100KL; not fitted
R21: 46.4k; R_0603_1608Metric; MPN RC0603FR-0746K4L
R22: 1.13k; R_0603_1608Metric; MPN RC0603FR-071K13L
R23: 1.18k; R_0603_1608Metric; MPN RC0603FR-071K18L
R24: 4.12k; R_0603_1608Metric; MPN RC0603FR-074K12L
R25: 1.5k; R_0603_1608Metric; MPN RC0603FR-071K5L
R26, R27: 4.7k; R_0603_1608Metric; MPN RC0603FR-074K7L
RF1: E28-2G4M12SX; Module_Ebyte_E28_2G4M12SX; MPN E28-2G4M12SX
RF2: E07-900M10S; Module_Ebyte_E07_900M10S; MPN E07-900M10S
RF3: RX5808-2012-12P; Module_RX5808_2012_12P; MPN RX5808-2012-12P
SW1: RESET; SW_SPST_SKQG_WithoutStem; MPN SKQGABE010
SW2: BOOT; SW_SPST_SKQG_WithoutStem; MPN SKQGABE010
SW3: USER; SW_SPST_SKQG_WithoutStem; MPN SKQGABE010
SW4: SYSTEM POWER; SW_Slide_SPDT_Angled_CK_OS102011MA1Q; MPN OS102011MA1QN1
TP1: VBUS_PROTECTED; TestPoint_Pad_D1.0mm; not fitted
TP2: 3V3; TestPoint_Pad_D1.0mm; not fitted
TP3: GND; TestPoint_Pad_D1.0mm; not fitted
TP4: UART0_TX; TestPoint_Pad_D1.0mm; not fitted
TP5: UART0_RX; TestPoint_Pad_D1.0mm; not fitted
TP6: BAT_CELL; TestPoint_Pad_D1.0mm; not fitted
TP7: SYS_5V; TestPoint_Pad_D1.0mm; not fitted
TP8: RX5808_RSSI_ADC; TestPoint_Pad_D1.0mm; not fitted
U1: ESP32-S3-WROOM-1-N16R8; ESP32-S3-WROOM-1; MPN ESP32-S3-WROOM-1-N16R8
U2: USBLC6-2SC6; SOT-23-6; MPN USBLC6-2SC6
U3: AP63203WU-7; TSOT-23-6; MPN AP63203WU-7
U4: BQ24074RGTR; VQFN-16-1EP_3x3mm_P0.5mm_EP1.6x1.6mm; MPN BQ24074RGTR
U5: TPS61232DRCR; Texas_S-PVSON-N10_ThermalVias; MPN TPS61232DRCR
U6: MAX17048G+T10; DFN-8-1EP_2x2mm_P0.5mm_EP0.9x1.3mm; MPN MAX17048G+T10

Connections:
3V3: BZ1.1 (+), C3.1, C4.1, C5.1, C6.1, C8.1, C9.1, C10.1, C11.1, C12.1, C13.1, C14.1, C15.1, C16.1, D2.1 (K), GPS1.2, GPS1.3, GPS1.17, J2.4 (VDD), J3.2, L1.2, R5.1, R6.1, R7.1, R8.1, R11.1, R12.1, R13.1, R14.1, R26.1, R27.1, RF1.1, RF2.9, TP2.1, U1.2 (3V3), U3.1 (FB)
ALERT_BUZZER_GATE: R15.1, U1.32 (IO39)
ALERT_BUZZER_GATE_R: Q1.1 (G), R15.2, R16.1
ALERT_LED: R17.1, U1.33 (IO40)
BAT_CELL: C18.1, C29.1, J6.1, TP6.1, U4.2 (BAT), U4.3 (BAT), U6.2, U6.3
BOOST_EN: SW4.2 (B), U5.9 (EN)
BOOST_SW: L2.2, U5.1 (SW), U5.2 (SW)
BOOT_N: R6.2, SW2.1, U1.27 (IO0)
BQ_ILIM: R23.1, U4.12 (ILIM)
BQ_ISET: R22.1, U4.16 (ISET)
BQ_ITERM: R24.1, U4.15 (ITERM)
BQ_TMR: R21.1, U4.14 (TMR)
BQ_TS: R20.1, U4.1 (TS)
BUCK_BST: C2.1, U3.6 (BST)
BUCK_SW: C2.2, L1.1, U3.5 (SW)
BUZZER_DRAIN: BZ1.2 (-), D2.2 (A), Q1.3 (D)
CC1101_CSN: RF2.19, U1.18 (IO10)
CC1101_GDO0: RF2.15, U1.8 (IO15)
CC1101_GDO2: RF2.14, U1.9 (IO16)
CHG_LED_A: D5.2 (A), R25.2
CHG_N: D5.1 (K), U4.9 (~CHG)
GND: C1.2, C3.2, C4.2, C5.2, C6.2, C7.2, C8.2, C9.2, C10.2, C11.2, C12.2, C13.2, C14.2, C15.2, C16.2, C17.2, C18.2, C19.2, C20.2, C21.2, C22.2, C23.2, C24.2, C25.2, C26.2, C29.2, C30.2, D1.2 (A), D3.1 (K), GPS1.1, GPS1.4, GPS1.5, GPS1.6, GPS1.10, GPS1.11, GPS1.15, GPS1.16, GPS1.20, J1.A1 (GND), J1.A12 (GND), J1.B1 (GND), J1.B12 (GND), J1.SH (SHIELD), J2.6 (VSS), J2.10 (DET_A), J2.SH (SHIELD), J3.1, J5.2 (Ext), J6.2, J7.2 (Ext), Q1.2 (S), Q2.2 (S), R1.2, R2.2, R16.2, R19.2, R20.2, R21.2, R22.2, R23.2, R24.2, R28.2, R29.2, R30.2, RF1.2, RF1.7, RF1.8, RF1.14, RF2.1, RF2.2, RF2.3, RF2.4, RF2.5, RF2.11, RF2.12, RF2.20, RF2.22, RF3.1, RF3.3, RF3.7, RF3.12, SW1.2, SW2.2, SW3.2, SW4.1 (A), TP3.1, U1.1 (GND), U1.40 (GND), U1.41 (GND), U2.2 (GND), U3.4 (GND), U4.4 (~CE), U4.6 (EN1), U4.8 (VSS), U4.17 (VSS), U5.11 (GND), U6.1, U6.4, U6.9
GPS_I2C_SCL: GPS1.12, R10.2
GPS_I2C_SDA: GPS1.9, R9.2
GPS_PPS: GPS1.7, U1.23 (IO21)
GPS_RESET_N: GPS1.18, R8.2
GPS_RX: GPS1.13, U1.24 (IO47)
GPS_TX: GPS1.14, U1.25 (IO48)
I2C_SCL: J3.4, R10.1, R27.2, U1.38 (IO2), U6.7
I2C_SDA: J3.3, R9.1, R26.2, U1.39 (IO1), U6.8
MCU_EN: C7.1, R5.2, SW1.1, U1.3 (EN)
RF_SPI_MISO: J2.7 (DAT0), RF1.3, RF2.16, U1.21 (IO13)
RF_SPI_MOSI: J2.3 (CMD), RF1.4, RF2.17, U1.19 (IO11)
RF_SPI_SCK: J2.5 (CLK), RF1.5, RF2.18, U1.20 (IO12)
RX5808_CH1: R28.1, RF3.4, U1.6 (IO6)
RX5808_CH2: R29.1, RF3.5, U1.7 (IO7)
RX5808_CH3: R30.1, RF3.6, U1.22 (IO14)
RX5808_RF_IN: J7.1 (In), RF3.2
RX5808_RSSI_ADC: C30.1, R31.2, TP8.1, U1.5 (IO5)
RX5808_RSSI_RAW: R31.1, RF3.9
SD_CSN: J2.2 (DAT3/CD), R13.2, U1.31 (IO38)
SD_DAT1: J2.8 (DAT1), R11.2
SD_DAT2: J2.1 (DAT2), R12.2
SD_DETECT: J2.9 (DET_B), R14.2, U1.4 (IO4)
STATUS_LED_A: D3.2 (A), R17.2
SUBGHZ_ANT: J5.1 (In), RF2.21
SX1281_BUSY: RF1.10, U1.12 (IO8)
SX1281_CSN: RF1.6, U1.17 (IO9)
SX1281_DIO1: RF1.11, U1.11 (IO18)
SX1281_RESET: RF1.9, U1.10 (IO17)
SYS_5V: C21.1, C22.1, C23.1, C24.1, C25.1, C26.1, D4.1 (K), J4.1, RF3.8, TP7.1, U3.2 (EN), U3.3 (IN), U5.3 (VOUT), U5.4 (VOUT), U5.7 (FB)
UART0_RX: TP5.1, U1.36 (RXD0)
UART0_TX: TP4.1, U1.37 (TXD0)
USB_CC1: J1.A5 (CC1), R1.1
USB_CC2: J1.B5 (CC2), R2.1
USB_D_N: R4.2, U1.13 (USB_D-)
USB_D_N_CONN: J1.A7 (D-), J1.B7 (D-), U2.3 (I/O2)
USB_D_N_ESD: R4.1, U2.4 (I/O2)
USB_D_P: R3.2, U1.14 (USB_D+)
USB_D_P_CONN: J1.A6 (D+), J1.B6 (D+), U2.1 (I/O1)
USB_D_P_ESD: R3.1, U2.6 (I/O1)
USER_BUTTON_N: R7.2, SW3.1, U1.35 (IO42)
VBUS_PROTECTED: C1.1, C17.1, D1.1 (K), F1.2, TP1.1, U2.5 (VBUS), U4.13 (IN)
VBUS_RAW: F1.1, J1.A4 (VBUS), J1.A9 (VBUS), J1.B4 (VBUS), J1.B9 (VBUS)
VIBRATION_DRAIN: D4.2 (A), J4.2, Q2.3 (D)
VIBRATION_GATE: R18.1, U1.34 (IO41)
VIBRATION_GATE_R: Q2.1 (G), R18.2, R19.1
VSYS_BAT: C19.1, C20.1, L2.1, R25.1, SW4.3 (C), U4.5 (EN2), U4.10 (OUT), U4.11 (OUT), U5.10 (VIN)

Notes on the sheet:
USB-C, PROTECTED BATTERY, POWER PATH AND REGULATORS
ESP32-S3 CONTROL, PROGRAMMING AND USER I/O
PASSIVE RF RECEIVERS
GNSS, STORAGE AND REMOVABLE DISPLAY
READY FOR FIRST PROTOTYPE — NOT PRODUCTION VALIDATED

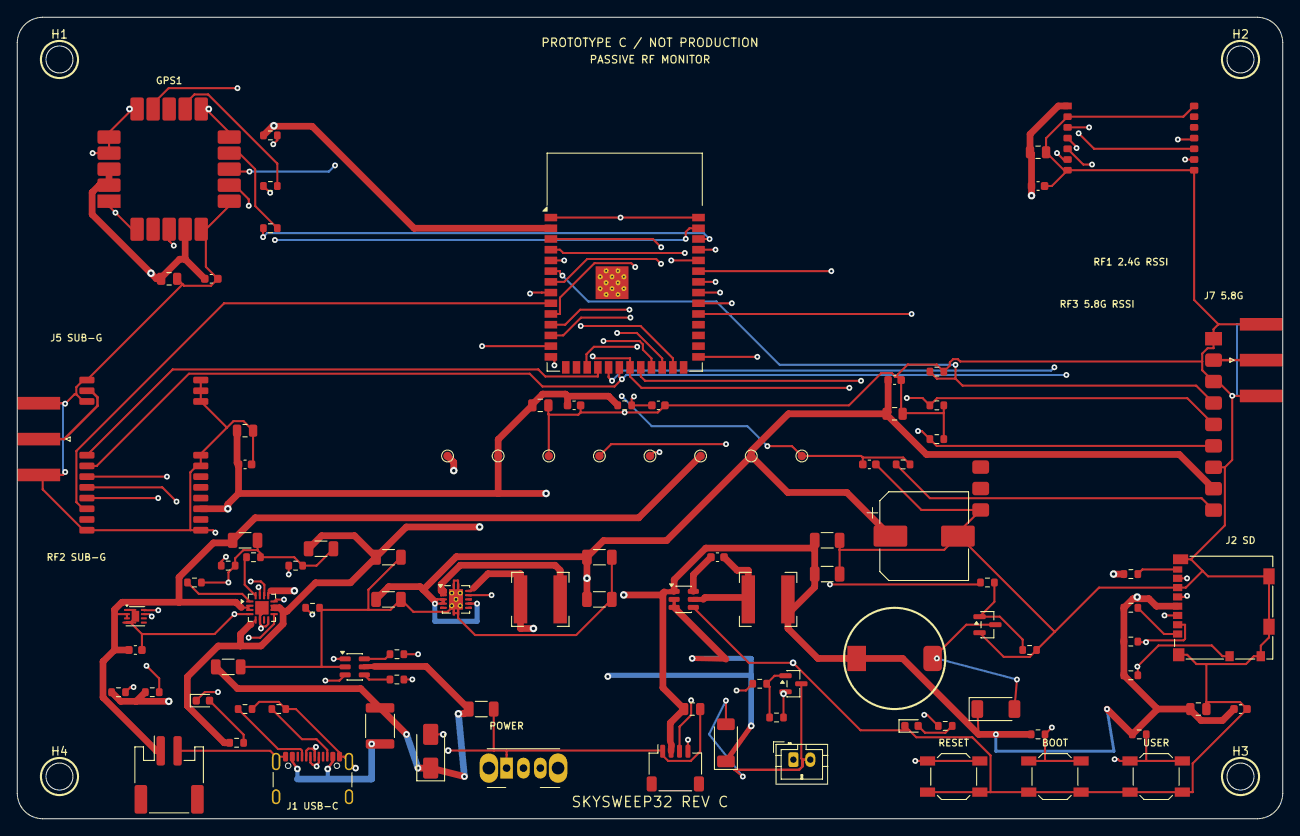
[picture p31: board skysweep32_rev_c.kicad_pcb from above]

Board: 4 copper layers, 150.0 x 95.0 mm, 103 parts (0 on the bottom side), 68 nets.

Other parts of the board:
H1, H2, H3, H4: M3 NPTH / 10mm FASTENER KEEPOUT; MountingHole_M3_5mm_Keepout

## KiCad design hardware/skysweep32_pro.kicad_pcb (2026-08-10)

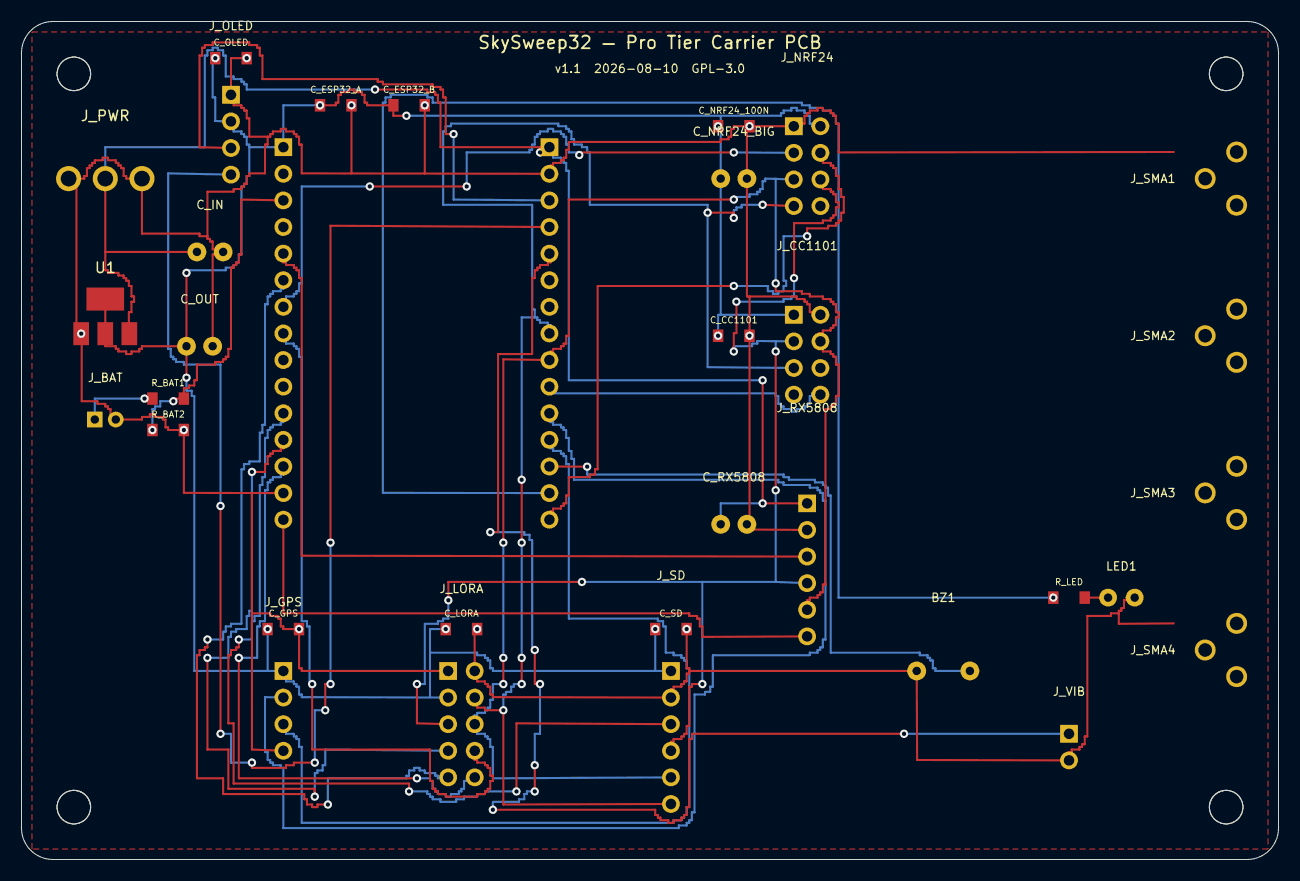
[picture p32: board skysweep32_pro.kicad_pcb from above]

Board: 2 copper layers, 120.0 x 80.0 mm, 38 parts (0 on the bottom side), 26 nets.

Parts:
BZ1: BUZZER; BZ_12x9.5mm
C_CC1101: 100nF; C_0805_2012Metric
C_ESP32_A, C_ESP32_B: 100nF; C_0805_2012Metric
C_GPS: 100nF; C_0805_2012Metric
C_IN: 100uF/16V; CP_Radial_D6.3mm_P2.50mm
C_LORA: 100nF; C_0805_2012Metric
C_NRF24_100N: 100nF; C_0805_2012Metric
C_NRF24_BIG: 10uF/10V; CP_Radial_D6.3mm_P2.50mm
C_OLED: 100nF; C_0805_2012Metric
C_OUT: 10uF/10V; CP_Radial_D6.3mm_P2.50mm
C_RX5808: 100uF/10V; CP_Radial_D6.3mm_P2.50mm
C_SD: 100nF; C_0805_2012Metric
H1, H2, H3, H4: MH_M3; MountingHole_3.2mm_M3
J_BAT: LIPO IN; JST_PH_B2B-PH-K_1x02_P2.00mm_Vertical
J_CC1101: CC1101 900MHz; PinHeader_2x04_P2.54mm_Vertical
J_ESP32_L: ESP32 Left; PinHeader_1x15_P2.54mm_Vertical
J_ESP32_R: ESP32 Right; PinHeader_1x15_P2.54mm_Vertical
J_GPS: GPS NEO-6M; PinHeader_1x04_P2.54mm_Vertical
J_LORA: LoRa SX1276; PinHeader_2x05_P2.54mm_Vertical
J_NRF24: NRF24L01+; PinHeader_2x04_P2.54mm_Vertical
J_OLED: OLED SSD1306; PinHeader_1x04_P2.54mm_Vertical
J_PWR: 5V DC IN; BarrelJack_CUI_PJ-102A_Horizontal
J_RX5808: RX5808 5.8GHz; PinHeader_1x06_P2.54mm_Vertical
J_SD: MicroSD SPI; PinHeader_1x06_P2.54mm_Vertical
J_SMA1: 900MHz CC1101; SMA_Amphenol_132289_EdgeMount
J_SMA2: 2.4GHz NRF24; SMA_Amphenol_132289_EdgeMount
J_SMA3: 5.8GHz RX5808; SMA_Amphenol_132289_EdgeMount
J_SMA4: 915MHz LoRa; SMA_Amphenol_132289_EdgeMount
J_VIB: VIBRATION MOTOR (GPIO0); PinHeader_1x02_P2.54mm_Vertical
LED1: LED_RED; LED_D3.0mm
R_BAT1, R_BAT2: 100k; R_0805_2012Metric
R_LED: 330R; R_0805_2012Metric
U1: AMS1117-3.3; SOT-223-3_TabPin2

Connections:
ALERT_LED: J_ESP32_R.14, R_LED.1
BAT_ADC: J_ESP32_L.3, R_BAT1.2, R_BAT2.1
BAT_VRAW: J_BAT.1, R_BAT1.1
BUZZER: BZ1.1, J_ESP32_R.13
CC_CS: J_CC1101.8, J_ESP32_R.10
GND: BZ1.2, C_CC1101.2, C_ESP32_A.2, C_ESP32_B.2, C_GPS.2, C_IN.2, C_LORA.2, C_NRF24_100N.2, C_NRF24_BIG.2, C_OLED.2, C_OUT.2, C_RX5808.2, C_SD.2, J_BAT.2, J_CC1101.2, J_ESP32_L.14, J_ESP32_R.2, J_GPS.4, J_LORA.1, J_LORA.2, J_NRF24.1, J_OLED.1, J_PWR.2, J_PWR.3, J_RX5808.2, J_SD.2, J_SMA1.2, J_SMA1.3, J_SMA2.2, J_SMA2.3, J_SMA3.2, J_SMA3.3, J_SMA4.2, J_SMA4.3, J_VIB.2, LED1.2, R_BAT2.2, U1.1
GPS_RX: J_ESP32_R.12, J_GPS.3
GPS_TX: J_ESP32_R.11, J_GPS.2
I2C_SCL: J_ESP32_R.3, J_OLED.3
I2C_SDA: J_ESP32_R.4, J_OLED.4
LED_ANODE: LED1.1, R_LED.2
LORA_CS: J_ESP32_L.12, J_LORA.7
LORA_DIO0: J_ESP32_L.8, J_LORA.8
LORA_DIO1: J_ESP32_L.6, J_LORA.9
LORA_RST: J_ESP32_L.13, J_LORA.10
NRF_CE: J_ESP32_L.7, J_NRF24.3
NRF_CS: J_ESP32_R.15, J_NRF24.4
RX_CS: J_ESP32_L.15, J_RX5808.6
RX_RSSI: J_ESP32_L.5, J_RX5808.3
SD_CS: J_ESP32_L.11, J_SD.3
SPI_MISO: J_CC1101.5, J_ESP32_R.8, J_LORA.4, J_NRF24.7, J_SD.6
SPI_MOSI: J_CC1101.3, J_LORA.5, J_NRF24.6, J_RX5808.4, J_SD.4
SPI_SCK: J_CC1101.4, J_ESP32_R.9, J_LORA.6, J_NRF24.5, J_RX5808.5, J_SD.5
VCC_3V3: C_CC1101.1, C_ESP32_A.1, C_ESP32_B.1, C_GPS.1, C_LORA.1, C_NRF24_100N.1, C_NRF24_BIG.1, C_OLED.1, C_OUT.1, C_SD.1, J_CC1101.1, J_ESP32_L.1, J_GPS.1, J_LORA.3, J_NRF24.2, J_OLED.2, J_SD.1, U1.2, U1.4
VCC_5V: C_IN.1, C_RX5808.1, J_ESP32_R.1, J_PWR.1, J_RX5808.1, U1.3
VIBRATION: J_ESP32_R.5, J_VIB.1

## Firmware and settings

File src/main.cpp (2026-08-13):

#include <Arduino.h>
#include <SPI.h>
#include <Wire.h>
#include <U8g2lib.h>
#include <esp_task_wdt.h>

#include "activity_classifier.h"
#include "alert_manager.h"
#include "config.h"
#include "config_manager.h"
#include "data_logger.h"
#include "drivers/cc1101.h"
#include "drivers/rx5808.h"
#include "drivers/sx1281.h"
#include "espnow_mesh.h"
#include "gps_module.h"
#include "power_manager.h"
#include "remote_id_detector.h"
#include "spi_manager.h"
#include "web_server.h"

namespace {

constexpr uint8_t kReceiverCount = 3;
constexpr uint8_t kSubGhzReceiver = 0;
constexpr uint8_t kTwoPointFourReceiver = 1;
constexpr uint8_t kFivePointEightReceiver = 2;

struct RFModuleData {
    const char* name;
    int rssi;
    bool active;
};

U8G2_SSD1306_128X64_NONAME_F_HW_I2C display(
    U8G2_R0, U8X8_PIN_NONE, PIN_I2C_SCL, PIN_I2C_SDA);
CC1101Driver cc1101(PIN_CC1101_CS);
SX1281Driver sx1281;
RX5808Driver rx5808(PIN_RX5808_CH1, PIN_RX5808_CH2, PIN_RX5808_CH3,
                    PIN_RX5808_RSSI);
ActivityClassifier activityClassifier;
#if defined(MODULE_REMOTE_ID) && ENABLE_EXPERIMENTAL_REMOTE_ID
RemoteIDDetector remoteIDDetector;
#endif
SkySweepWebServer webServer;
DataLogger dataLogger;
GPSModule gpsModule;

volatile RFModuleData receivers[kReceiverCount] = {
    {"855-925", 0, false},
    {"2.4 GHz", 0, false},
    {"5.8 GHz", 0, false},
};

TaskHandle_t rfTask = nullptr;
TaskHandle_t displayTask = nullptr;
TaskHandle_t webTask = nullptr;
TaskHandle_t gpsTask = nullptr;

int readReceiverRssi(uint8_t receiver) {
    if (receiver == kFivePointEightReceiver) {
        return constrain(rx5808.scanNextChannel(), 0, 100);
    }

    if (!spiManager.acquire(pdMS_TO_TICKS(100))) {
        return 0;
    }

    int rssi = 0;
    if (receiver == kSubGhzReceiver) {
        rssi = map(cc1101.readRSSI(), -120, -30, 0, 100);
    } else if (receiver == kTwoPointFourReceiver) {
        rssi = sx1281.readRSSI();
    }
    spiManager.release();
    return constrain(rssi, 0, 100);
}

float receiverFrequencyMHz(uint8_t receiver) {
    if (receiver == kSubGhzReceiver) {
        return static_cast<float>(cc1101.getFrequency()) / 1000000.0f;
    }
    if (receiver == kTwoPointFourReceiver) {
        return sx1281.getCurrentFrequencyMHz();
    }
    return rx5808.getCurrentFrequency();
}

void taskRFScanning(void*) {
    Serial.println("[TASK] RF scanning started");
    uint8_t sweepCounter = 0;

    for (;;) {
        for (uint8_t receiver = 0; receiver < kReceiverCount; ++receiver) {
            receivers[receiver].rssi = readReceiverRssi(receiver);
            receivers[receiver].active = receivers[receiver].rssi > 40;

            // This is relative receiver activity only. It never identifies a
            // transmitter, protocol, range, intent, or aircraft.
            const ActivityLevel activity =
                activityClassifier.assessActivity(receiver, receivers[receiver].rssi);
            if (activity >= ACTIVITY_MEDIUM) {
                const AlertType alert = activity == ACTIVITY_CRITICAL
                                            ? ALERT_ACTIVITY_CRITICAL
                                            : activity == ACTIVITY_HIGH
                                                  ? ALERT_ACTIVITY_HIGH
                                                  : ALERT_ACTIVITY_MEDIUM;
                if (alertManager.getCurrentAlert() < alert ||
                    alertManager.getCurrentAlert() == ALERT_NONE) {
                    alertManager.alert(alert);
                }
            }

            if (activity >= ACTIVITY_HIGH) {
                // No protocol or transmitter identity is sent between nodes.
                espNowMesh.sendActivityAlert(receivers[receiver].rssi,
                                              receiver == kSubGhzReceiver ? 2 : receiver == kTwoPointFourReceiver ? 3 : 4,
                                              static_cast<uint8_t>(activity), 0.0f, 0.0f);
            }

            webServer.broadcastRFData(receivers[receiver].name, receivers[receiver].rssi,
                                      receivers[receiver].active);
            if (receivers[receiver].active) {
                dataLogger.logRFData(receivers[receiver].name, receivers[receiver].rssi,
                                     receiverFrequencyMHz(receiver), "energy");
            }
        }

        const ActivityData current = activityClassifier.getCurrentActivity();
        const char* source = current.isActive && current.moduleIndex < kReceiverCount
                                 ? receivers[current.moduleIndex].name
                                 : "All fitted receivers";
        webServer.broadcastActivityLevel(
            activityClassifier.getActivityLevelString(current.level), source);

        // The fitted E07 / CC1101 path remains within the Rev C 855–925 MHz
        // contract. It deliberately does not re-enable the legacy 433 MHz scan.
        if (++sweepCounter == 10) {
            sweepCounter = 0;
            if (spiManager.acquire(pdMS_TO_TICKS(100))) {
                const CC1101Driver::BandScanResult scan = cc1101.scanAllBands(5);
                spiManager.release();
                for (uint8_t band = 0; band < CC1101Driver::BAND_COUNT; ++band) {
                    if (scan.activity[band]) {
                        Serial.printf("[SWEEP] sample %u RSSI=%d\n", band,
                                      scan.rssi[band]);
                    }
                }
            }
        }

        powerManager.update();
        vTaskDelay(pdMS_TO_TICKS(configManager.get().rfScanIntervalMs));
    }
}

void taskDisplayUpdate(void*) {
    Serial.println("[TASK] Display update started");
    bool previousStealth = false;

    for (;;) {
        const bool stealth = configManager.get().stealthMode;
        if (stealth != previousStealth) {
            display.setPowerSave(stealth ? 1 : 0);
            previousStealth = stealth;
        }
        if (!stealth) {
            display.clearBuffer();
            display.setFont(u8g2_font_6x10_tr);
            display.drawStr(0, 10, "SkySweep32 Rev C");
            display.drawLine(0, 12, 128, 12);
            display.setFont(u8g2_font_5x7_tr);
            for (uint8_t receiver = 0; receiver < kReceiverCount; ++receiver) {
                const int y = 24 + receiver * 11;
                char row[28];
                snprintf(row, sizeof(row), "%s: %d", receivers[receiver].name,
                         receivers[receiver].rssi);
                display.drawStr(0, y, row);
                display.drawFrame(70, y - 7, 57, 8);
                const int width = map(receivers[receiver].rssi, 0, 100, 0, 55);
                if (width > 0) display.drawBox(71, y - 6, width, 6);
            }
            const ActivityData activity = activityClassifier.getCurrentActivity();
            if (activity.isActive) {
                char row[32];
                snprintf(row, sizeof(row), "ACTIVITY: %s",
                         activityClassifier.getActivityLevelString(activity.level));
                display.drawStr(0, 63, row);
            } else if (gpsModule.isFixValid()) {
                const GPSData gps = gpsModule.getData();
                char row[32];
                snprintf(row, sizeof(row), "GNSS: %d sat", gps.satellites);
                display.drawStr(0, 63, row);
            } else {
                display.drawStr(0, 63, "Scanning...");
            }
            display.sendBuffer();
        }
        vTaskDelay(pdMS_TO_TICKS(configManager.get().displayUpdateMs));
    }
}

void taskWebServer(void*) {
    Serial.println("[TASK] Web server started");
    for (;;) {
        webServer.update();
        vTaskDelay(pdMS_TO_TICKS(100));
    }
}

#if defined(MODULE_REMOTE_ID) && ENABLE_EXPERIMENTAL_REMOTE_ID
void taskRemoteID(void*) {
    Serial.println("[TASK] Experimental Remote ID scanning started");
    for (;;) {
        remoteIDDetector.update();
        const uint8_t count = remoteIDDetector.getDetectedDroneCount();
        for (uint8_t index = 0; index < count; ++index) {
            const DroneRemoteIDData report = remoteIDDetector.getDroneData(index);
            if (report.isValid) {
                webServer.broadcastDroneDetection(report.uasID, report.latitude,
                                                  report.longitude, report.altitude);
                dataLogger.logDroneRemoteID(report.uasID, report.latitude,
                                             report.longitude, report.altitude,
                                             report.rssi);
            }
        }
        vTaskDelay(pdMS_TO_TICKS(1000));
    }
}
#endif

void taskGPS(void*) {
    Serial.println("[TASK] GNSS polling started");
    for (;;) {
        gpsModule.update();
        vTaskDelay(pdMS_TO_TICKS(100));
    }
}

void beginReceiver(const char* name, bool initialized) {
    Serial.printf("[INIT] %s: %s\n", name, initialized ? "ready" : "failed");
}
void showInitialNetworkCredentials() {
    if (!configManager.networkCredentialsWereGenerated()) return;
    const RuntimeConfig& network = configManager.get();
    display.clearBuffer();
    display.setFont(u8g2_font_5x7_tr);
    display.drawStr(0, 10, "New AP credentials");
    display.drawStr(0, 25, network.wifiSSID);
    display.drawStr(0, 40, network.wifiPassword);
    display.drawStr(0, 55, "Serial has a copy");
    display.sendBuffer();
    delay(5000);
}


}  // namespace

void setup() {
    Serial.begin(115200);
    delay(1000);
    Serial.printf("\nSkySweep32 Rev C passive monitor %s (%s)\n", SKYSWEEP_VERSION,
                  SKYSWEEP_BUILD_DATE);
    Serial.println("Relative RF energy/activity observation only; no transmitter identity.");

    const bool configReady = configManager.begin();
    esp_task_wdt_init(30, true);
    esp_task_wdt_add(nullptr);

    Wire.begin(PIN_I2C_SDA, PIN_I2C_SCL);
    powerManager.begin();
    spiManager.begin();

    display.begin();
    display.clearBuffer();
    display.setFont(u8g2_font_6x10_tr);
    display.drawStr(0, 10, "SkySweep32");
    display.drawStr(0, 25, "Initializing...");
    display.sendBuffer();
    showInitialNetworkCredentials();
    if (spiManager.acquire(pdMS_TO_TICKS(1000))) {
        beginReceiver("CC1101 855-925 MHz", cc1101.begin());
        spiManager.release();
    }
    if (spiManager.acquire(pdMS_TO_TICKS(1000))) {
        beginReceiver("SX1281 2.4 GHz", sx1281.begin());
        spiManager.release();
    }
    beginReceiver("RX5808 5.8 GHz", rx5808.begin());

    alertManager.begin(true, true);
    if (configReady && webServer.begin()) {
        Serial.printf("[WEB] %s\n", webServer.getIPAddress().toString().c_str());
    } else if (!configReady) {
        Serial.println("[INIT] Web server disabled: configuration storage unavailable");
    } else {
        Serial.println("[INIT] Web server failed");
    }
    if (!espNowMesh.begin()) Serial.println("[INIT] ESP-NOW failed");
#if defined(MODULE_REMOTE_ID) && ENABLE_EXPERIMENTAL_REMOTE_ID
    if (!remoteIDDetector.begin()) Serial.println("[INIT] Experimental Remote ID failed");
#endif
    if (!dataLogger.begin(PIN_SD_CS)) Serial.println("[INIT] microSD unavailable");
    if (!gpsModule.begin()) Serial.println("[INIT] GNSS unavailable");

    xTaskCreatePinnedToCore(taskRFScanning, "RF_Scan", TASK_STACK_RF_SCAN, nullptr,
                            TASK_PRIORITY_RF_SCAN, &rfTask, 0);
    xTaskCreatePinnedToCore(taskDisplayUpdate, "Display", TASK_STACK_DISPLAY, nullptr,
                            TASK_PRIORITY_DISPLAY, &displayTask, 1);
    xTaskCreatePinnedToCore(taskWebServer, "Web", TASK_STACK_WEBSERVER, nullptr,
                            TASK_PRIORITY_WEBSERVER, &webTask, 1);
#if defined(MODULE_REMOTE_ID) && ENABLE_EXPERIMENTAL_REMOTE_ID
    xTaskCreatePinnedToCore(taskRemoteID, "RemoteID", TASK_STACK_REMOTE_ID, nullptr,
                            TASK_PRIORITY_REMOTE_ID, nullptr, 0);
#endif
    xTaskCreatePinnedToCore(taskGPS, "GNSS", TASK_STACK_GPS, nullptr,
                            TASK_PRIORITY_GPS, &gpsTask, 1);

    Serial.printf("[SYSTEM] Free heap: %d bytes\n", ESP.getFreeHeap());
}

void loop() {
    esp_task_wdt_reset();
    alertManager.update();
    espNowMesh.update();
    vTaskDelay(pdMS_TO_TICKS(10));
}

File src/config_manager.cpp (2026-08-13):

#include "config_manager.h"

#include <esp_system.h>

ConfigManager configManager;

namespace {
constexpr char kCredentialAlphabet[] =
    "ABCDEFGHJKLMNPQRSTUVWXYZabcdefghijkmnopqrstuvwxyz23456789";
constexpr size_t kApPasswordLength = 16;
constexpr char kRetiredPublicSsid[] = "SkySweep32";

bool copyBounded(char* destination, size_t destinationSize, const char* source) {
    if (!source || strnlen(source, destinationSize) >= destinationSize) return false;
    strlcpy(destination, source, destinationSize);
    return true;
}
}  // namespace


ConfigManager::ConfigManager() : spiffsReady(false), networkCredentialsGenerated(false) {
    setDefaults();
}

void ConfigManager::setDefaults() {
    cfg.wifiSSID[0] = '\0';
    cfg.wifiPassword[0] = '\0';
    cfg.wifiChannel = WIFI_AP_CHANNEL;
    cfg.rssiThresholdLow = RSSI_THRESHOLD_LOW;
    cfg.rssiThresholdMedium = RSSI_THRESHOLD_MEDIUM;
    cfg.rssiThresholdHigh = RSSI_THRESHOLD_HIGH;
    cfg.rssiThresholdCritical = RSSI_THRESHOLD_CRITICAL;
    cfg.rfScanIntervalMs = RF_SCAN_INTERVAL_MS;
    cfg.displayUpdateMs = DISPLAY_UPDATE_INTERVAL_MS;
    cfg.bleScanIntervalMs = BLE_SCAN_INTERVAL_MS;
    cfg.gpsUpdateIntervalMs = GPS_UPDATE_INTERVAL;
    cfg.logLevel = 1;
    cfg.maxLogSizeMB = MAX_LOG_SIZE_MB;
    cfg.stealthMode = false;
}

void ConfigManager::generateNetworkCredentials() {
    const uint64_t mac = ESP.getEfuseMac();
    snprintf(cfg.wifiSSID, sizeof(cfg.wifiSSID), "%s-%04llX", WIFI_AP_SSID_PREFIX,
             static_cast<unsigned long long>(mac & 0xffffULL));
    for (size_t index = 0; index < kApPasswordLength; ++index) {
        cfg.wifiPassword[index] =
            kCredentialAlphabet[esp_random() % (sizeof(kCredentialAlphabet) - 1)];
    }
    cfg.wifiPassword[kApPasswordLength] = '\0';
    networkCredentialsGenerated = true;
}

bool ConfigManager::validateNetworkConfig(const RuntimeConfig& candidate) const {
    const size_t ssidLength = strnlen(candidate.wifiSSID, sizeof(candidate.wifiSSID));
    const size_t passwordLength =
        strnlen(candidate.wifiPassword, sizeof(candidate.wifiPassword));
    return ssidLength >= 1 && ssidLength < sizeof(candidate.wifiSSID) &&
           passwordLength >= 8 && passwordLength < sizeof(candidate.wifiPassword) &&
           candidate.wifiChannel >= 1 && candidate.wifiChannel <= 13;
}

bool ConfigManager::begin() {
    if (!SPIFFS.begin(true)) {
        Serial.println("[CONFIG] SPIFFS mount failed");
        spiffsReady = false;
        return false;
    }

    spiffsReady = true;
    Serial.printf("[CONFIG] SPIFFS: %u KB used / %u KB total\n",
                  SPIFFS.usedBytes() / 1024, SPIFFS.totalBytes() / 1024);
    if (SPIFFS.exists(CONFIG_FILE) && load()) {
        Serial.println("[CONFIG] Loaded saved configuration");
        return true;
    }

    setDefaults();
    generateNetworkCredentials();
    if (!save()) return false;
    Serial.println("[CONFIG] Generated first-boot AP credentials");
    Serial.printf("[CONFIG] AP SSID: %s\n", cfg.wifiSSID);
    Serial.printf("[CONFIG] AP password: %s\n", cfg.wifiPassword);
    return true;
}

bool ConfigManager::load() {
    if (!spiffsReady) return false;
    File file = SPIFFS.open(CONFIG_FILE, "r");
    if (!file) return false;

    JsonDocument doc;
    const DeserializationError error = deserializeJson(doc, file);
    file.close();
    if (error || !doc.is<JsonObject>()) return false;

    RuntimeConfig loaded = cfg;
    const JsonVariantConst wifi = doc["wifi"];
    if (!wifi.is<JsonObject>()) return false;
    const JsonObjectConst wifiObject = wifi.as<JsonObjectConst>();
    const JsonVariantConst ssid = wifiObject["ssid"];
    const JsonVariantConst password = wifiObject["password"];
    const JsonVariantConst channel = wifiObject["channel"];
    if (!ssid.is<const char*>() || !password.is<const char*>() || !channel.is<int>()) {
        return false;
    }
    if (!copyBounded(loaded.wifiSSID, sizeof(loaded.wifiSSID), ssid.as<const char*>()) ||
        !copyBounded(loaded.wifiPassword, sizeof(loaded.wifiPassword),
                     password.as<const char*>())) {
        return false;
    }
    const int configuredChannel = channel.as<int>();
    if (configuredChannel < 1 || configuredChannel > 13) return false;
    loaded.wifiChannel = static_cast<uint8_t>(configuredChannel);

    if (!doc["thresholds"]["low"].isNull()) loaded.rssiThresholdLow = doc["thresholds"]["low"];
    if (!doc["thresholds"]["medium"].isNull()) loaded.rssiThresholdMedium = doc["thresholds"]["medium"];
    if (!doc["thresholds"]["high"].isNull()) loaded.rssiThresholdHigh = doc["thresholds"]["high"];
    if (!doc["thresholds"]["critical"].isNull()) loaded.rssiThresholdCritical = doc["thresholds"]["critical"];
    if (!doc["rfScanMs"].isNull()) loaded.rfScanIntervalMs = doc["rfScanMs"];
    if (!doc["displayMs"].isNull()) loaded.displayUpdateMs = doc["displayMs"];
    if (!doc["bleScanMs"].isNull()) loaded.bleScanIntervalMs = doc["bleScanMs"];
    if (!doc["gpsUpdateMs"].isNull()) loaded.gpsUpdateIntervalMs = doc["gpsUpdateMs"];
    if (!doc["logLevel"].isNull()) loaded.logLevel = doc["logLevel"];
    if (!doc["maxLogMB"].isNull()) loaded.maxLogSizeMB = doc["maxLogMB"];
    if (!doc["stealthMode"].isNull()) loaded.stealthMode = doc["stealthMode"];

    if (!validateNetworkConfig(loaded)) return false;
    cfg = loaded;
    if (strcmp(cfg.wifiSSID, kRetiredPublicSsid) == 0) {
        generateNetworkCredentials();
        return save();
    }
    return true;
}

bool ConfigManager::save() {
    if (!spiffsReady) return false;
    File file = SPIFFS.open(CONFIG_FILE, "w");
    if (!file) return false;

    JsonDocument doc;
    doc["wifi"]["ssid"] = cfg.wifiSSID;
    doc["wifi"]["password"] = cfg.wifiPassword;
    doc["wifi"]["channel"] = cfg.wifiChannel;
    doc["thresholds"]["low"] = cfg.rssiThresholdLow;
    doc["thresholds"]["medium"] = cfg.rssiThresholdMedium;
    doc["thresholds"]["high"] = cfg.rssiThresholdHigh;
    doc["thresholds"]["critical"] = cfg.rssiThresholdCritical;
    doc["rfScanMs"] = cfg.rfScanIntervalMs;
    doc["displayMs"] = cfg.displayUpdateMs;
    doc["bleScanMs"] = cfg.bleScanIntervalMs;
    doc["gpsUpdateMs"] = cfg.gpsUpdateIntervalMs;
    doc["logLevel"] = cfg.logLevel;
    doc["maxLogMB"] = cfg.maxLogSizeMB;
    doc["stealthMode"] = cfg.stealthMode;
    const size_t written = serializeJsonPretty(doc, file);
    file.close();
    Serial.printf("[CONFIG] Saved (%u bytes)\n", written);
    return written > 0;
}

bool ConfigManager::reset() {
    if (!spiffsReady) return false;
    networkCredentialsGenerated = false;
    // Keep the active credential in RAM until reboot so this authenticated
    // request cannot weaken management access before the new AP is generated.
    // The next boot has no file and therefore creates/displays a new secret.
    return !SPIFFS.exists(CONFIG_FILE) || SPIFFS.remove(CONFIG_FILE);
}
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

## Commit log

2026-06-09 docs: update hardware BOM with search links and fix LoRa/DAC/I2S pinout docs
2026-06-09 feat: add stunning GitHub Pages landing page and auto-deploy workflow
2026-06-09 chore: add root .nojekyll and clean brackets in docs watermark
2026-06-09 fix: include SD.h in web_server.cpp when MODULE_SD_CARD is defined to fix pro tier build error
    [web_server.cpp]
2026-06-09 feat: complete LoRa mesh triangulation math, check off TODO, and redesign landing page to premium slate style
2026-06-12 fix: compilation errors and deprecated ADC macros
    [main.cpp, power_manager.cpp]
2026-07-16 feat(hardware): add Pro Tier carrier PCB and Sentinel enclosure (closes #2)
    - hardware/skysweep32_pro.kicad_pcb: KiCad 6 PCB project (120x80mm, 2-layer)
    * ESP32 DevKit V1 socket (2x15 header)
    * NRF24L01+ / CC1101 / RX5808 / OLED / GPS / LoRa SX1276 / MicroSD connectors
    * AMS1117-3.3V LDO with decoupling caps on every module
    * 4x edge-mount SMA connectors (900/2.4/5.8/915MHz)
    * DC barrel jack + JST-PH LiPo connector + battery voltage divider
    * LED + buzzer + 4x M3 NPTH mounting holes
    * 24 named nets, full silkscreen
    - hardware/enclosures/skysweep32_pro_case_bottom.stl: Sentinel bottom shell
    * 126x86x32mm, 3mm walls, 4x M3 brass insert standoffs
    * USB cutout, 8x ventilation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
    [skysweep32_pro.kicad_pcb, skysweep32_pro_case_bottom.stl, skysweep32_pro_case_lid.stl]
2026-07-16 docs: link PCB and enclosure files in README
2026-07-16 docs: add Russian PCB and Enclosure guides, update landing page
2026-07-26 Fix runtime thresholds, unify versions, and harden build/CI
    Firmware:
    - assessThreat() now reads RSSI thresholds from ConfigManager instead of the
    compile-time RSSI_THRESHOLD_* macros, so /api/calibrate and /api/config
    threshold changes actually affect threat detection (previously no-ops).
    - Replace duplicated #ifndef MODULE_* guard blocks in the RF-scan and display
    tasks with a single rfModuleEnabled() helper (behavior unchanged).
    Versions:
    - Unify firmware/version references to 0.6.0 (config.h, TODO.md) to match the
    changelog; bump the release-builder default to 0.6.0.
    - Fix broken flash instructions in the EN/RU "Start from Zero" guides that
    pointed at a non-existent v0.5.0 bin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
    [main.cpp]
2026-07-26 Fix parser/network buffer-safety bugs and correctness issues from audit
    Security (attacker-controlled RF/BLE/network input):
    - CRSF parser: a 0xFE/0xFF length byte wrapped uint8_t expectedLength to 0/1
    and memcpy'd up to ~252 bytes into the 60-byte payload buffer. Range-validate
    the length, widen expectedLength, and read the CRC at the correct offset.
    - Remote ID BLE: parsers read fixed offsets (to byte 22) from variable-length
    service data after only a length<2 check. Add per-type minimum-length guards.
    - ESP-NOW: recv callback only checked len>=4 before dereferencing union payloads
    at offset 8+. Validate header + per-type payload length before handling.
    - Web /api/logs/download: re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
    [cc1101.cpp, espnow_mesh.cpp, gps_module.cpp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]
2026-07-26 Add host-compiled parser unit tests (ASan/UBSan) + CI
    The CRSF and MAVLink parsers decode attacker-controlled RF input, so they are
    the highest-value code to test for memory safety. They depend only on stdint
    types and mem* routines, so they build against a minimal Arduino.h stub with a
    desktop compiler — no ESP32 toolchain or PlatformIO registry required.
    - test/host/: Arduino.h stub, test_parsers.cpp, Makefile, README.
    Compiles the real src/protocols/*.cpp with AddressSanitizer + UBSan.
    17 assertions covering: CRSF hostile length bytes (0xFE/0xFF) and over-max
    payloads rejected without overflow, valid frame round-trip (CRC-offset and
    frame-length fixes); MAVLink valid heartbeat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
2026-07-26 Expand host parser tests: CRSF RC round-trip + parse-helper bounds
    Adds 9 more assertions (26 total), all host-verified with ASan/UBSan:
    - CRSF RC-channel build->parse round-trip, exercising the 11-bit pack/unpack
    and confirming the frame validates end to end.
    - CRSF parseGPS and MAVLink parseGPS decode full payloads and return zeroed
    structs on short (out-of-bounds) payloads.
    - MAVLink parseHeartbeat field extraction on a full payload.
    signal_database was considered but its translation unit pulls in SPIFFS +
    ArduinoJson + String, so it isn't cleanly host-compilable; left out rather
    than stubbing a large surface.
    Verified locally: 26 passed, 0 failed.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
2026-07-26 Add deterministic fuzz pass over CRSF/MAVLink parsers
    The parsers decode attacker-controlled RF, so fuzzing them under sanitizers is
    high-value and fully host-verifiable. Adds a seeded (reproducible) fuzz stage:
    ~300k unstructured bytes through long-lived parsers plus ~160k structured frames
    (valid sync + random length byte hitting every boundary, incl. 0xFE/0xFF) into
    fresh parsers. AddressSanitizer/UBSan turn any out-of-bounds access into a hard
    failure, so a clean run proves the buffer-safety fixes hold against arbitrary input.
    Verified locally: 27 passed, 0 failed in <1s. Reverting the CRSF length fix makes
    the fuzz abort under ASan (memcpy overflow), so the pass is meaningful.
    Test-on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
2026-07-26 Add cppcheck static-analysis gate + fix warnings it flagged
    - .github/workflows/host-tests.yml (renamed "Host Tests & Static Analysis"):
    new job runs cppcheck --enable=warning over the full feature set with
    --error-exitcode=1. Uses the runner's system cppcheck, so it needs no
    PlatformIO registry (works independently of the firmware build).
    - Fixes for every warning it reported:
    - data_logger: %lu logged a uint32_t timestamp -> cast to unsigned long.
    - Fully initialize the ATAK (multicastPort), CRSF/MAVLink (rxBuffer) and
    Acoustic (goertzelFilters/audioBuffer) constructors.
    - GPSModule: deleted copy ctor/operator= (it owns a raw HardwareSerial*).
    Verified locally: full-featur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
    [data_logger.cpp]
2026-07-26 docs: refresh architecture tree, document /api/calibrate, add testing docs
    - README (EN + RU): rewrote the src/ architecture tree to list all current
    modules (was 4 of ~20) and added a Testing section covering test/host + cppcheck.
    - docs/{en,ru}/software.md: documented the /api/calibrate endpoint (implemented
    in web_server.cpp but previously absent from the API reference).
    - CONTRIBUTING.md: added a "Running tests locally" guide and asked contributors
    to add test/host cases for parser/pure-logic changes.
    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
2026-07-26 Refactor hardware generators (portable/CLI/headless) + site & docs
    None of the three hardware generators could run anywhere but the original
    author's machine — every output path was hardcoded to f:/Projects/skysweep32/... .
    This makes them portable and cleans up the code, with no change to the artifacts.
    build_kicad.py:
    - Output path derived from the script location; argparse (-o / --stdout).
    - Split into build_pcb()/main(); shared emit-helpers (fp_ref/fp_val/fp_rect/
    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
2026-08-10 release: v0.6.1
    [skysweep32_pro.kicad_pcb, skysweep32_pro_case_bottom.stl]
2026-08-10 fix: render actual PCB routes in preview
2026-08-10 docs(hardware): mark existing PCB as unverified prototype
2026-08-10 refactor(hardware): make Rev B manifest authoritative
    [hardware_manifest.yaml]
2026-08-10 feat(hardware): finalize SkySweep32 Pro Rev B carrier PCB and Sentinel enclosure
    - Synthesize native KiCad 10 schematic skysweep32_pro_rev_b.kicad_sch (0 ERC errors)
    - Synthesize native 4-layer KiCad 10 PCB skysweep32_pro_rev_b.kicad_pcb (0 physical shorts, 0 keepout violations, 0 edge violations)
    - Complete automated track routing via Freerouting 1.9.0 and zone refills
    - Generate 7 module STEP 3D models and full assembly STEP skysweep32_pro_rev_b.step
    - Model Sentinel Enclosure Rev B (STEP/STL) in FreeCAD with verified CAD fit and manifold solids
    - Verify PlatformIO esp32s3_rev_b_pro firmware compilation against hardware_manifest.yaml
    - Add comprehensive Manufacturing and Assembly Guide (MA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
    [Adafruit_GPS_PID746.step, Adafruit_MicroSD_PID254.step, Adafruit_RFM95W_PID3072.step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]
2026-08-10 feat(hardware): add 3D CAD enclosure previews and clean up silkscreen designators
    - Render 3D Sentinel Enclosure Rev B previews (preview_enclosure_iso.png and preview_enclosure_interior.png) via FreeCAD and Matplotlib
    - Clean component reference silkscreen designators (hide 0603/0805 passives ref text, format IC/module text) to prevent silk-over-copper overlaps
    - Re-render PCB 3D previews with verified 3D STEP models
    - Export combined Sentinel CAD assembly STEP skysweep32_pro_sentinel_assembly.step
    [skysweep32_pro_rev_b.kicad_pcb, skysweep32_pro_rev_b_base.kicad_pcb, skysweep32_pro_sentinel_assembly.step]
2026-08-11 feat(hardware): define canonical Rev C passive architecture
    [Adafruit_OLED_PID326_ENVELOPE.step, Bourns_MF_MSMF200_2_ENVELOPE.step, Bourns_SRN6028_3R9M_ENVELOPE.step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]
2026-08-11 feat(hardware): add routed Rev C PCB and matched enclosure
    [assembly_items.csv, bom.csv, bom_fitted.csv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]
2026-08-11 feat(firmware): bind Rev C pin contract and verification gates
2026-08-11 docs(hardware): publish truthful Rev C prototype handoff
2026-08-11 chore(hardware): refresh Rev C evidence from clean source
    [Adafruit_OLED_PID326_ENVELOPE.step, Bourns_MF_MSMF200_2_ENVELOPE.step, Bourns_SRN6028_3R9M_ENVELOPE.step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]
2026-08-12 fix(hardware): close Rev C prototype review gaps
    [ADI_MAX17048_TDFN8_ENVELOPE.step, Adafruit_OLED_PID326_ENVELOPE.step, Adafruit_PID328_LP785060_BATTERY_ENVELOPE.step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]
2026-08-12 chore(hardware): refresh clean Rev C evidence
    [ADI_MAX17048_TDFN8_ENVELOPE.step, Adafruit_OLED_PID326_ENVELOPE.step, Adafruit_PID328_LP785060_BATTERY_ENVELOPE.step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]
2026-08-12 fix(ci): keep passive policy and legacy builds aligned
    [main.cpp]
2026-08-12 fix(firmware): gate ESP-NOW transmission by profile
    [espnow_mesh.cpp, main.cpp]
2026-08-12 fix(hardware): correct Rev C electrical integration
    [ADI_MAX17048_TDFN8_ENVELOPE.step, Adafruit_OLED_PID326_ENVELOPE.step, Adafruit_PID328_LP785060_BATTERY_ENVELOPE.step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]
2026-08-12 chore(hardware): record clean Rev C verification
    [ADI_MAX17048_TDFN8_ENVELOPE.step, Adafruit_OLED_PID326_ENVELOPE.step, Adafruit_PID328_LP785060_BATTERY_ENVELOPE.step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]
2026-08-12 fix(build): validate dashboard content portably
    [generate_dashboard.py]
2026-08-13 hardware: publish reviewed Rev C engineering package
    [01_power.kicad_sch, 02_control_and_alerts.kicad_sch, 03_rf_2g4_subghz.kicad_sch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]
2026-08-13 refactor: establish a coherent Rev C product baseline (#16)
    * refactor: establish Rev C product baseline
    * fix: verify canonical documentation routes
    [Adafruit_GPS_PID746.step, Adafruit_MicroSD_PID254.step, Adafruit_RFM95W_PID3072.step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]
2026-08-13 security: close Prototype #1 web and trust blockers (#17)
    * security: remove unauthenticated OTA from canonical Rev C
    * firmware: make network and power runtime state truthful
    * docs: repair canonical Rev C verification commands
    * ci: restore host test path trigger

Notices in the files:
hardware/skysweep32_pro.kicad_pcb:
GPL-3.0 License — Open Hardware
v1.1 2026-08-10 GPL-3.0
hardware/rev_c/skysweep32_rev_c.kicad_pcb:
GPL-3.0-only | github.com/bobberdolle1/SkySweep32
